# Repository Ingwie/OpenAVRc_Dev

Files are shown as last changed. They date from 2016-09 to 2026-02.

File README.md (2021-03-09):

# OpenAVRc_Dev
This is the source code / documentation part of OpenAVRc. For hardware / addons visit : https://github.com/Ingwie/OpenAVRc_Hw 

**Welcome to**
=========
                 ____                ___ _   _____                      
                / __ \___  ___ ___  / _ | | / / _ \____                 
               / /_/ / _ \/ -_) _ \/ __ | |/ / , _/ __/                 
               \____/ .__/\__/_//_/_/ |_|___/_/|_|\__/                  
                   /_/                                                  
              
              =========================================
----------
                     Based on code(s) named :                       
             OpenTx - https://github.com/opentx/opentx                  
             Deviation - https://www.deviationtx.com/                   
                                                                        
                Only AVR code here for visibility ;-)                   
----------
   OpenAVRc is free software: you can redistribute it and/or modify    
   it under the terms of the GNU General Public License as published    
   by the Free Software Foundation, either version 2 of the License,   
   or (at your option) any later version.

   OpenAVRc is distributed in the hope that it will be useful,         
   but WITHOUT ANY WARRANTY; without even the implied warranty of       
   MERCHANTABILITY or FITNESS FOR A PARTICULAR PURPOSE.  See the        
   GNU General Public License for more details.                         
                                                                        
>        License GPLv2: http://www.gnu.org/licenses/gpl-2.0.html          

----------

   Stay tuned

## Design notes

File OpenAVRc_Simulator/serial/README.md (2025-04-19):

# uart

code interface between std function and user for Windows and Linux

## Warning:
After many docs read, i think you should never read msdn, and never do something with Windows, but i did it.

## Example:
```C
#include "lib/uart/uart.h"

int main ( void )
{
	uartHandler uart = 0; // uart handler
	char busName[ 64 ] = { 0 }; // bus name /dev/ttyACMx or COMx
	uint8_t buffer[  1024 ] = { 0 }; // buffer for data

	...
		
	uart = uartOpen ( busName, O_RDWR );

	if ( !uartValide( uart ) )
	{
		printf ( "can't open %s\n", busName );
		return ( __LINE__ );
	}

	uartWrite ( uart, buffer, bufferSizeMax );

	uartRead ( uart, buffer, bufferSizeMax );

	uartClose ( uart );

	return ( 0 );
}
```

## Polling read:
```C
#include "lib/uart/uart.h"

int main ( void )
{
	uint8_t buf[ 256 ] = { 0 };
	char busName[ 64 ] = { 0 }; // bus name /dev/ttyACMx or COMx

	...

	uartHandler uart = uartOpen ( busName, O_RDWR );

	if ( !uartValide ( uart ) )
	{
		return ( __LINE__ );
	}

	if ( uartInit ( uart, 115200, UART_DATA_8 | UART_PARITY_N | UART_STOP_1 ) )
	{
		return( __LINE__ );
	}

	// set non blocking read mode
	uartSetReadTimeout ( uart, 0, 0 );

	do
	{
		if ( uartRead ( uart, buf, 1 ) )
		{ // if read a byte
			printf ( "%x\n", *buf );
		}

		Sleep ( 10 );
	}
	while ( 1 );

	uartClose ( uart );

	return ( 0 );
}
```

For Windows in the function `int uartSetReadTimeout ( uartHandler bus, uint8_t time, uint8_t min );` 
 - if you want a non blocking mode: set time and min to zero,
 - if you want a timed mode: set time upper than zero and min to zero, 
 - if you want a blocking mode: set time to zero and min to 1

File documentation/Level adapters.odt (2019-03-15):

Wiring Adapters SPI

Version 0.1

Copyright OpenAVRc 2018

# 1 Document version

Version | Date | Reason for update
0.1 | 11/10/2018 | Creation

# 2 Copyright

This document is Copyright © 2018 OpenAVRc.

# 3 Caution

The OpenAVRc team is not responsible for damages that may arise from the misuse or possible malfunction of the OpenAVRc transmitter.

It is therefore up to the end user to measure, assume the risks and comply with the legislation in force depending on the country of use.

# 4 Table of content

## 5 Modules HF :

### 5.1 Module HF cc2500 yellow:

If you only use FrSky receivers, prefer the following CC2500 module or equivalent.

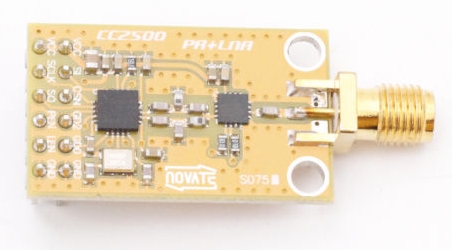
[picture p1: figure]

Yellow cc2500 HF Module Wiring :

The input outputs only accept 3.3v signals. It is ESSENTIAL to separate this module from the Core using a 4-channel converter (MOSI, MISO, CS, SCLCK) which receives 0-5v level signals and converts them into 0-3,3v level signals. and vice versa for the MISO signal.

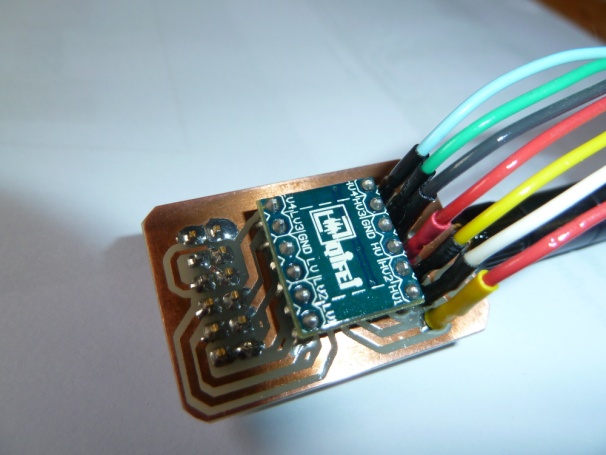
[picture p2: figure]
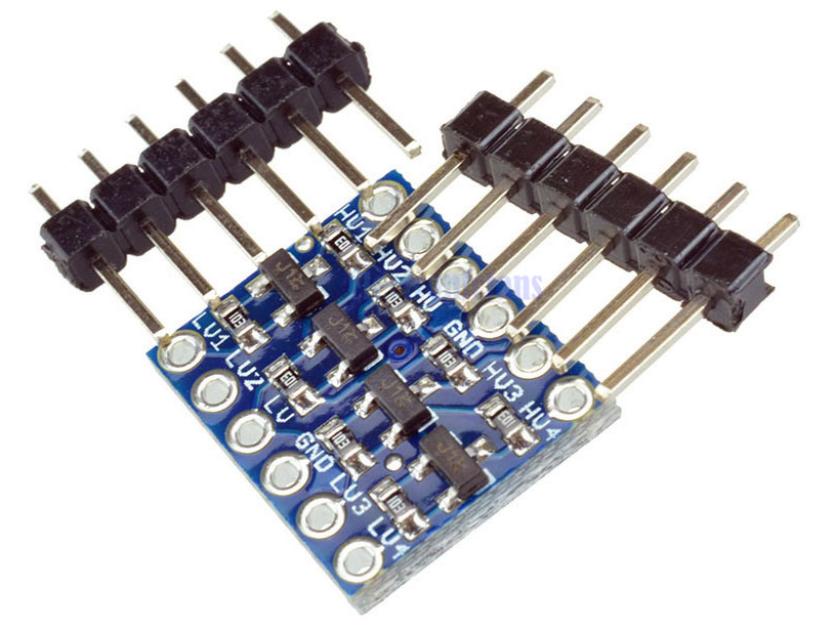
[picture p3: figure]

This circuit board will allow adaptation in a reduced format. It is connected to P7 (see p14).

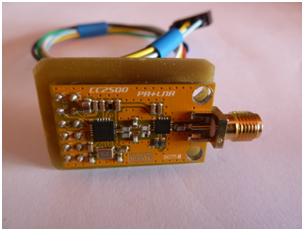
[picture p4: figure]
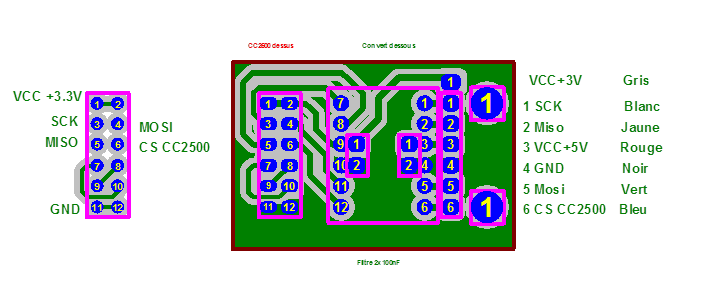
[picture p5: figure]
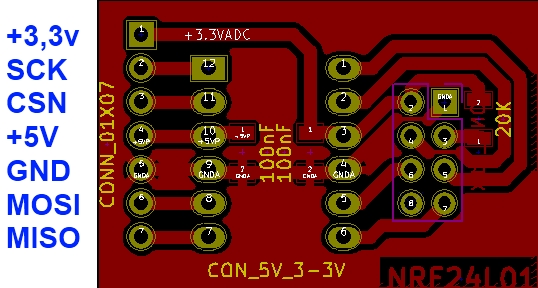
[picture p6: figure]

### 5.2 Module HF nrf24l01 :

### 5.3 Module HF a7105 :

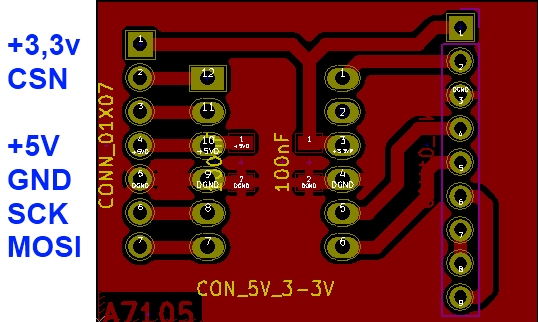
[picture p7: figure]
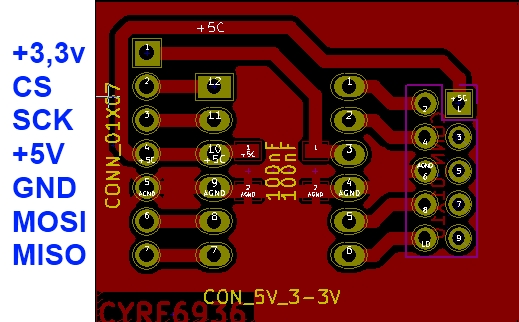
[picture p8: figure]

### 5.4 Module HF cyrf6936:

La documentation de LibreOffice est disponible sur www.libreoffice.org

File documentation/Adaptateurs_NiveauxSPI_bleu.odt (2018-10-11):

Câblage Adaptateurs SPI

Version 0.1

Copyright OpenAVRc 2018

# 1 Version du document

Version | Date | Raison de l’évolution
0.1 | 11/10/2018 | Création

# 2 Copyright

Ce document est Copyright © 2018 OpenAVRc.

# 3 Avertissement

L’équipe OpenAVRc n’est aucunement responsable des dommages qui pourraient découler de la mauvaise utilisation ou d’un éventuel dysfonctionnement de l’émetteur OpenAVRc.

Il appartient donc à l’utilisateur final d’en mesurer, d’en assumer les risques et de respecter la législation en vigueur selon le pays d’utilisation.

# 4 Tâble des matières

## 5 Modules HF :

### 5.1 Module HF cc2500 jaune :

Si vous n’utilisez que des récepteurs FrSky, préférez le module CC2500 suivant ou un équivalent.


Câblage du module HF cc2500 jaune :

Les entrées sorties n’acceptent que des signaux 3,3v. Il est donc IMPERATIF de séparer ce module du Core à l’aide d’un convertisseur 4 voies (MOSI, MISO, CS, SCLCK) qui reçoit des signaux de niveaux 0-5v et les convertit en signaux de niveaux 0-3,3v et inversement pour le signal MISO.


Ce circuit imprimé permettra l’adaptation sous un format réduit. Il est connecté sur P7 (voir p14).


### 5.2 Module HF nrf24l01 :

### 5.3 Module HF a7105 :


### 5.4 Module HF cyrf6936:

La documentation de LibreOffice est disponible sur www.libreoffice.org

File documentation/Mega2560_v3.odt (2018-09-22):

Document de câblage d’une carte Arduino mega2560 R3

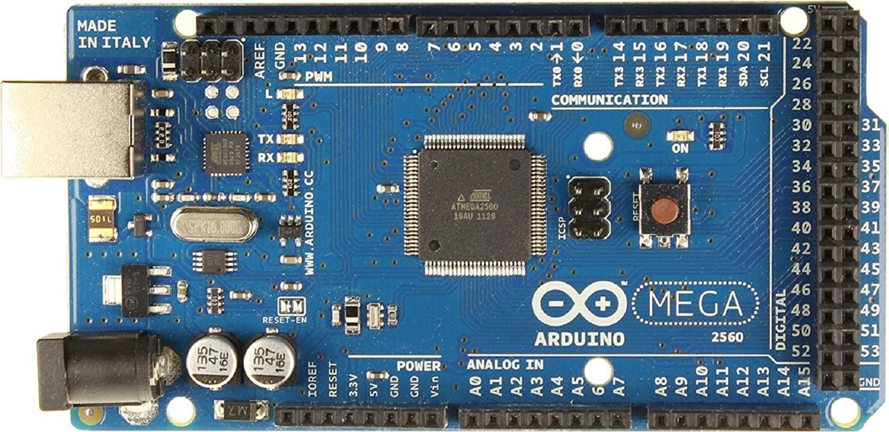
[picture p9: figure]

Table des matières

### Affectations des connecteurs:

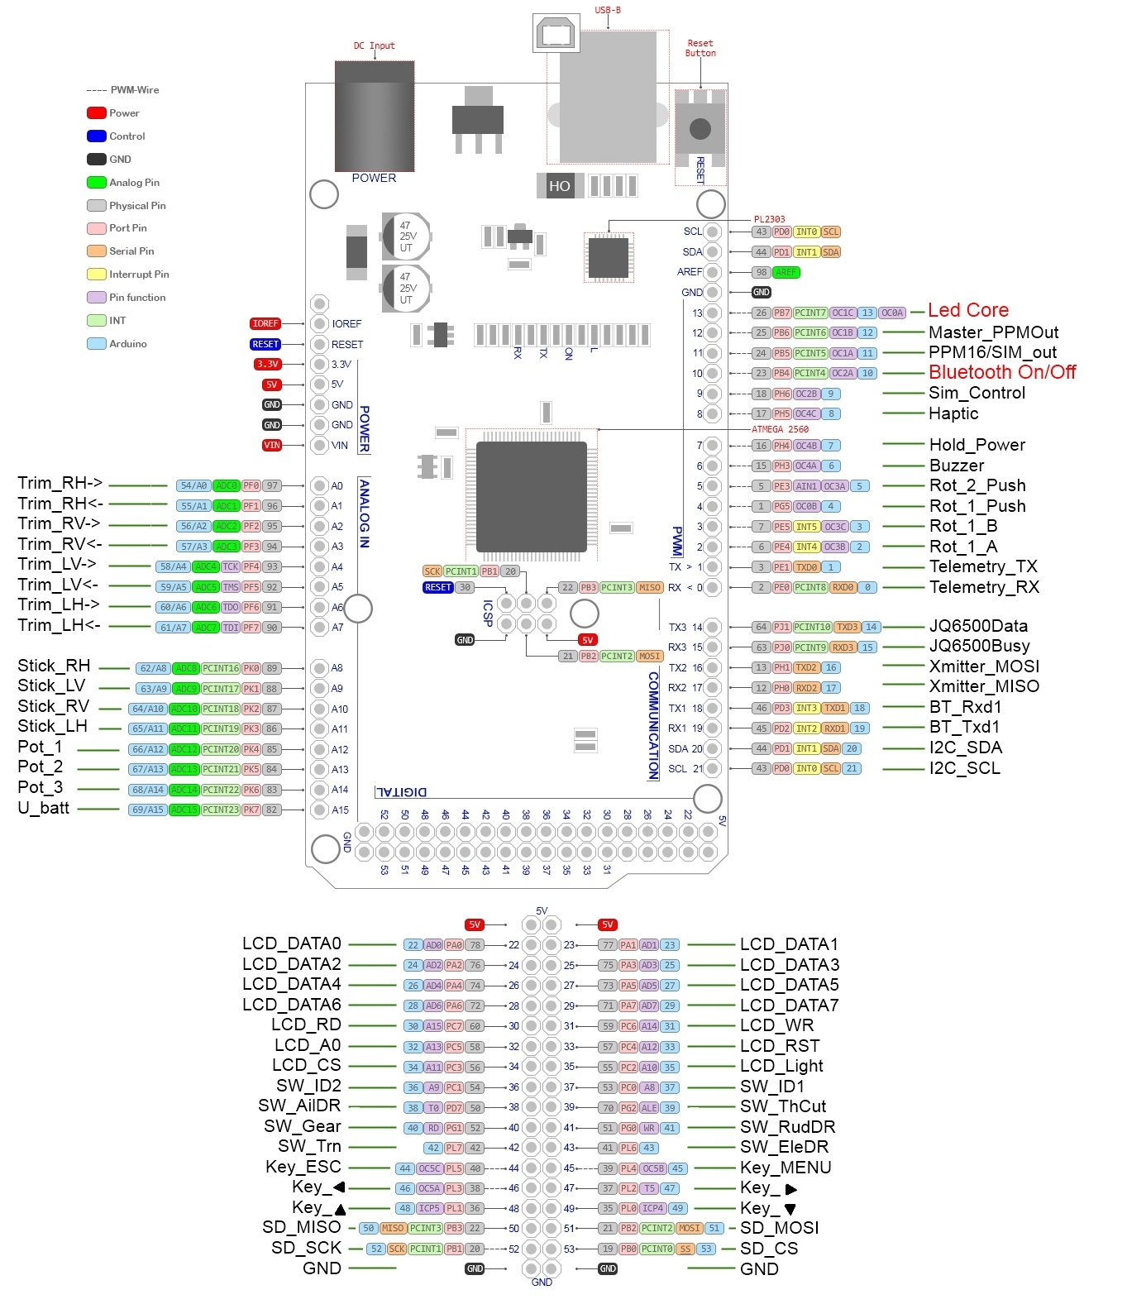
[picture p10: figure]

### Câblage des connecteurs :

#### Manches :

Les quatre manches sont connectés aux pins A8,A9,A10 et A11, ainsi que le +5v et la masse GND.

Les manches à effet hall seront alimentés par du 3,3v au lieu du 5V.

#### Potentiomètres P1 , P2 et P3 :

Les trois potentiomètres sont connectés aux pins A12,A13 et A14.

#### Ecran LCD parallèle ST7920 :

L’écran est connecté sur les pins 22 à 35 .

Pour tout autre écran connecté en parallèle, Zolen, Artronic, KS108, voir en fin de document .

#### Connecteur ICSP :

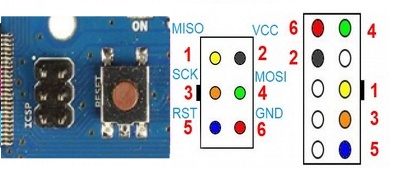
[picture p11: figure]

#### Connexion des Trims :

Les trims sont connectés sur les pins A0 à A7 et la masse GND.

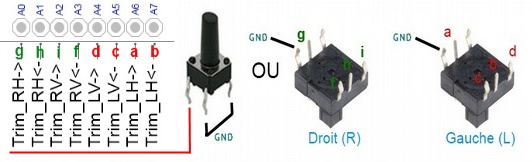
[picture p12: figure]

#### Connexion des Interrupteurs :

Les interrupteurs sont connectés sur les pins 36 à 43 et la masse GND.

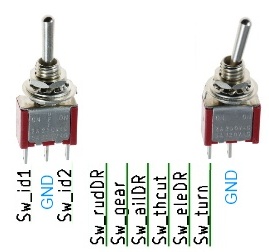
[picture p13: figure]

#### Alimentation (LIPO) :

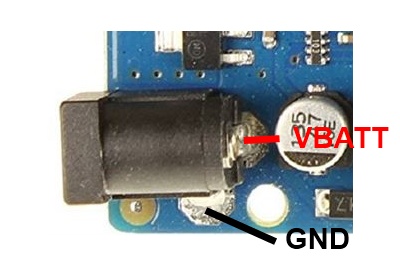
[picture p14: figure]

Un accus LiPo ou mieux : Li-Ion 2S type (2 x 4,2v maximum) sera utilisé pour alimenter la carte.

VBATT alimente aussi le module HF.

Un pont diviseur de tension doit être câblé entre VBATT et GND. Son point milieu devra être connecté à la pin A15.

#### Connexion des touches :

Les touches sont connectées sur les pins 44 à 49 et la masse GND.

#### Connecteur Marche-Arrêt, télémesure et sortie PPM vers module HF:

#### Connexion carte SD (8GB maximum):

La carte SD est connectée sur les pins 50 à 53 ainsi que sur le +5V et la masse GND.

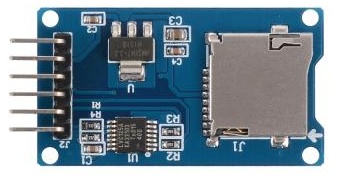
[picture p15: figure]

#### Connexion encodeurs :

Seul l’encodeur Ena est disponible pour l’instant. Il est connecté sur les pins 2,3,5 et GND.

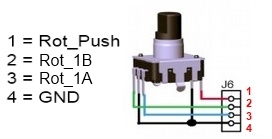
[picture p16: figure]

#### Connexion du vibreur :

Le vibreur est connecté sur la pin 8 et la masse GND.

Comme pour tout moteur continu, il faut absolument câbler une diode de type 1n4148 en parallèle sur le vibreur . La cathode sur la sortie 8 et l’anode sur le GND.

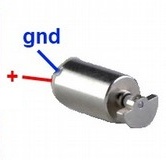
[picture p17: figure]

#### Connexion écran LCD_I2C : (SSD1306 ou SH1106)

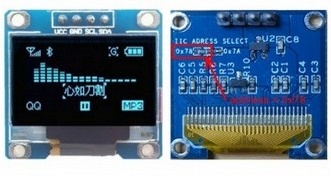
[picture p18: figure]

En cas d’utilisation d’un écran I2C, il sera connecté sur les pins 20 (sda) et 21 (scl) ainsi que sur le +5V et la masse GND.

Vérifier que l'adresse de l'écran est bien 0x78 (correspond à l’adresse d’écriture 0x3C )!!!

#### Câblage module télémétrie, conversion TTL/RS232 :

#### Connexion amplification Audio-Buzzer / Voice :

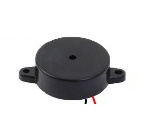
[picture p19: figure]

Il existe deux possibilités d’utilisation de la pin 6 (Out Audio-Buzzer).

- soit raccorder directement un buzzer entre la pin 6 et la masse GND et désactiver la fonction « Audio » dans « Desktop ».

Dans ce cas, le buzzer sera utilisé pour signaler toute action effectuée sur une touche ou indiquer une alarme, selon la configuration choisie dans la radio pour cette fonction.

- soit utiliser la fonction « Audio » dans « Desktop et raccorder la pin 6 sur l’une des deux entrées d’un ampli 2w décrit plus loin, et dont le circuit imprimé est illustré par ailleurs.

Ce mode d’utilisation est, à notre avis, le plus judicieux,

Dans ce cas, la pin 6 génère un signal Buzzer simulé ainsi que les sons de la fonction « Audio » provoqués par l’appui sur une touche, une commande de trim, etc, selon le choix effectué dans la radio.

Dans tous les cas, si la fonction « Voice » est cochée dans « Desktop » (annonces vocales par fonction « Voice »), voir plus bas le câblage du module Voice JQ6500 .

Ampli sommateur

Il faudra réaliser un montage sommateur des signaux Audio-Buzzer / Voice avant amplification des signaux vers un haut-parleur 8 ohms.

Si vous ne souhaitez pas profiter de la fonction « Audio » et utiliser un buzzer seul, («Audio» décoché dans Desktop), tout en utilisant la fonction Voice («Voice» coché dans Desktop), seul le raccordement au JQ ( broche 27 ) sera nécessaire et vous n’aurez pas besoin de la partie sommateur.

En option, un jack (embase jack mono 3,5mm) peut être ajouté pour brancher une oreillette.

La résistance de 220 Ohms sera adaptée à votre audition. L’idéal sera dans un premier temps d’utiliser une résistance variable de 1Kohms pour trouver votre réglage idéal, puis de remplacer cette résistance par une résistance fixe de valeur approchante.

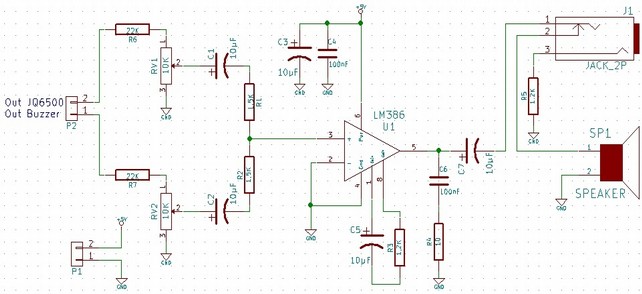
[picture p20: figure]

Schéma de la partie sommateur + ampli LM386.

Note : Les références des composants n’ont rien à voir avec celle du shield.

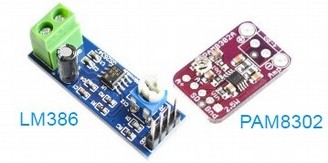
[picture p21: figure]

Vous pouvez aussi réaliser votre adaptation en utilisant des amplificateurs audio du commerce, à base de LM386 ou PAM8302 (classe D) ou tout autre ampli mono.

Une puissance de 2w est suffisante.

#### Câblage du module son JQ6500-28P :

Vous utiliserez ce module si vous souhaitez bénéficier des annonces vocales de la fonction

« Voice », pour indiquer des temps de vol, des valeurs de télémesure, la phase de vol sélectionnée,

la tension batterie émetteur, etc. Les annonces vocale seront stockées dans la mémoire micro SD du

module.

Le module JQ6500-28P (28 pins) arrive avec deux barrettes de 14 pins déjà soudées.

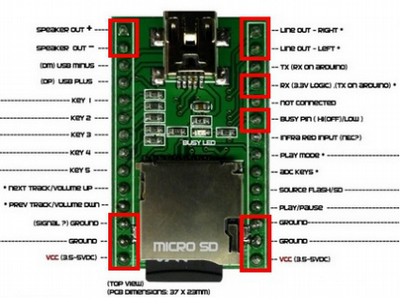
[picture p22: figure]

Pour être utilisé correctement, le module doit être préparé.

Cette préparation consiste à garder les pins entourées en rouge et couper au plus court toutes les autre pins.

Une autre solution peut consister à complètement dessouder les pins non utilisées, ainsi il n’y aura aucun risque qu’une broche non utilisée touche une piste du shield !

Le module sera alors monté côté soudures du shield (dessous) et les soudures réalisées côté composants (dessus). Il faudra prendre soin de câbler au préalables les quatre composants se trouvant en dessous du JQ6500-28P , soit R15,R20 et C22,C32.

#### Connexion du module RTC DS3231 et FRAM référence FM24W256-G :

(FM24W256-G à tester)

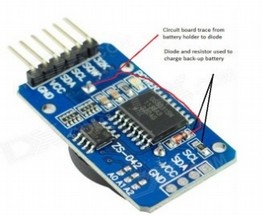
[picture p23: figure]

Ce module, que l'on peut trouver un peu partout sur lequel est mentionné ZS-042 supporte l'horloge DS3231 mais aussi une Eeprom AT24C02.

Il va falloir remplacer cette Eeprom par une FRAM Ramtron-FM24W256-G, qui remplacera l'Eeprom interne de l'atmega2560.

La Fram utilise le même boîtier broche à broche.

Afin d'utiliser tout son espace mémoire, (bien supérieur à celui de l'eeprom AT24C02), il est nécessaire de court-circuiter les ponts, A0, A1 et A2, situés à droite du circuit sur la vue.

Ses avantages, plus d’espace mémoire, plus rapide et plus grande résistance aux multiples écritures.

Ce module se branche sur les pins I2C, 20 (sda et 21 (scl) ainsi que sur le +5V et la masse GND.

Détail TRES important, le module est presque toujours fourni avec une pile lithium CR2032.

Or, le module prévoit une charge de cette pile ce qui n'est possible qu’avec une pile accus de type LIR2032.

Il y a un risque de voir exploser la pile !

Si vous voulez malgré tout utiliser un simple pile CR2032, il suffira de dessouder par exemple la diode (composant orange) .

#### Connecteur écolage :

##### Ecolage par câble :

#### Préparation des écrans :

##### Zolen (ST7565P) :

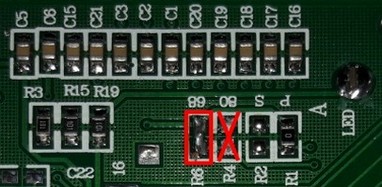
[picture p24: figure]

Dessouder R4 (8080).

Souder R6 (6800).

Choisir ST7565P dans Desktop.

Alimentation en 5V.

###### Adaptation du connecteur P16 au pin out du Zolen :

1 | 2 | 3 | 4 | 5 | 6 | 7 | 8 | 9 | 10 | 11 | 12 | 13 | 14 | 15 | 16 | 17 | 18 | 19 | 20
| 10 | 9 | NC | NC | 1 | 2 | 3 | 4 | 5 | 6 | 7 | 8 | 16 | 15 | 14 | 13 | 11 | NC | 12

Pour alimenter la led de rétro éclairage, une résistance de 100ohms sera câblée entre la pin 18 de P16 et la pin 11 de l’écran.

##### Artronic :

Choisir ST7565R dans Desktop.

Alimentation en 3,3V.

###### Adaptation du connecteur P16 au pin out du Artronic:

1 | 2 | 3 | 4 | 5 | 6 | 7 | 8 | 9 | 10 | 11 | 12 | 13 | 14 | 15 | 16 | 17 | 18 | 19 | 20

##### ST7920 :

Choisir ST7920 dans Desktop.

Alimentation en 5V.

Cet écran est prêt à être câblé.

###### Adaptation du connecteur P16 au pin out du ST7920:

1 | 2 | 3 | 4 | 5 | 6 | 7 | 8 | 9 | 10 | 11 | 12 | 13 | 14 | 15 | 16 | 17 | 18 | 19 | 20

##### KS108 :

CS1 et CS2 sont parfois à inverser.Pour alimenter la led de rétro éclairage, une résistance de 100ohms sera câblée entre la pin 19 de P16 et la pin 19 de l’écran.

Choisir KS108 dans Desktop. Alimentation en 5V.

###### Adaptation du connecteur P16 au pin out du KS108:

1 | 2 | 3 | 4 | 5 | 6 | 7 | 8 | 9 | 10 | 11 | 12 | 13 | 14 | 15 | 16 | 17 | 18 | 19 | 20
1 | 2 | NC | NC | 16 | 6 | 7 | 8 | 9 | 10 | 11 | 12 | 13 | 14 | 15 | | 17 | | 19

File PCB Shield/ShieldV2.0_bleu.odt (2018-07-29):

Manuel Utilisateur

Version 0.1

Document de câblage du shield pour un Mini MegaCore 2560


Ce shield est prévu pour recevoir le mini mega2560 de Inhaos (http://www.inhaos.com/product_info.php?products_id=118)


Conseil :

Nous vous suggérons de lire et relire ce document ainsi que le document « Firmware OPENAVRc 3.0 » et de vous en imprégner avant la réalisation.

Préférez une réalisation « fonction par fonction » et tester et vérifier le bon fonctionnement avant de passer à la phase suivante.

Ordre de réalisation suggéré :

- Alimentations et connecteurs manches
- Amplificateur des manches (si cette option est retenue)
- Fram (option fortement suggérée), U1 (si écolage)
- Horloge RTC (si souhaitée)
- Mise en place des différents connecteurs
- Ecran et circuit Core

A ce stade, vous pouvez alors mettre en route votre radio après avoir exploité le document « Compilez votre firmware OPENAVRc 3.0 »

- Carte SD

- JQ6500
- etc

Copyright OpenAVRc 2018

# 1 Version du document

Version | Date | Raison de l’évolution
0.1 | 29/07/2018 | Mise a jour de la V2.0

# 2 Copyright

Ce document est Copyright © 2018 OpenAVRc.

# 3 Avertissement

L’équipe OpenAVRc n’est aucunement responsable des dommages qui pourraient découler de la mauvaise utilisation ou d’un éventuel dysfonctionnement de l’émetteur OpenAVRc.

Il appartient donc à l’utilisateur final d’en mesurer, d’en assumer les risques et de respecter la législation en vigueur selon le pays d’utilisation.

# 4 Tâble des matières

# 5 Câblage des modules et affectations des connecteurs:

Face Avant


Face Arrière


!!! ATTENTION !!!

Les composants marqués d’une croix ne doivent pas être câblés !!!!

## 5.1 Alimentation générale (LIPO) :

Un accu LiPo ou mieux : Li-Ion 2S type (2 x 4,2v maximum) sera utilisé pour alimenter la carte.

## Câblage des Alimentations +5 et +3.3V :

### 5.1.1 Solution1– L4940 ou 4941:

Cette première solution utilise un régulateur série 5v L4940 dont le rendement est bien mois bon que les deux solutions suivantes. Le boîtier de type TO220 trois pattes sera câblé entre les pattes 2 et 4 de U4.

En cas de besoin de 3,3v U5 devra être câblé.

### 5.1.2 Solution 2 (PM-5033) :


Ici, Le 5v ET le 3,3v sont créés par le PM-5033 de Inhaos (U4).

Très bon rendement de 96%, bien

supérieur au L4940 de la solution 1, donc moins de dissipation thermique et une plus grande autonomie de la batterie.

Ne pas câbler U5 (3,3v).

### 5.1.3 Solution 3a (mp1584em) :


Cette dernière solution utilise un module DC/DC (alimentation à

découpage, en lieu et place du PM-5033 (U4).

Très bon rendement aussi de 96%,

!!!!ATTENTION !!!!

Il est impératif de régler ce module à +5v maximum avant de le souder sur le circuit au risque de détruire les composants actifs qui eux ne supporteraient pas plus de 5V.

Réglage de la tension de sortie :

- Remplacer la résistance variable par une résistance fixe de 47Kohms en parallèle avec une résistance de 1Mohms.

Pour cette valeur la tension de sortie est alors de 4,97V.

Vérifier que la tension ne dépasse pas 5v car sinon l’écran SD1306 I2c ne démarrera pas.

En cas de besoin de 3,3v, U5 sera câblé.

### 5.1.4 Solution 3b (mp1584em) :

Tout comme le module PM-5033, ce module possède une broche enable (patte 2) qui par défaut force le mp1584em à démarrer dès qu’il est alimenté.

Pour que ce module démarre ou puisse s’éteindre par la touche exit, il suffit de dessouder la résistance entre les pattes 2 et 7 (croix rouge), puis souder une résistance de 100K sur la patte 2 du module, l’autre côté de cette résistance étant reliée à la patte 1 de U4.

Sur le circuit imprimé, les résistances R41 et R43 ne seront pas soudées.

En cas de besoin de 3,3v, U5 sera câblé.

## 5.2 Câblage des connecteurs

### 5.2.1 Manches P12 et P13:

Il est possible de retourner le connecteur de chaque potentiomètre afin d’inverser le sens de variation.

IMPORTANT :

Pour un réglage correct il faut que la tension augmente lorsque le manche est actionné de gauche à droite ou de bas en haut.

Dans le cas d’utilisation d’un ampli, le signal étant inversé, il faudra en tenir compte.

Ce point sera repris lors des réglages.

Par défaut, le shield est préréglé pour des manches avec des potentiomètres.

Dans ce cas là, l’alimentation des manches ce fera en 5V.

Il existe des manches avec capteurs à effet hall. Dans ce cas là, les manches seront alimentés en 3,3V.

Il sera aussi nécessaire de remplacer deux résistances par voie.

(Voir pages 20 « Amplification Manches P12 et P13: 5v/3,3v »).

### 5.2.2 Potentiomètres P1 , P2 et P3 :

Il est possible de retourner le connecteur de chaque potentiomètre afin d’inverser le sens .

### 5.2.3 Ecran LCD parallèle P16 :


Pour tout autre écran connecté en parallèle, Zolen, Artronic, KS108, voir en fin de document .

### 5.2.4 Connecteur ICSP P9 :


### 5.2.5 Connecteur des Trims P11:


### 5.2.6 Connecteur des Interrupteurs P14 :


### 5.2.7 Connecteur touches P25 :

Chaque touche sera connectée entre

l’une des pattes 3 à 8 et la masse (GND).

### 5.2.8 Connecteur P19, Marche-Arrêt, télémesure et sortie PPM vers module HF:


### 5.2.9 Connecteurs des encodeurs rotatifs P23 et P24:


### 5.2.10 Connecteur du vibreur P5 :


### 5.2.11 Connecteur écran LCD_I2C P15 : (SSD1306 ou SH1106)


Vérifier que l'adresse de l'écran est bien 0x78 (correspond à l’adresse d’écriture 0x3C )!!!

### 5.2.12 Connecteur Horloge DS3231 P2:

Ce connecteur est une option pour connecter un module horloge DS3231

uniquement si celui-ci n'est pas déjà placé sur la carte.

En cas d'implantation sur le shield, ce connecteur peut servir à toute option I2C.

### 5.2.13 Câblage du module télémesure, conversion TTL/RS232 P20:

Ce module à base de Max3232 possède deux convertisseurs, un par face. Seul celui côté Max3232 sera utilisé.

Le module possède 4 perçages de petit diamètre pour les

alimentations VCC et GND.

Pour son câblage, je vous conseille de souder deux

barrettes de 4 pins en centrant les pins sur les perçages ainsi que les centres des pins cms sans les percer car cela engendrerait un court-circuit avec la pin cms du dessus.


Soudez deux connecteurs femelles sur le shield , puis enfichez le module et ses connecteurs comme précisé (pins 1 et 8 vers le bas).

Cette solution de câblage, prévu pour une télémétrie FrSky, permettra de remplacer facilement ce module par un autre type de montage pour un autre format de télémétrie.

Note : Si vous utilisez un module FrSky DHT, une variante consistant à supprimer le convertisseur TTL/RS232 interne au module et celui-ci, qui devient inutile, est possible (voir plus loin en annexe)

A noter que dans ce cas, une mise à jour du firmware du module HF n’est plus possible.

Si vous souhaitez le passer en version EU, cette opération est à faire au préalable.

### 5.2.14 Connecteur carte SD (8GB maximum) P6:

La carte SD est connectée sous le core.

L’idéal sera de dessouder le connecteur coudé et le remplacer par un connecteur droit soudé par le dessous de la carte SD.

### 5.2.15 Connecteur d’amplification des signaux Audio-Buzzer / Voice P8 :

Résumé des possibilités :

Sans fonction Audio dans Desktop

Dans ce cas, le buzzer raccordé entre 1 et 4 sera utilisé pour signaler toute action effectuée sur une touche ou indiquer une alarme, selon la configuration choisie dans la radio pour cette fonction.

- Si la fonction « Voice/JQ6500 » est activée dans « Desktop », la broche 2 fournit un signal en provenance du JQ pour les annonces vocales.

Avec Fonction Audio dans Desktop

Ce mode d’utilisation est à notre avis, le plus judicieux,

Dans ce cas, la sortie 1 génère un signal Buzzer simulé ainsi que les sons de la fonction « Audio » provoqués par l’appui sur une touche, une commande de trim, etc, selon le choix effectué dans la radio.

Comme précédemment, si la fonction « Voice/JQ6500 » est cochée dans « Desktop », la broche 2 fournit un signal en provenance du JQ6500-28P pour les annonces vocales.

Il faudra utiliser un ampli (2w) décrit plus loin, et dont le circuit imprimé est illustré par ailleurs et qui peut être fourni, pour mélanger les signaux Audio et Voice pour envoi au haut parleur 8 ohms.

Ampli sommateur (CI disponible)

Il faudra réaliser un montage sommateur des signaux Audio-Buzzer et Voice avant amplification des signaux vers un haut-parleur 8 ohms.

Si vous ne souhaitez pas profiter de la fonction « Audio » et utiliser un buzzer seul, («Audio» décoché dans Desktop), tout en utilisant la fonction Voice («Voice» coché dans Desktop), seul le raccordement au JQ (broche 2) sera nécessaire et vous n’aurez pas besoin de la partie sommateur.

En option, un jack (embase jack mono 3,5mm) peut être ajouté pour brancher une oreillette.

La résistance de 220 Ohms sera adaptée à votre audition. L’idéal sera dans un premier temps d’utiliser une résistance variable de 1Kohms pour trouver votre réglage idéal, puis de remplacer cette résistance par une résistance fixe de valeur approchante.


Schéma de la partie sommateur + ampli LM386.

Note : Les références des composants n’ont rien à voir avec celle du shield.

Vous pouvez aussi réaliser votre adaptation en utilisant des amplificateurs audio du commerce, à base de LM386 ou PAM8302 (classe D) ou tout autre ampli mono.

Une puissance de 2w est suffisante.

### 5.2.16 Câblage du module son JQ6500-28P P22 :

Vous utiliserez ce module si vous souhaitez bénéficier des annonces vocales de la fonction

« Voice », pour indiquer des temps de vol, des valeurs de télémesure, la phase de vol sélectionnée,

la tension batterie émetteur, etc. Les annonces vocale seront stockées dans la mémoire micro SD du

module.

Le module JQ6500-28P (28 pins) arrive avec deux barrettes de 14 pins déjà soudées.

Pour être monté correctement sur le shield , le module doit être préparé.

Cette préparation consiste à garder les pins entourées en rouge et couper au plus court toutes les autre pins.

Une autre solution peut consister à complètement dessouder les pins non utilisées, ainsi il n’y aura aucun risque qu’une broche non utilisée touche une piste du shield !

Le module sera alors monté côté soudures du shield (dessous) et les soudures réalisées côté composants (dessus). Il faudra prendre soin de câbler au préalables les quatre composants se trouvant en dessous du JQ6500-28P, soit R15, R20 et C22,C32.

### 5.2.17 Câblage du module RTC DS3231 et FRAM référence FM24W256-G P2 :

(FM24W256-G à tester)


Ce module, que l'on peut trouver un peu partout sur lequel est mentionné ZS-042 supporte l'horloge DS3231 mais aussi une Eeprom AT24C02.

Il va falloir remplacer cette Eeprom par une FRAM Ramtron-FM24W256-G, qui remplacera l'Eeprom interne de l'atmega2560.

Ses avantages : plus d’espace mémoire, plus rapide et plus grande résistance aux multiples écritures.

La Fram utilise le même boîtier broche à broche.

Afin d'utiliser tout son espace mémoire, (bien supérieur à celui de l'eeprom AT24C02), il est nécessaire de court-circuiter les ponts, A0, A1 et A2, situés à droite du circuit sur la vue.

Ce module se branche sur le connecteur P2, (VCC,GND,SDA et SCL).

Détail TRES important, le module est presque toujours fourni avec une pile lithium CR2032.

Or, le module prévoit une charge de cette pile ce qui n'est possible qu’avec une pile accus de type LIR2032.

Il y a un risque de voir exploser la pile !

Si vous voulez malgré tout utiliser un simple pile CR2032, il suffira de dessouder par exemple la diode (composant orange) .

Il existe une alternative à ce module externe au shield.


Le circuit imprimé peut en effet recevoir directement les composants DS3231 et Fram, ainsi qu'un connecteur pour connecter la pile CR2032 (sauvegarde de l'heure après extinction).

Dans ce cas là, le module ZS-042 n'est pas nécessaire et P2 est laissé libre pour toute option I2C.

L’empreinte de la Fram accepte les références Ramtron FM24W256-G et Cypress FM24W256-G toutes deux en boîtier SOIC8.

Si le DS3231 est monté sur le shield, il faudra prévoir un support de pile CR2032 quelconque .

### 5.2.18 Connecteur écolage P18:

L’écolage pourra se réaliser de deux méthodes, par câble ou par Bluetooth (non fonctionnel).

Ecolage par câble :

Ecolage par liaison Bluetooth : ( !!! non fonctionnel pour l’instant !!!)

Le module Bluetooth HC05 est configurable en maître ou esclave.

Durant cette configuration, la patte KEY devra être alimentée en VCC .

Le module du professeur sera de préférence configuré en maître et celui de l’élève de préférence en esclave.

Pour une meilleure différenciation des modules, on pourra par exemple convenir que le nom d’un module professeur commence par MAMONNOM (maître) et celui de l’élève par ELMONNOM (élève).

Une led (bleue?) peut être connectée à la patte STATUS. Elle sera alors connectée en série avec une résistance de 180 ohms 1/4w.

## 5.3 Modules HF :

### 5.3.1 Module HF cc2500 jaune :

Si vous n’utilisez que des récepteurs FrSky, préférez le module CC2500 suivant ou un équivalent.

Câblage du module HF cc2500 jaune :

Les entrées sorties n’acceptent que des signaux 3,3v. Il est donc IMPERATIF de séparer ce module du Core à l’aide d’un convertisseur 4 voies (MOSI, MISO, CS, SCLCK) qui reçoit des signaux de niveaux 0-5v et les convertit en signaux de niveaux 0-3,3v et inversement pour le signal MISO.


Ce circuit imprimé permettra l’adaptation sous un format réduit. Il est connecté sur P7 (voir p14).


### 5.3.2 Câblage du module HF 4 en 1 multiprotocoles P7:

Le câblage se fera, de préférence par le dessous (soudures réalisées par dessus).

Le module multi protocoles 4 en 1 est alimenté en 5V. Les entrées sorties n’acceptent que des signaux 3,3v. Il est donc ABSOLUMENT nécessaire de séparer ce module à l’aide d’un convertisseur de niveaux de signaux 5v/3,3v.

Ce convertisseur reçoit des signaux de niveaux 0-5v et les convertit en signaux de niveaux

0-3,3v.

### 5.3.3 Câblage du convertisseur de niveaux 5v/3,3v :

### 5.3.4 Câblage du module HF 4 en 1 :

# 6 Amplification des signaux des manches en 5v, ou 3,3v en option :

Note : Cette option, sans être indispensable, permet une meilleure définition des signaux de voies. car elle utilise toute la plage de mesure du convertisseur analogique numérique de la carte Arduino.

Si cette option n’est pas utilisée, il ne sera pas nécessaire d’implanter l’ampli opérationnel MCP604 ainsi que les différents composants associés que l’on voit sur le schéma ci-dessous.

Il sera alors nécessaire de ponter les quatre empreintes W1 à W4. Vous pouvez passer directement en page 1

## 6.1 Schéma partie Amplification des manches

Quelques explications techniques :

Bien que le convertisseur ne travaille que sur 10 bits (1024 points), le logiciel, par le biais de deux conversions successives, élabore un signal sur 11 bits (0000 à 07FFh) ce qui signifie en théorie que 2048 valeurs différents pourront être appliquées aux servomoteurs.

Ces valeurs sont visualisées dans l’écran « Anas, 6/7 » de l’émetteur, sous forme hexadécimale et en %. La valeur en % n’est significative qu’après la calibration des manches (voir page 17)

Note : Sur l’écran ANAS, les indications des voies Dir, Prf ne sont exactes qu’après adaptation de votre mode de pilotage dans l’écran 1

Les valeurs des composants du schéma sont définies pour une tension de 5v.

Si vous utilisez des manches avec capteurs à effet hall (choisir 3,3v pour leur alimentation), il faudra faire les deux modifications suivantes :

- Remplacer R24 (39kOhms) par une résistance de 82kOhms (rouge sur le schéma).

- Remplacer les résistances R11, R12, R13 et R14 par des résistances de 82kOhms (bleu sur le schéma).

## 6.2 Réglage des amplificateurs d’adaptation des manches :

L’amplification des manches a besoin d’un réglage pour obtenir la plage de tension 0-5V pour la pleine course du manche.

Deux potentiomètres par manches, « centre = RV2, 3, 4, 5 » et « gain =R27, 30, 33, 36 », permettent ce réglage.

Deux méthodes peuvent être utilisées :

### 6.1.1 Méthode 1

- en analogique sans lien avec le fonctionnement de la radio, ce qui permet déjà de valider la partie Manches si vous avez commencé par là.

Affectation des manches

P12 P13

VL HL VR HR

Note : VL = Vertical Left,

HR= Horizontal Right

Commencez de préférence par le manche des gaz (RV en mode 1, LV en mode 2)

Pour le mode 1, Prérégler RV3 et R27 en milieu de course.

A l’aide d’un multimètre :

a) manche au neutre, sur la broche correspondante du circuit Core (Pin 51) mesurer la tension puis régler à environ 2,5v en agissant sur RV2.

Correspondance Manches/N° Broches du Core en mode 1 :

51 | Analog pin 8 | Stick RH | Stick RH_Ailerons
53 | Analog pin 10 | Stick RV | Stick RV_Gaz
54 | Analog pin 9 | Stick LV | Stick LV_Profondeur
56 | Analog pin 11 | Stick LH | Stick_Dérive

b) puis déplacer le manche vers +50%. (à droite pour les manches horizontaux et en haut pour les manches verticaux).

La tension doit augmenter et si ce n’est pas le cas, revoir page 5 et inverser le sens d’alimentation du manche.

Note : Nous avons constaté une grande dispersion des signaux en sortie de potentiomètre.

Régler R27 pour obtenir environ 3,7V avec le manche vers +50%. Si vous ne pouvez pas obtenir cette tension et que votre tension est plus importante, c’est que votre manche présente une variation trop importante du signal et il vous faudra diminuer le gain des amplificateurs en remplaçant R30 (120k) par une valeur plus faible. (47K devrait convenir)

c) Manche au maximum, régler alors la tension à environ 4,90V à l’aide du potentiomètre R27.

d) Vérifier que vous avez environ 0,1V au mini du manche.

Si la variation n’est pas la même dans les deux sens, rien à faire, c’est la linéarité de votre potentiomètre de manche qui est en cause, mais pas grave…le logiciel adaptera ensuite.

Effectuer la même procédure pour les autres manches sans chercher la précision puisque nous réglerons ces valeurs plus finement par la suite.

Au bout du quatrième, vous devriez maîtriser la méthode !

De toute façon, il vous faudra étalonner les manches lors de la mise en route de l’émetteur comme montré sur la vue « Calibration » de la page suivante.

### 6.1.2 Méthode 2

Plus pratique à réaliser, celle-ci ne pourra se faire que si l’émetteur est déjà opérationnel.

- Accéder à l’écran « ANAS » 6/7 de la radio et consulter les valeurs délivrées par chaque manche.

- Au neutre du manche, régler les potentiomètres de zéro pour obtenir 0400(H) points.

- Au mini du manche, régler le potentiomètre de gain pour obtenir 0010(H) du convertisseur.

Vérifier le point maximum : si vos potentiomètres sont linéaires, vous devriez obtenir une valeur proche de 07F0.

Note : Il peut être nécessaire de reprendre le réglage

Ensuite, une fonction de « Calibration » sera effectuée, dont le but est de prendre les valeurs exactes de points du neutre et de chaque sens de chacun des manches, de les affecter de coefficients afin de permettre des calculs précis sur les trims, les mixages, l’affichage, etc, et bien sûr le calcul de la largeur d’impulsions.

Au final, un manche variera de -100% à +100%

Sur la vue suivante, la valeur du manche « Ailerons » est sur fond noir, ce qui montre une saturation du signal, la tension mini du manche est trop faible ce qui montre que le gain est trop important.

# 7 Préparation des écrans :

Zolen (ST7565P) :

Dessouder R4 (8080).

Souder R6 (6800).

Choisir ST7565P dans Desktop.

Alimentation en 5V.

Adaptation du connecteur P16 (ligne du haut) au brochage du Zolen (ligne du bas):

1 | 2 | 3 | 4 | 5 | 6 | 7 | 8 | 9 | 10 | 11 | 12 | 13 | 14 | 15 | 16 | 17 | 18 | 19 | 20
| Vdd | +5V | | | DB0 | DB1 | DB2 | DB3 | DB4 | DB5 | DB6 | DB7 | RD | WR | D | RST | A_ Lcd | | CS
NC | 10 | 9 | NC | NC | 1 | 2 | 3 | 4 | 5 | 6 | 7 | 8 | 16 | 15 | 14 | 13 | 11 | NC | 12

Pour alimenter la led de rétro éclairage, une résistance de 100ohms sera câblée entre la pin 18 de P16 et la pin 11 de l’écran.

Voir également la note de câblage page 27 concernant RV1 et RV6.

Artronic :

Choisir ST7565R dans Desktop.

Alimentation en 3,3V.

Adaptation du connecteur P16 (ligne du haut) au brochage de l’Artronic (ligne du bas):

1 | 2 | 3 | 4 | 5 | 6 | 7 | 8 | 9 | 10 | 11 | 12 | 13 | 14 | 15 | 16 | 17 | 18 | 19 | 20
1 | 15 | 13 | NC | NC | 12 | 11 | 10 | 9 | 8 | 7 | 6 | 5 | 19 | 18 | 20 | 17 | 2 | 1 | 16

ST7920 :

Choisir ST7920 dans Desktop.

Alimentation en 5V.

Il s’agit de RV6 10kohms qui se trouve sur le circuit imprimé

Adaptation de P16 (ligne du haut) au brochage du ST7920 (type 12864B V2,0): (ligne du bas):

1 | 2 | 3 | 4 | 5 | 6 | 7 | 8 | 9 | 10 | 11 | 12 | 13 | 14 | x | 15 | 16 | 17 | 18 | 19 | 20
GND | | +5V | V0 | V out | DB0 | DB1 | DB2 | DB3 | DB4 | DB5 | DB6 | DB7 | RD =E | PSB | RW | RS | RST | Bla LCD | Blk Lcd
1 | NC | 2 | 3 | 18 | 7 | 8 | 9 | 10 | 11 | 12 | 13 | 14 | 6 | 15 | 5 | 4 | 17 | 19 | 20 | NC

Note : Les pattes 2 et 15 (PSB) de l’écran sont connectées ensemble aux +5V.

Différents types d’écran st7920 existent. Si une résistance R9 (0 ohm) existe, elle est connectée au +5V pour définir l’écran en mode parallèle.

KS108 :

CS1 et CS2 sont parfois à inverser.Pour alimenter la led de rétro éclairage, une résistance de 100ohms sera câblée entre la pin 19 de P16 et la pin 19 de l’écran.

Choisir KS108 dans Desktop. Alimentation en 5V.

Adaptation du connecteur P16 au brochage du KS108:

1 | 2 | 3 | 4 | 5 | 6 | 7 | 8 | 9 | 10 | 11 | 12 | 13 | 14 | 15 | 16 | 17 | 18 | 19 | 20
3 | 20 | 4 | 5 | NC | 9 | 10 | 11 | 12 | 13 | 14 | 15 | 16 | 8 | 1 | 6 | 17 | 19 | 20 | 2

# 8 Annexe :

## 8.1 Suppression du convertisseur TTL/RS232 du module FrSky DHT.

Suppression du convertisseur TTL/RS232 du module FrSky DHT.

Le module DHT incorpore d’origine un convertisseur RS232 < > TTL sur la liaison télémesure.

Cette liaison est également utilisée pour la mise à jour du firmware du module.

Si l’on ne souhaite plus mettre à jour ce module (il n’y aura plus de nouvelles versions de toute façon) il est judicieux de supprimer ce convertisseur, ce qui permettra donc de relier directement ces signaux aux entrés sorties de télémesure et évite le câblage du convertisseur RS232/TTL décrit en page 7 de ce document.

Au final, l’opération est relativement simple :

Repérer les points de sortie Tx et Rx de la carte

- Sur le circuit imprimé, couper les deux pistes arrivant sur ces deux points
- (les deux traits jaunes près de C21 et R19)
- Raccorder directement Tx et Rx aux points indiqués sur la vue suivante
- Il faudra bien sûr ponter les connexions qui ne sont plus réalisées par le convertisseur sur la carte en raccordant les points suivants :
- Note : La liaison en bleu dans la ligne réception est une résistance de 220 ohms

# 9 Implantation des composants :

Les composants marqués d’une croix ne doivent pas être câblés.

Modifications apportées au projet :


# 10 Modifications a réaliser

## 10.1 Modification du circuit imprimé :


Afin de déplacer la lecture de +BATT derrière la diode D6 il faut :

- couper la piste côté composants arrivant sur P21 (double trait vert).

- réaliser une connexion entre +BATT et IN+ .

## 10.2 Autre modifications :

- déplacement de la lecture de la tension de la batterie (coupure CI)

- ne pas câbler la diode D2 (risque de court-circuit sur les lignes PPM).

- souder BT1 (connecteur pile horloge) côté soudures avec un connecteur coudé sortant sous le JQ6500 (attention aux court-circuits avec les pins du core).

- ajouter une résistance de 220 ohms en série dans la ligne MISO du module SD CATALEX (résolution programmation avec interface USBAsp).


- si votre port I2C ne fonctionne pas (la F-Ram, l’horloge DS3231 et le SSD1306 l’utilisent),cela peut provenir du DS3231 défectueux. Dans ce cas, soulevez les pattes 15 et 16 (sda et scl).

- D1 peut être remplacé par une diode signal simple de type LL4148.

- l’empreinte des opto coupleurs TLP290 U2 et U3 n’étant pas assez large, écarter légèrement les pattes permet de mieux les souder.

# 11 Conseils divers :

- Ne câblez votre carte SD que lorsque vous aurez testé toutes les fonctions car elle pourrait vous bloquer l’accès aux F-Ram et à l’horloge en cas de défaillance de l’un d’eux.

- Pour le réglage des 4 manches, il existe 4 plages cms (W1 à W4 côté soudures). Pour ma part j’ai préféré placer ma pointe de multimètre sur les pattes 1,7,8 et 14 du MCP604. Cela évite de retourner le shield.

Autre solution: Se placer sur la broche correspondante du circuit Core pour bénéficier d’un contact “non glissant”, voir page 17

- Certains d’entre vous ont eu des problèmes de faux contacts. Une brosse à dents avec, soit de l’alcool à brûler (ma préférence), soit de l’acétone (un peut fort à mon goût) peut vous aider à bien nettoyer le shield d’éventuelles particules de soudures .

- Si vous utilisez un écran Zolen, RV1 ni RV6 ne sont nécessaires. Il faut tout de même une résistance de 100 ohms minimum à la sortie patte 18 du connecteur LCD P16.

Vous pouvez remplacer RV6 (entre les pattes centre et droite) par cette résistance talon.Si vous laissez malgré tout RV6, il faudra quand même rajouter une résistance de 100 ohms afin de limiter le courant au cas où RV6 soit réglé au minimum (risque de griller le rétro éclairage) ! Utiliser une valeur de 470ohms à 1k maxi en remplacement de la résistance de 20K fournie dans le kit.

- Le PM-5033 n’est pas facile à approvisionner. Le petit convertisseur DC-DC qui est prévu en double implantation du 5v, peut être une solution de remplacement. Il possède aussi une patte enable sur la patte 2 du composant so8 mp1584en. Avant de le souder, il faut absolument dessouder le petit potentiomètre et le remplacer par une résistance de 47k. On obtient alors une tension de 5,18v. Pour l’implanter facilement, souder 4 connecteurs deux points sur le shield (IN+,IN-,OUT+ et OU-), puis soudez aussi 4 connecteurs deux points sous le convertisseur. Soudez ensuite l’ensemble sur les 4 connecteurs du shield par dessus les 3 grosses capacités. (câblage de la patte enable en test).

La documentation de LibreOffice est disponible sur www.libreoffice.org

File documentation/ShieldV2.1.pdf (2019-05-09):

# Câblage du shield MegaMini © Version 2.1

Page 1 | Réalisez votre émetteur OpenAVRc 3.0

# OpenAVRc

# Un émetteur RC Open Source basé sur le microcontrôleur AVR ATMega 2560 de chez ATMEL/Microchip

Copyright OpenAVRc 2018


Ce circuit est prévu pour le mega2560-Core de Inhaos (http://www.inhaos.com/product_info.php?products_id=118)


Page 2 | Réalisez votre émetteur OpenAVRc 3.0

Conseil :
Nous vous suggérons de lire et relire ce document et de vous en imprégner avant la réalisation.
Préférez une réalisation « fonction par fonction » et tester et vérifier le bon fonctionnement avant de passer à la phase suivante.
Ordre de réalisation suggéré
- Alimentations et connecteurs manches
- Amplificateur des manches
- Mise en place des différents connecteurs
- Ecran et circuit Core
A ce stade, vous pouvez alors mettre en route votre radio après avoir exploité le document « Compilez votre firmware OpenAVRc »
- Carte SD
- JQ6500
- etc
Avec le circuit livré câblé, on peut également envisager une seconde méthode, à savoir
- montage de l’alimentation
- montage de l’un des écrans
- mise en place des 3 connecteurs du Core
- configuration du circuit Core sur la base du document « Compilez votre FW »
- mise en place du Core
- mise sous tension ! Et vérification du fonctionnement
- suite du câblage

## 1 Versions du document

Version | | | Date | Raison de l’évolution
0.1 0.2 0.3 0.4 0.5 0.6 0.7 | 31/07/2018 03/10/2018 05/12/2018 11/12/2018 21/12/2018 11/01/2019 09/05/2019 | Création de la V2.1 Ajout résistance 10K sur base de Q3 / Correction sérigraphie LL4148 Avertissement diodes vibreur, Ajout partie alimentation, charte graphique, mise à jour câblage écrans, modifications mineures diverses Modification schéma face arrière p. 6 pour sens des diodes D1,D2 et D3 Ajout recommandation si manches à effet Hall et correction erreur circuit de télémesure avec ajout du schéma Correction d’erreurs et ajout d’explications manches Hall Complément schéma écran 7920 pages 30 et 32

## 2 Copyright

Ce document est Copyright © 2018 OpenAVRc.

## 3 Avertissement

L’équipe OpenAVRc n’est aucunement responsable des dommages qui pourraient découler de la mauvaise utilisation ou d’un éventuel dysfonctionnement de l’émetteur OpenAVRc

Il appartient donc à l’utilisateur final d’en mesurer, d’en assumer les risques et de respecter la législation en vigueur selon le pays d’utilisation.

Charte graphique :

Astuce

Info

Attention

Avertissement 1: Les premiers circuits pré-câblés de la version 2.1 ont été livrés avec les diodes du circuit vibreur câblées à l’envers. (D1, D2 et D3). Il est nécessaire de les inverser si vous voulez utiliser le vibreur. Dans la négative, enlevez-les tout simplement.
Voir le bon sens de montage de ces diodes pages 6 ou 33.
Page 3 | Réalisez votre émetteur OpenAVRc 3.0

Attention

Avertissement 2 : Une erreur de liaison de circuit a été constaté dans la partie télémesure sur les shield version 2.1.
Voir pages 13-14 pour correction. Cette modification n’est pas nécessaire si vous utilisez un circuit HF CC2500 ou multimodule.
Page 4 | Réalisez votre émetteur OpenAVRc 3.0

## 4 Table des matières

Page 5 | Réalisez votre émetteur OpenAVRc 3.0

Page 6 | Réalisez votre émetteur OpenAVRc 3.0

## 5 Câblage des modules et affectations des connecteurs:


Face Avant

Face Arrière

les 3 diodes D1, D2 et D3

Page 7 | Réalisez votre émetteur OpenAVRc 3.0

## 5.1 Schéma de la partie Alimentation :

La partie Alimentation comporte :
- une batterie d’alimentation générale (Lipo, LiFe, NiMh…)
- une diode de protection D6
- un circuit interrupteur constitué de Q3, Q4 avec poussoir de mise en marche P21
- un circuit de mesure de la tension batterie R16 et R17
- un régulateur 5V (3 solutions)
- et éventuellement un régulateur 3,3V si nécessaire pour écran ou manche Hall selon le type d’alimentation 5V que vous choisirez.

## 5.2 Alimentation générale (LI-Ion) :

Un accu LiPo ou mieux, Li-Ion 2S ou 3S (3 x 4,2v maximum) sera utilisé pour alimenter la carte.

Page 8 | Réalisez votre émetteur OpenAVRc 3.0

Circuits des Alimentations +5 et +3.3V :

### 5.2.1 Solution 1 : L4940 ou 4941:

Cette première solution utilise un régulateur série 5v L4940 linéaire dont le rendement est bien moins bon que les deux solutions suivantes. Le boîtier de type TO220 trois pattes sera câblé sur les pattes 2, 3 et 4 de U4.
En cas de besoin de 3,3v (pour manches à effet Hall), U5 devra être câblé.

Attention Sauf à vouloir dissiper un peu de chaleur, il est inutile d’utiliser une 3S dans ce cas de figure !

### 5.2.2 Solution 2 : (PM-5033)

Ici, Le 5v ET le 3,3v sont créés par le PM-5033 de Inhaos (U4).
Très bon rendement de 96%, bien supérieur au L4940 de la solution 1, donc moins de dissipation thermique et une plus grande autonomie de la batterie.
Ne pas câbler U5 (3,3v), un régulateur 3,3V est déjà monté à l’arrière du CI.


### 5.2.3 Solution 3 : (MP1584em)

Cette dernière solution utilise un module DC/DC (alimentation à découpage, en lieu et place du PM-5033 (U4).
Très bon rendement aussi de 96%,

Réglage (éventuel) de la tension de sortie :
- Remplacer la résistance variable par une résistance fixe de 47Kohms en parallèle avec une résistance de 1Mohms. Pour cette valeur la tension de sortie est alors de 4,97V.

En cas de besoin de 3,3v, U5 sera câblé.

Attention | Il est impératif de régler ce module à +5v maximum avant de le souder sur le circuit au risque de détruire les composants actifs qui eux ne supporteraient pas plus de 5V. De plus, l’écran SSD1306 I2c ne démarrerait pas.
Page 9 | Réalisez votre émetteur OpenAVRc 3.0

## 5.3 Câblage des différents connecteurs

5.3.1 Manches P12 et P13:; variation.; qui doivent être alimentés en 3,3V.; voie,

Il est possible de retourner le connecteur de chaque potentiomètre afin d’inverser le sens de

Attention

Pour un réglage correct il faudra que la tension augmente lorsque le manche est actionné de gauche à droite ou de bas en haut.
Dans le cas d’utilisation d’un ampli, le signal étant inversé, il faudra en tenir compte. Ce point sera repris lors des réglages.

Attention

Manches à effet Hall : Il est quasi certain que vous aurez à inverser le sens de variation de l’une des deux voies de chaque manche. Pour cela, surtout n’inversez pas l’alimentation (risque de destruction de l’électronique du capteur) mais utilisez la possibilité d’inversion par logiciel décrite dans le document « Compilez votre FW » (Desktop)

### 5.3.2 Potentiomètres P1 , P2 et P3 :


Il est possible de retourner le connecteur de chaque potentiomètre afin d’inverser le sens .

Page 10 | Réalisez votre émetteur OpenAVRc 3.0

Par défaut, le shield est précâblé pour des manches avec potentiomètres alimentés en 5V. Il existe des manches avec capteurs à effet Hall

Dans ce cas, il sera nécessaire de remplacer une résistance sur le pont diviseur et une par

(Voir pages 22 « Amplification Manches P12 et

### 5.3.3 Ecran LCD parallèle P16 :

Positionner le potentiomètre RV1 comme indiqué sur le schéma (vis vers la droite pour être accessible si vous mettez une nappe). Voir schéma page 5

Pour le détail du raccordement des écrans connectés en parallèle, (Zolen, Artronic, ST7920 et KS108,, voir au chapitre 7, page 26)

Attention | Attention au repérage du connecteur P16 sur la nappe raccordée
| (2,1,4,3, etc) Voir chapitre 7

### 5.3.4 Connecteur ICSP P9 :

### 5.3.5 Connecteur des Trims P11:


Page 11 | Réalisez votre émetteur OpenAVRc 3.0

### 5.3.6 Connecteur des Interrupteurs P14 :


### 5.3.7 Connecteur touches P25 :


Chaque touche sera connectée entre l’une des pattes 3 à 8 et la masse (GND).

### 5.3.8 Connecteur P19, télémesure et sortie PPM vers module HF:


Attention
Voir le schéma de cette partie en page 13 pour plus d’explications
Page 12 | Réalisez votre émetteur OpenAVRc 3.0


### 5.3.9 Connecteurs des encodeurs rotatifs P23 et P24:

### 5.3.10 Connecteur du vibreur P5 :

Attention

- Utilisation d’un vibreur 3,3 v : Vérifier le sens des diodes car il y a eu une erreur de sérigraphie et de positionnement sur le shield
-Utilisation d’un vibreur 5 v : Ne pas câbler les deux diodes et réaliser un court-circuit sur D2 D3

### 5.3.11 Connecteur écran LCD_I2C P15 : (SSD1306 ou SH1106)

Attention | Vérifier que l'adresse de l'écran est bien 0x78 (ce qui correspond à l’adresse d’écriture 0x3C )!!!
Page 13 | Réalisez votre émetteur OpenAVRc 3.0

5V

### 5.3.12 Câblage du module de télémesure, conversion TTL/RS232 P20:

Ce module à base de Max3232 possède deux convertisseurs, un par face. Seul celui côté Max3232 sera utilisé.
Le module possède 4 perçages de petit diamètre pour les

Pour son câblage, je vous conseille de souder deux
barrettes de 4 pins (voir d’abord remarque page suivante, suite à l’erreur sur le circuit) en centrant les pins sur les perçages ainsi que les centres des pins cms sans les percer car cela engendrerait un court-circuit avec la pin cms du dessus.

Soudez deux connecteurs femelles sur le shield , puis enfichez le module et ses connecteurs comme précisé (pins 1 et 8 vers le

Cette solution de câblage, prévu pour une télémétrie FrSky, permettra de remplacer facilement ce module par un autre type de montage pour un autre format de télémétrie.

Astuce

Si vous utilisez un module FrSky DHT, une variante consistant à supprimer le convertisseur TTL/RS232 interne au module et celui-ci, qui devient inutile, est possible (voir plus loin en annexe). A noter que dans ce cas, une mise à jour du firmware du module HF n’est plus possible.
Si vous souhaitez le passer en version EU, cette opération est à faire au préalable.

Voici le schéma de l’ensemble de la chaîne de télémesure :

Page 14 | Réalisez votre émetteur OpenAVRc 3.0

Attention

Si vous voulez utilisez un module HF PPM sur lequel vous récupérerez les signaux de télémesure, il est nécessaire de corriger une erreur de liaison sur le shield.
Si vous n’avez pas l’intention d’utiliser la prise FTDI P2, le plus simple est de câbler le convertisseur TTL RS232 de la façon suivante pour permuter les signaux des broches 5 et 6:

Sinon, à l’heure actuelle R19 va vers U3 et R7 vers U2 (pointillés du schéma) Pour cela, il faudra dessouder et repositionner à votre guise les deux résistances R19 et R7 pour obtenir le schéma suivant.
Attention, les pistes sont fines et fragiles !

Connecteur FTDI pour laisser en permanence un convertisseur USB-série dans votre radio.
Deux inverseurs électroniques basculent les pins du MEGA vers le connecteur télémétrie ou celui-ci en fonction de l’alimentation : Batterie ou USB/
Page 15 | Réalisez votre émetteur OpenAVRc 3.0

### 5.3.13 Connecteur carte SD P6:


Note :

Il faut ajouter une R 220 ohms dans le circuit MISO après avoir recoupé la piste

### 5.3.15 Câblage du module son JQ6500-28P P22 :

Vous utiliserez ce module si vous souhaitez bénéficier des annonces vocales de la fonction
« Voice », pour indiquer des temps de vol, des valeurs de télémesure, la phase de vol sélectionnée, la tension batterie émetteur, etc.
Les annonces vocale seront stockées dans la mémoire micro SD du module.
Le module JQ6500-28P (28 pins) est fourni avec deux barrettes de 14 pins déjà soudées.

Noter la présence des sorties Speaker Out+ et -, permettant de brancher directement un HP 0,8W maxi

Pour être monté correctement sur le circuit, le module doit être préparé en gardant les broches entourées en rouge et à couper au plus court toutes les autre broches.

Astuce

Une autre solution consiste à dessouder les broches non utilisées, ainsi il n’y aura aucun risque qu’une broche inutile touche une piste du shield !

Le module sera alors monté côté soudures du shield (dessous) et les soudures réalisées côté composants (dessus). Note : Sauf le JQ, tous ces composants R et C sont déjà câblés.

Page 16 | Réalisez votre émetteur OpenAVRc 3.0

droit soudé par le dessous de la carte SD,

### 5.3.14 Connecteur des signaux Audio-Buzzer / Voice P8 :

Résumé des possibilités :

Sans fonction Audio sélectionnée dans Desktop

Avec Fonction Audio sélectionnée dans Desktop

Page 17 | Réalisez votre émetteur OpenAVRc 3.0

Dans ce cas, le buzzer raccordé entre 1 et 4 sera utilisé pour signaler toute action effectuée sur une touche ou indiquer une alarme, selon la configuration choisie dans la radio pour cette fonction.
- Si la fonction « Voice/JQ6500 » est activée dans « Desktop », la broche 2 fournit un signal en provenance du JQ pour les annonces vocales.

Ce mode d’utilisation est à notre avis, le plus judicieux, Dans ce cas, la sortie 1 génère un signal Buzzer simulé ainsi que les sons de la fonction « Audio » provoqués par l’appui sur une touche, une commande de trim, etc, selon le choix effectué dans la radio.
Comme précédemment, si la fonction « Voice/JQ6500 » est cochée dans « Desktop », la broche 2 fournit un signal en provenance du JQ6500-28P pour les annonces vocales. Il faudra utiliser un ampli (2w) décrit plus loin, et dont le circuit imprimé est illustré par ailleurs et qui peut être fourni, pour mélanger les signaux Audio et Voice pour envoi au haut parleur 8 ohms.

### Ampli sommateur (CI disponible)

Il faudra réaliser un montage sommateur des signaux Audio-Buzzer et Voice avant amplification des signaux vers un haut-parleur 8 ohms.
Si vous ne souhaitez pas profiter de la fonction « Audio » et utiliser un buzzer seul, («Audio» décoché dans Desktop), tout en utilisant la fonction Voice («Voice» coché dans Desktop), seul le raccordement au JQ (broche 2) sera nécessaire et vous n’aurez pas besoin de la partie sommateur.
En option, un jack (embase jack mono 3,5mm) peut être ajouté pour brancher une oreillette.
La résistance de 220 Ohms sera adaptée à votre audition. L’idéal sera dans un premier temps d’utiliser une résistance variable de 1Kohms pour trouver votre réglage idéal, puis de remplacer cette résistance par une résistance fixe de valeur approchante.

Schéma de la partie sommateur + ampli LM386.


Note : Les références des composants n’ont rien à voir avec celle du shield.

Vous pouvez aussi réaliser votre adaptation en utilisant des amplificateurs audio du commerce, à base de LM386 ou PAM8302 (classe D) ou tout autre ampli mono.
Une puissance de 2w est suffisante.

Ou utiliser« notre » ampli OpenAVRc

Page 18 | Réalisez votre émetteur OpenAVRc 3.0

### 5.3.16 Câblage du module RTC DS3231 et FRAM référence FM24W256-G P2 :

Initialement cette partie était à câbler par vos soins. Sur le shield version 2.1 elle a été précâblée.


De ce fait, le connecteur P2 est libre et pourra être utilisée pour toute extension I2C.

La carte comporte donc dès l’origine
- d’une part une mémoire F-RAM FM24W256-G portant à 32 Ko la capacité mémoire des modèles. A ce jour, seuls 16 Ko sont utilisés
- un circuit horloge RTC (Real Time Clock) DS3231 et en prime un capteur de température,

Info F-RAM Ses avantages : plus d’espace mémoire, plus rapide et plus grande résistance aux multiples écritures.

Le circuit imprimé comporte au dos un connecteur pour la pile CR2032 (sauvegarde de l'heure après extinction).


Page 19 | Réalisez votre émetteur OpenAVRc 3.0

### 5.3.18 Connecteur écolage P18:

L’écolage pourra se réaliser selon deux méthodes,
- par câble ou
- par Bluetooth (non fonctionnel à ce jour).

Ecolage par câble :
Il suffit d’amener un signal ppm à l’entrée (+) correspondante

Ecolage par liaison Bluetooth : ( !!! non fonctionnel pour l’instant !!!)

Le module Bluetooth HM10 est configurable en maître ou esclave.
Durant cette configuration, la patte KEY devra être alimentée en VCC .
Le module du professeur sera de préférence configuré en maître et celui de l’élève de préférence en esclave.
Pour une meilleure différenciation des modules, on pourra par exemple convenir que le nom d’un module professeur commence par MAMONNOM (maître) et celui de l’élève par ELMONNOM (élève). Une led (bleue?) peut être connectée à la patte STATUS. Elle sera alors connectée en série avec une résistance de 180 ohms 1/4w.
Page 20 | Réalisez votre émetteur OpenAVRc 3.0

## 5.4 Modules HF :

### 5.4.1 Module HF cc2500 jaune :

Si vous n’utilisez que des récepteurs FrSky, préférez le module CC2500 suivant qui a fait ses preuves.

### 5.4.2 Câblage du convertisseur de niveaux 5v/3,3v :

Les entrées sorties n’acceptent que des signaux 3,3v. Il est donc IMPERATIF de séparer ce module du Core à l’aide d’un convertisseur 4 voies (MOSI, MISO, CS, SCLCK) qui reçoit des signaux de niveaux 0-5v et les convertit en signaux de niveaux 0-3,3v et inversement pour le signal MISO.


Le circuit imprimé (disponible) permettra l’adaptation sous un format réduit. Il est connecté sur P7 (voir p18).


Page 21 | Réalisez votre émetteur OpenAVRc 3.0

### 5.4.3 Câblage du module HF 4 en 1 SPI P7:

Le câblage se fera, de préférence par le dessous (soudures réalisées par dessus).
Le module multi protocoles 4 en 1 est alimenté en 5V. Les entrées sorties n’acceptent que des signaux 3,3v. Il est donc ABSOLUMENT nécessaire de séparer ce module à l’aide d’un convertisseur de niveaux de signaux 5v/3,3v. Ce convertisseur reçoit des signaux de niveaux 0-5v et les convertit en signaux de niveaux 0-3,3v.

### 5.4.4 Câblage du convertisseur de niveaux 5v/3,3v :

### 5.4.5 Câblage du module HF 4 en 1 :

Page 22 | Réalisez votre émetteur OpenAVRc 3.0

## 6 Amplification des signaux de manches :

Info

Cette option précablée (sauf les 8 potentiomètres), permet une meilleure définition des signaux de voies car elle utilise toute la plage de mesure du convertisseur analogique numérique de la carte MEGA-CORE.

## 6.1 But partie Amplification des manches

Info Nous avons constaté des écarts importants entre différents potentiomètres, moins avec les manches à effet Hall.

## 6.2 Schéma partie Amplification des manches

Page 23 | Réalisez votre émetteur OpenAVRc 3.0

Un manche produit une tension variant proportionnelle avec l’angle de rotation.

Le but de la partie ampli est d’obtenir aux entrées analogiques du Core une tension variant du Mini = 0V à Maxi = +5V

Le point « centre » (neutre du manche) est caractérisé par une tension de + 2,5V avec des potentiomètres alimentés en 5V et de + 1,65v (environ) avec des capteurs à effet Hall alimentés en 3.3V,

A cet effet, nous disposons de deux potentiomètres, que nous appellerons
« centre ou zéro » (repérés RV) et « pente ou gain» (R)

Quelques explications techniques :

Info
technique

Bien que le convertisseur du Core ne travaille que sur 10 bits (1024 points), le logiciel FW, par le biais de deux conversions successives, élabore un signal sur 11 bits (0000 à 07FFh) ce qui signifie en théorie que 2048 valeurs différentes pourront être appliquées aux servomoteurs.
Ces valeurs seront visualisées dans l’écran « Anas, 6/7 » de l’émetteur, sous forme hexadécimale et en %. La valeur en % n’est significative qu’après la calibration des manches (voir page 17)


Attention Note : Sur l’écran ANAS, les indications des voies Dir, Prf ne seront exactes qu’après adaptation de votre mode de pilotage dans l’écran 1 « Config Radio »

Les valeurs 0400 correspondent au point « Centre »

Les valeurs des composants du schéma sont définies pour des potentiomètres alimentés en 5V. Commencez par mettre en place R27, RV2, R30(100k), RV3(100k), R33, RV4, R36, RV5.

Si vous utilisez des manches avec capteurs à effet hall, il faut :

- Remplacer R24 (39kOhms) par une résistance de 82kOhms (rouge sur le schéma).
De cette façon, vous obtiendrez env. 1,6V sur le point commun de R24 R25.
- Si nécessaire, remplacer les résistances R11, R12, R13 et R14 par des résistances de 82kOhms ou plus. (bleu sur le schéma). Essayez d’abord sur une voie avec les valeurs en place avant de remplacer.
Attention | N’inversez jamais l’alimentation des manches à effet Hall sous peine de destruction des capteurs, Une option de compilation de Desktop permet d’adapter les sens d’action. (voir document « Compilez….)
Page 24 | Réalisez votre émetteur OpenAVRc 3.0

Mettez en place le cavalier de choix de la tension d’alimentation des manches (5V pour potentiomètres, 3,3V pour manches à effet Hall, genre M9, M9R, M7 ou M7R)

## 6.3 Réglage des amplificateurs d’adaptation des manches :

Le circuit amplificateur des manches a besoin d’un réglage pour obtenir la plage de tension de l’ordre de 0-5V pour la pleine course du manche.
Deux potentiomètres par manches, « zéro = RV2, 3, 4, 5 » et « gain =R27, 30, 33, 36 », permettent ce réglage.

Deux méthodes peuvent être utilisées :
Si votre émetteur est déjà opérationnel, passez directement à la méthode 2, bien plus pratique !

### 6.3.1 Méthode 1

- en analogique sans lien avec le fonctionnement de la radio, ce qui permet déjà de valider la partie Manches si vous avez commencé par là. Un peu fastidieux…..mais instructif.
Note : VL = Vertical Left, | HR= Horizontal Right
Affectation des potentiomètres pour le mode 1 | et le mode 2

Gain Ailerons Zéro Ailerons Gain Gaz Zéro Gaz Gain Profondeur Zéro Profondeur Gain Dérive Zéro Dérive; Gain Dérive Zéro Dérive Gain Profondeur Zéro Profondeur Gain Gaz Zéro Gaz Gain Ailerons Zéro Ailerons

Commencez de préférence par le manche des gaz (RV en mode 1, LV en mode 2)
Pour le mode 1, Prérégler RV3 et R30 en milieu de course.
A l’aide d’un multimètre :
a) manche au neutre, sur la broche correspondante du circuit Core (Pin 51) mesurer la tension puis régler à environ 2,5v en agissant sur RV2.
Correspondance Manches/N° Broches du Core en mode 1 | et en mode 2
b) puis déplacer le manche vers +50%. (à droite pour les manches horizontaux et en haut pour les manches verticaux).
La tension doit augmenter et si ce n’est pas le cas, revoir page 10 et inverser le sens d’alimentation du manche, s’il s’agit d’un potentiomètre.
Page 25 | Réalisez votre émetteur OpenAVRc 3.0

Affectation des manches

P12 | P13
VL HL | VR HR

Attention

Du fait de la dispersion des variations des manches, il sera peut-être nécessaire d’adapter le gain des 4 amplis en modifiant R 11, 12 , 13 et 14. (Vous pouvez pour cela mettre le pot de gain R30 au milieu de sa course et chercher la bonne valeur de R12 avec un potentiomètre à la place de la résistance.

Régler R27 pour obtenir environ 4,5 à 4,8V avec le manche au maxi. Si vous ne pouvez pas obtenir cette tension et que votre tension est plus importante, c’est que votre manche présente une trop grande variation du signal et il vous faudra diminuer le gain des amplificateurs en remplaçant R30 (120k) par une valeur plus faible. (47K – 68K devrait convenir)

c) Manche au maximum, régler alors la tension à 4,90V max à l’aide du potentiomètre R27.
d) Vérifier que vous avez environ 0,1V au mini du manche.

Si la variation n’est pas la même dans les deux sens, rien à faire, c’est la linéarité de votre potentiomètre de manche qui est en cause, mais pas grave…le logiciel adaptera ensuite. Effectuer la même procédure pour les autres manches sans chercher la précision puisque nous réglerons ces valeurs plus finement par la suite.
Au bout du quatrième, vous devriez maîtriser la méthode !
De toute façon, il vous faudra étalonner les manches lors de la mise en route de l’émetteur comme montré sur la vue « Calibration » de la page suivante.

### 6.3.2 Méthode 2

Plus pratique à réaliser, celle-ci ne pourra se faire que si l’émetteur est déjà opérationnel.
- Accéder à l’écran « ANAS » 6/7 de la radio et consulter les valeurs délivrées par chaque manche.
- Au neutre du manche, régler les potentiomètres de zéro pour obtenir 0400(H) points.
- Au mini du manche, régler le potentiomètre de gain pour obtenir 0020(H) du convertisseur.
Vérifier le point maximum : si vos potentiomètres sont linéaires, vous devriez obtenir une valeur proche de 07E0.
Note : Il peut être nécessaire de reprendre les réglages si vous devez régler une grande variation.
En tout état de cause, terminer par un réglage de neutre à 0400,

Ensuite, une fonction de « Calibration » sera effectuée, dont le but est de prendre les valeurs exactes de points du neutre et de chaque sens de chacun des manches, de les affecter de coefficients afin de permettre des calculs précis sur les trims, les mixages, l’affichage, etc, et bien sûr le calcul de la largeur d’impulsions.
Au final, un manche variera de -100% à +100%
Sur la vue suivante, « Ail» est sur fond noir, ce qui montre une saturation du signal, la tension mini du manche est trop faible ce qui montre que le gain est trop important sur cette voie.
Page 26 | Réalisez votre émetteur OpenAVRc 3.0

Page 27 | Réalisez votre émetteur OpenAVRc 3.0

## 7 Préparation des écrans :

## 7.1 Rappel Brochage de P16

Attention avec le n° de P16 lors du câblage, la nappe étant inversée (2,1,4,3, etc)

## 7.2 Ecran Zollen (7565P)

Ecran idéal pour le reconditionnement de petits/moyens boîtiers

Info

Si à la mise sous tension du 7565P, votre écran paraît foncé, pas d’inquiétude, regardez le de travers et tâchez d’accéder au réglage du contraste qui est peut-être « coincé » à 30.
En revenant à une valeur intermédiaire, votre écran devrait être plus lisible !

Choisir ST7565P dans Desktop. Alimentation en 5V.

Dessouder R4 (80) et faire un pont sur R6 (68).

Page 28 | Réalisez votre émetteur OpenAVRc 3.0

Vdd +5V; RST A_Lcd; 7.3 Ecran ARTRONIC (7565R); Choisir ST7565R dans Desktop.Alimentation en 3,3V.; Connecteur P16; A terminer; Page 29; Réalisez votre émetteur OpenAVRc 3.0

Adaptation du connecteur P16 (2 lignes du haut) au brochage du Zolen (2 lignes du bas + schéma)

Avec cet écran RV6 n’est pas
nécessaire.
RV1, permettra le réglage de
luminosité, le contraste étant réglé
par logiciel.
Note : Dans les documentations, il
est prévu d’insérer une R de 100
ohms environ dans la ligne
LCD_Light : cette résistance est
déjà en place sur le Circuit (R10)

## 7.4 Ecran ST 7920 :

GND; V0 V out; LCD; GND Blk Lcd; 1 Vss; Info; Cet écran est particulièrement adapté si vous disposez d’un boîtier d’émetteur; Multiplex 30xx ou 4000; Page 30; Réalisez votre émetteur OpenAVRc 3.0

Choisir ST7920 dans Desktop.
Alimentation en 5V.

Adaptation de P16 (ligne du haut) au brochage de l’écran ST7920 (type 12864B V2.0) (ligne du bas):

RD PSB RW RS RST Bla

La broche 15 (PSB) de l’écran doit être connectée au +5V pour définir le mode
parallèle.
La broche 20 n’est pas connectée,

## 7.5 Ecran KS108B :

Attention; V out; Lcd A0; RST Bla LCD; Blk Lcd; Attention :; Page 31; Réalisez votre émetteur OpenAVRc 3.0

Il existe plusieurs modèles d’écrans KS108.
Le notre est le KS108 « B » : Ecran dimensions 61 * 44 mm

Choisir KS108 dans Desktop. Alimentation en 5V

R10 se trouvent
sur le shield

Adaptation du connecteur P16 ( ligne du haut) au brochage du KS108A ( ligne du bas du tableau):

La piste 7 de l’écran est à connecter à la masse par une R de 1 kohms.
Si l’affichage est inversé, permutez CS1 et CS2. (Point 1 et 2 sur l’écran)

## 7.6 Résumé des raccordements Arduino, Ports, P16 et Ecrans

Note : La colonne 2560 est indiquée pour informations uniquement
Le tableau est ordonné selon le numéro des broches de P16
2560 | Core | Port | P16 | Signal | 7565P | 7920 | KS108
OV Gnd | | | 1- 0V | Blk Afficheur | 14 | | 20
OV Gnd | | | 2 - 0V | Vss | 10 | 1 | 3
+5V Vss | | | 3 | Vdd | 9 | 2 | 4
NC | NC | X | 4 | Vo ou Vr (pt. Milieu RV1) | x | 3 | 5
NC | NC | x | 5 | Vee ou Vout (vers 1 coté de RV6) | x | 18 | 18
22 | 74 | A0 | 6 | DB0 | 1 | 7 | 9
23 | 71 | A1 | 7 | DB1 | 2 | 8 | 10
24 | 72 | A2 | 8 | DB2 | 3 | 9 | 11
25 | 69 | A3 | 9 | DB3 | 4 | 10 | 12
26 | 70 | A4 | 10 | DB4 | 5 | 11 | 13
27 | 67 | A5 | 11 | DB5 | 6 | 12 | 14
28 | 68 | A6 | 12 | DB6 | 7 | 13 | 15
29 | 65 | A7 | 13 | DB7 | 8 | 14 | 16
30 | 83 | C7 | 14 | /RD (ou RD ou E) | 16 | 6 | 8
31 | 84 | C6 | 15 | WR (ou RW) | 15 | 5 | 7
32 | 85 | C5 | 16 | Lcd A0 (ou RS, /DI) | 14 | 4 | 6
33 | 86 | C4 | 17 | :RST (ou /RES) | 13 | 17 | 17
| | | 18 | Point milieu RV6 | x | 19 | 19
35 | 87 | C2 | 19-0V | A Led Rétroéclairage 100 ohms | 11 | 20 | 20
34 | 87 | C3 | 20 | /CS (CS1) | 12 | x | 1
| | | | (CS2 sur KS108) | X | X | 2
| | | | PSB sur 7920 | X | 15 | x
Remarques | x | | Inexistant, non connecté
KS108 | 1 | CS1 | Relié à Lcd_WR
| 2 | CS2 | Relié à Lcd_Cs
| 7 | R/W | Relié à la masse par R 1kohms
ST7920 | 15 | PSB | Signal PSB à relier au +5V
| 16 Non connecté
| | | Pas de potentiomètre RV6
7565P | | | Pas de potentiomètre RV6
Page 32 | Réalisez votre émetteur OpenAVRc 3.0

## 8 Annexes :

8.1 Suppression du convertisseur TTL/RS232 du module FrSky DHT.


Le module DHT incorpore d’origine un convertisseur RS232 < > TTL sur la liaison télémesure.
Cette liaison est également utilisée pour la mise à jour du firmware du module.
Si l’on ne souhaite plus mettre à jour ce module (il n’y aura plus de nouvelles versions de toute façon) il est judicieux de supprimer ce convertisseur, ce qui permettra donc de relier directement ces signaux aux entrés sorties de télémesure et évite le câblage du convertisseur RS232/TTL décrit en page 7 de ce document.
Au final, l’opération est relativement simple :
Repérer les points de sortie Tx et Rx de la carte
- Sur le circuit imprimé, couper les deux pistes arrivant sur ces deux points
- (les deux traits jaunes près de C21 et R19)
- Raccorder directement Tx et Rx aux points indiqués sur la vue suivante
- Il faudra bien sûr ponter les connexions qui ne sont plus réalisées par le convertisseur sur la carte en raccordant les points suivants :
- Note : La liaison en bleu dans la ligne réception est une résistance de 220 ohms
Page 33 | Réalisez votre émetteur OpenAVRc 3.0

NOTE : Si vous utilisez le shield 2.1, raccordez ces points en croisé (1>5 et 2>6) pour tenir compte de l’erreur décrite en début de document

## 9 Implantation des composants :

Page 34 | Réalisez votre émetteur OpenAVRc 3.0

## 10 Conseils Divers

- souder BT1 (connecteur pile horloge) côté soudures avec un connecteur coudé sortant sous le JQ6500 (attention aux court-circuits avec les pins du core).
- Ne câblez votre carte SD que lorsque vous aurez testé toutes les fonctions car elle pourrait vous bloquer l’accès à la F-Ram et à l’horloge en cas de défaillance de l’un d’eux.
- si votre port I2C ne fonctionne pas (la F-Ram, l’horloge DS3231 et le SSD1306 l’utilisent),cela peut provenir du DS3231 défectueux. Dans ce cas, soulevez les pattes 15 et 16 (sda et scl).
- Pour le réglage des 4 manches, il existe 4 plages cms (W1 à W4 côté soudures). Pour ma part j’ai préféré placer ma pointe de multimètre sur les pattes 1,7,8 et 14 du MCP604. Cela évite de retourner le shield.

Autre solution: Se placer sur la broche correspondante du circuit Core pour bénéficier d’un contact “non glissant”, voir page 21.
- Certains d’entre nous ont eu des problèmes de faux contacts. Une brosse à dents avec, soit de l’alcool à brûler (ma préférence), soit de l’acétone (un peut fort à mon goût) peut vous aider à bien nettoyer le shield d’éventuelles particules de soudures .
- Le PM-5033 n’est pas facile à approvisionner. Le petit convertisseur DC-DC qui est prévu en double implantation du 5v, peut être une solution de remplacement. Pour l’implanter facilement, souder 4 connecteurs deux points sur le shield (IN+,IN-,OUT+ et OU-), puis soudez aussi 4 connecteurs deux points sous le convertisseur. Soudez ensuite l’ensemble sur les 4 connecteurs du shield par dessus les 3 grosses capacités.

Si vous constatez des erreurs (et il y en a sûrement), merci de me contacter (pierrotm77) par le biais des messages MP du forum

Page 35 | Réalisez votre émetteur OpenAVRc 3.0

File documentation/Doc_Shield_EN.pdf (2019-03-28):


# Wiring the MegaMini © Version 2.1 Shield


Page 1 | Construct your OpenAVRc 3.0 transmitter

# OpenAVRc

# An open source RC transmitter based on the ATMega 2560 AVR microcontroller from ATMEL / Microchip

Copyright OpenAVRc 2018


# This circuit is intended for the mega2560-Core from Inhaos

Page 2 | Construct your OpenAVRc 3.0 transmitter

Advice :
We suggest that you read and reread this document and let it sink in before the building starts.
Prefer a "function by function" construction and test and verify the correct functioning before moving on to the next phase.
Suggested order of construction
- Power supplies and stick connectors
- Stick amplifier
- Setting up the different connectors
- Screen and Core circuit
At this point, you can then start your radio after using the document "OpenAVRc_V3 Software Manual"
- SD card
- JQ6500
-etc
To wire up the circuit, one can also consider a second method, namely
- power supply
- mounting one of the screens
- setting up the 3 connectors of the Core
- configuration of the Core circuit based on the document "Software Manual"
- implementation of the Core
- power up! And verification of operation
- continued wiring

## Document versions

Version | | | Date | Reason for Change
0.1 0.2 0.3 0.4 0.5 0.6 | 31/07/2018 03/10/2018 05/12/2018 11/12/2018 21/12/2018 11/01/2019 | Creation of V2.1 Adding 10K Resistance on Q3 Base / Silk Screen Correction LL4148 Warning vibrator diodes, adding power supply part, graphic chart, updated wiring screens, various minor modifications Rear panel modification p. 6 for diode direction D1, D2 and D3 Added recommendation if Hall effect sticks are used and telemetry circuit error correction with added schema Error correction and addition of Hall stick explanations

## 2 Copyright

This document is Copyright © 2018 OpenAVRc.

## 3 Caution

The OpenAVRc team is not responsible for damages that may arise from the misuse or possible malfunction of the OpenAVRc transmitter

It is therefore up to the end user to measure, assume the risks and comply with the legislation in force depending on the country of use.

Graphical charter :

Note

Info

Warning

Warning 1: The first pre-wired circuits of version 2.1 were delivered with the vibrating circuit diodes wired upside down. (D1, D2 and D3).
It is necessary to invert them if you want to use the vibrator. If not, simply remove them.
See the correct direction of assembly of these diodes pages 6 or 33.Attention
Warning | Warning 2: A circuit connection error was found in the telemetry section on the version 2.1 shields. See pages 13-14 for correction. This change is not necessary if you are using a DC or multimodule HF circuit.
Page 3 | Construct your OpenAVRc 3.0 transmitter

## 4 Table of contents

Page 4 | Construct your OpenAVRc 3.0 transmitter

Page 5 | Construct your OpenAVRc 3.0 transmitter

## 5 Module wiring and connector locations:


Top side

Bottom side

the 3 diodes D1, D2 et D3

Page 6 | Construct your OpenAVRc 3.0 transmitter

## 5.1 Diagram of the Power supply section:

The Power supply section includes:
- a common power supply battery (Lipo, LiFe, NiMh ...)
- a protection diode D6
- a switch circuit consisting of Q3, Q4 with power switch P21
- a circuit for measuring the battery voltage R16 and R17
- a 5V regulator (3 solutions)
- and possibly a 3.3V regulator if necessary for a screen or Hall stick depending on the type of 5V power supply you choose.

## 5.2 Common supply (LI-Ion) :

A LiPo battery or better, Li-Ion 2S or 3S (3 x 4.2v maximum) can be used to power the board.

Page 7 | Construct your OpenAVRc 3.0 transmitter

+5 and + 3.3V Power Supply Circuits:

### 5.2.1 Solution 1 : L4940 or 4941:

This first solution uses a linear 5v L4940 series regulator whose efficiency is much worse than the two following solutions. The TO220 three-legged housing will be wired to tabs 2, 3 and 4 of U4. In case 3.3V is needed (for Hall effect sticks), U5 must be soldered.

Warning Except wanting to dissipate some heat, it is useless to use a 3S battery in this case!

### 5.2.2 Solution 2 : (PM-5033)

Here, the 5v AND the 3,3v are created by the PM-5033 from Inhaos (U4).
Very good performance at 96%, good higher than the L4940 of solution 1, so less heat dissipation and longer battery life.
Do not solder U5 (3.3v), a 3.3V regulator is already mounted on the back of the IC.


### 5.2.3 Solution 3 : (MP1584em)

This last solution uses a DC / DC module ( switching power supply, in place of the PM-5033 (U4).
Very good performance also at 96%,

Adjustment (if any) of the output voltage:
- Replace the variable resistor with a fixed resistance of 47K ohms in parallel with a resistance of 1M ohms.
For this value the output voltage is then 4.97V.

If 3.3V is needed then U5 should be soldered.

Warning | It is imperative to adjust this module to +5v maximum before soldering it on the circuit at the risk of destroying the active components that do not support more than 5V. In addition, the SSD1306 I2c screen will not start.
Page 8 | Construct your OpenAVRc 3.0 transmitter

## 5.3 Wiring of different connectors

5.3.1 P12 and P13 Sticks:; potentiometers powered by 5V.; must be powered by 3.3V.; channel,

It is possible to turn the screw of each potentiometer to reverse the direction of movement.

Warning

For correct adjustment, the voltage will increase when the stick is operated from left to right or from bottom to top.
In the case an amp is being used, then the signal will be reversed, it will take this into account. This will be pointed out again in the settings.

Warning

Hall effect sleeves: It is almost certain that you will have to reverse the direction of movement of one of the two channels of each stick. For this, do not reverse the power supply (risk of destruction of the sensor electronics) but use the software reversal option described in the document "Software Manual" (Desktop)

### 5.3.2 P1, P2 and P3 Potentiometers:

It is possible to turn the screw on each potentiometer to reverse the direction.

Page 9 | Construct your OpenAVRc 3.0 transmitter

By default, the shield is prewired for sticks with

There are sticks with Hall effect sensors that

In this case, it will be necessary to replace a resistor on the divider bridge and one per

(See page 22 "Stick Amplification P12 and P13:

### 5.3.3 P16 Parallel LCD screen:


Position the RV1 potentiometer as shown in the diagram (turn to the right to be accessible if you put a jumper). See diagram page 5

For details on how to wire up screens connected in parallel, (Zolen, Artronic, ST7920 and KS108, see chapter 7, page 26)

Warning Pay attention to the pin order for connector P16 on the connected cable (2,1,4,3, etc.) See chapter 7

### 5.3.4 P9 ICSP connector:

### 5.3.5 P11 Trim Connector:


Page 10 | Construct your OpenAVRc 3.0 transmitter

### 5.3.6 P14 Switch Connector:


### 5.3.7 P25 key connector :

Each key will be connected between one of the pins 3 to 8 and the common (GND).

### 5.3.8 P19 connector, telemetry and PPM output to HF module:


Warning
See the diagram in this section on page 13 for more explanations
Page 11 | Construct your OpenAVRc 3.0 transmitter

5V

### 5.3.9 P23 and P24 Rotary encoder connectors:

### 5.3.10 P5 vibrator connector:

Warning - Using a vibrator 3.3 v: Check the direction of the diodes because there was a screen printing and positioning error on the shield -Using a vibrator 5 v: Do not wire both diodes and short circuit D2 D3

### 5.3.11 P15 I2C LCD Display Connector: (SSD1306 ou SH1106)

Warning | Check that the screen address is 0x78 (which corresponds to the write address 0x3C) !!!
Page 12 | Construct your OpenAVRc 3.0 transmitter

### 5.3.12 P20 Wiring for the telemetry module, TTL / RS232 converter:

This Max3232-based module has two converters, one per side. Only the Max3232 side will be used.
The module has 4 small diameter holes for VCC and GND power supplies.
For its wiring, I advise you to solder two
strips of 4 pins (see first remark next page, following the error on the circuit) by centering the pins on the holes as well as the

centers of the SMD pads without drilling them because that would generate a short circuit with the SMD pin from below.

Solder two female connectors on the shield, then plug the module and its connectors as specified (pins 1 and 8 down).
This cabling solution, intended for FrSky telemetry, will allow this module to be easily replaced by another type of assembly for another telemetry format.

Note

If you are using a FrSky DHT module, you have the option of removing the internal TTL / RS232 converter from the module, which becomes useless (see appendix). Note that in this case, a firmware update of the HF module is no longer possible. If you want to upgrade to the EU version, this must be done first.

Here is the diagram of the entire telemetry chain:

Page 13 | Construct your OpenAVRc 3.0 transmitter

Warning

If you want to use a PPM HF module on which you will receive the telemetry signals, it is necessary to correct a link error on the shield.
If you do not intend to use the FTDI P2 jack, the easiest way is to wire the TTL RS232 converter as follows to swap the signals from pins 5 and 6:

Otherwise, at present R19 goes to U3 and R7 to U2 (dotted diagram)
To do this, you will need to desolder and reposition as you please the two resistors R19 and R7 to obtain the following diagram.
Look out, the tracks are fine and fragile!

FTDI connector to permanently leave a USB-serial converter in your radio.
Two electronic inverters flip the pins
MEGA to the telemetry connector or this one according to the power supply: Battery or USB.
Page 14 | Construct your OpenAVRc 3.0 transmitter

### 5.3.13 P6 SD card connector:

Note:

A R 220 ohm must be added to the MISO circuit after intersected the trace

### 5.3.15 P22 JQ6500-28P sound module wiring:

You will use this module if you want to benefit from voice announcements from the function "Voice", to indicate flight times, telemetry values, the selected flight phase,
transmitter battery voltage, etc.
Voice announcements will be stored in the module's micro SD memory.
The JQ6500-28P (28 pins) module comes with two 14-pin strips already soldered.

Note the presence of the Outputs Speaker Out + and -, allowing to directly connect a SP of 0.8W max

To be mounted correctly on the circuit, the module must be prepared . The pins circled in red should be kept but all other pins must be cut off.

Note

Another solution is to desolder the unused pins, so there is no risk that a unused pin touches a track of the shield!

The module will be mounted on the shield’s solder side (bottom) and soldering made on the component side (top). Note: Except the JQ, all these R and C components are already wired.

Page 15 | Construct your OpenAVRc 3.0 transmitter

The SD card is connected under the Core.

connector and replace it with a straight connector soldered from the bottom of the

### 5.3.14 P8 Audio-Buzzer / Voice signal connector:

Summary of possibilities:

Without Audio function selected in Desktop

With Audio Function selected in Desktop

Page 16 | Construct your OpenAVRc 3.0 transmitter

In this case, the buzzer connected between 1 and 4 will be used to indicate any action performed on a key or indicate an alarm, depending on the configuration chosen in the radio for this function.
- If the "Voice / JQ6500" function is enabled in "Desktop", pin 2 provides a signal from the JQ for voice announcements.

This mode of use is the smartest in our opinion
In this case, output 1 generates a simulated Buzzer signal as well as the sounds of the "Audio" function caused by pressing a key, a trim control, etc., depending on the choice made in the radio.
As before, if the "Voice / JQ6500" feature is checked in "Desktop", pin 2 provides a signal from the JQ6500-28P for voice announcements.
It will be necessary to use an amplifier (2w) described below, and whose printed circuit is also illustrated and available, to mix the Audio and Voice signals for sending to the 8 ohm speaker.

### Mixing amp (Component Iist available)

It will be necessary to make a mixer assembly for the Audio-Buzzer and Voice signals before amplifying the signals to an 8-ohm loudspeaker.
If you do not want to use the "Audio" function and use a single buzzer, ("Audio" unchecked in Desktop), while using the Voice function ("Voice" checked in Desktop), only the connection to the JQ (pin 2 ) will be necessary and you will not need the mixing section.
As an option, a jack (3.5mm mono jack socket) can be added to connect a headset.
The resistance of 220 Ohms will be adapted to your hearing. The ideal first step is to use a variable resistor of 1Kohms to find your ideal setting, then replace this resistance with a fixed resistor of similar value.

Diagram of the mixing section + LM386 amp.

Note:
The

component references have nothing to do with the shield.

You can also make your adaptation using commercial audio amplifiers, based on LM386 or PAM8302 (class D) or any other mono amp.
A power of 2w is sufficient.

Or use "our" amp OpenAVRc

Page 17 | Construct your OpenAVRc 3.0 transmitter

### 5.3.16 P2 DS3231 RTC module and FRAM FM24W256-G connector:


Initially this part was to connect by your self. On the version 2.1 shield it has been preconnected.


As a result, the P2 connector is free and can be used for any I2C extension.

The board therefore includes from the start
- On the one hand, an F-RAM memory FM24W256-G bringing the memory capacity for the models to 32 KB.
To date, only 16 KB are used
- a DS3231 RTC clock circuit (Real Time Clock) and as a bonus a temperature sensor.

Info F-RAM advantages: more memory space, faster and greater tolerance to multiple writes.

The back of the circuit board has a connector for a CR2032 battery (saves the time after transmitter is turned off).


Page 18 | Construct your OpenAVRc 3.0 transmitter

### 5.3.18 P18 trainer connector:

The training can be done according to two methods,
- by cable or
- by Bluetooth (not functional right now).

Training with cable:
Just bring a ppm signal to the corresponding (+) input

Traing via Bluetooth: ( !!! not functional yet !!!)

The Bluetooth module HM10 is configurable as master or slave.
During this configuration, the KEY leg must be powered by VCC.
The teacher module will preferably be configured as a master and the student preferably as a slave. For a better differentiation of the modules, we can for example agree that the name of a teacher module starts with MAMONNOM (master) and the name of the student by ELMONNOM (student).
A led (blue?) Can be connected to the tab STATUS. It will then be connected in series with a 180 ohm 1 / 4w resistor.
Page 19 | Construct your OpenAVRc 3.0 transmitter

## 5.4 Modules HF:

### 5.4.1 Module HF cc2500 jaune :

If you only use FrSky receivers, prefer the following CC2500 module that has a proven track record.


### 5.4.2 Wiring of the 5v / 3,3v level converter:

The input outputs only accept 3.3v signals. It is ESSENTIAL to separate this module from the Core using a 4-channel converter (MOSI, MISO, CS, SCLCK) which receives 0-5v level signals and converts them into 0-3,3v level signals. and vice versa for the MISO signal.

The printed circuit board (available) will allow mounting in a smaller area. It is connected to P7 (see page 21) .


Page 20 | Construct your OpenAVRc 3.0 transmitter


### 5.4.3 P7 Connections for the HF module 4 in 1 SPI:

The wiring will be done, preferably from below (soldering made from above).
The 4-in-1 multi-protocol module is powered by 5V. The input / outputs only accept 3.3v signals. It is therefore ABSOLUTELY necessary to separate this module using a 5v / 3.3v signal level converter.
This converter receives 0-5v level signals and converts them into 0-3,3v level signals.

### 5.4.4 Connections for the 5v / 3,3v level converter:

### 5.4.5 Connections for the 4 in 1 HF module:

Page 21 | Construct your OpenAVRc 3.0 transmitter

## 6 Amplification of the stick signals:

Info

This pre-wired option (except the 8 potentiometers) allows a better definition of the channel signals because it uses the entire measurement range of the analog to digital converter of the MEGA-CORE board.

## 6.1 Purpose for the stick amplification

Centre; Pente; Déplacement; du Manche; Tension; Mini; Max; angle of rotation.

Info We noticed significant differences between different potentiometers, less with Hall effect sticks.

## 6.2 Diagram of the stick Amplification

Page 22 | Construct your OpenAVRc 3.0 transmitter

A stick produces a voltage varying proportionally with the

The purpose of the amplifier part is to obtain at the analog inputs of the Core a voltage varying from Mini = 0V to Maxi = +

The point "center" (neutral of the stick) is characterized by a voltage of + 2.5V with potentiometers powered by 5V and + 1.65v (approximately) with Hall effect sensors powered by

For this purpose, we have two potentiometers, which we will call "center or zero" (marked RV) and "slope or gain" (R)

Some technical explanations:

Technical
info

Although the Core converter only works on 10 bits (1024 points), the FW software, through two successive conversions, generates an 11-bit signal (0000 to 07FFh) which theoretically means that 2048 different values can be be applied to servomotors.

These values will be displayed in the "Anas, 6/7" screen of the transmitter, in hexadecimal form and in %. The value in % is significant only after the calibration of the sticks (see page 17)


Warning Note: On the ANAS screen, indications of the Dir, Prf channels will only be accurate after setting up your control mode in screen 1 "Config Radio"

The values 0400 correspond to the "Center" point

The values of the schematic components are defined for potentiometers powered by 5V. Start by setting up R27, RV2, R30 (100k), RV3 (100k), R33, RV4, R36, RV5.

If you use sleeves with hall effect sensors, you must:

- Replace R24 (39kOhms) with a resistance of 82kOhms (red in the diagram).
In this way you will get approx. 1.6V on the common point of R24 R25.
- If necessary, replace the resistors R11, R12, R13 and R14 with resistances of 82kOhms or more. (blue on the diagram). Try first on a track with the values in place before replacing.
Warning | Never reverse the supply of Hall effect sleeves under penalty of destruction of the sensors, A compilation option of Desktop allows to change the directions of action. (see the document "Software Manual ....)
Page 23 | Construct your OpenAVRc 3.0 transmitter

Set the jumper for the supply voltage for the sticks (5V for potentiometers, 3.3V for Hall effect sticks, type M9, M9R, M7 or M7R)

## 6.3 Adjustment of the stick adapters:

The amplifier circuit of the sticks needs a setting to obtain the voltage range in the order of 0-5V for the full movement of the handle.
Two potentiometers per stick, "zero = RV2, 3, 4, 5" and "gain = R27, 30, 33, 36", allow this setting.

Two methods can be used:
If your transmitter is already operational, go directly to method 2, much more convenient!

### 6.3.1 Method 1

- analog without connection to a working radio, which already allows to validate the sticks section if you started there. A little tedious ... ..but instructive.


Note : VL = Vertical Left, | HR= Horizontal Right
Assignment of potentiometers for mode 1 | and mode 2

Preferably start with the throttle stick (RV mode 1, LV mode 2)
For Mode 1, Preset RV3 and R30 in the middle of the range.
Using a multimeter:
a) stick in neutral, on the corresponding pin of the Core circuit (Pin 51) measure the voltage then adjust to about 2.5v by turning on RV2.
b) then move the stick to + 50%. (right for the horizontal sticks and at the top for the vertical sticks). The voltage should increase and if this is not the case, see page 10 and reverse the supply direction of the stick, if it is a potentiometer.
Page 24 | Construct your OpenAVRc 3.0 transmitter

Assignment of sleeves

P12 | P13
VL HL | VR HR

Warning

Due to the varying range of sticks, it may be necessary to adapt the gain of the 4 amplifiers by modifying R 11, 12, 13 and 14.
(You can do this by putting the R30 gain pot in the middle of its range and look for the right value of R12 with a potentiometer in place of the resistor.

Set R27 to obtain about 4.5 to 4.8V with the handle at max. If you can not get this voltage and your voltage is higher, it is that your stick has too much variation of the signal and you will decrease the amplifier gain by replacing R30 (120k) by a lower value. (47K - 68K should be suitable)

c) Max. stick, then adjust the voltage to 4.90V max using potentiometer R27.
d) Check that you have about 0.1V at the lower end of the stick.

If the variation is not the same in both directions, then there is nothing to do. It is the linearity of your knob potentiometer that is in question, but it is not serious ... the software will then adapt.
Perform the same procedure for the other sticks without seeking precision since we will adjust these values more finely thereafter.
At the end of the fourth, you should master the method!
In any case, you will need to calibrate the sticks when starting the transmitter as shown in the "Calibration" view on the next page.

### 6.3.2 Method 2

More practical to carry out, it can only be done if the transmitter is already operational.
- Access the "ANAS" 6/7 screen of the radio and consult the values delivered by each stick.
- With the stick at neutral, set the zero knob to obtain 0400 (H) points.
- With the stick at lowest end, set the gain knob to get 0020 (H) of the converter.
Check the maximum point: if your potentiometers are linear, you should get a value close to 07E0. Note: It may be necessary to resume settings if you need to adjust a large variation.
In any case, end with a neutral setting at 0400,

Then the Calibration" function will be carried out, whose goal it is to take the exact values of points of the neutral and each direction of each of the sticks, to assign them coefficients in order to allow precise calculations on the trims, the mixings , display, etc., and of course the calculation of the pulse width. In the end, a round will vary from -100% to + 100%
On the next view, "Ail" is on a black background, which shows a saturation of the signal, the mini voltage of the stick is too low which shows that the gain is too high on this way.
Page 25 | Construct your OpenAVRc 3.0 transmitter

Page 26 | Construct your OpenAVRc 3.0 transmitter

## 7 Screen preparation:

## 7.1 Recall pinout for P16

Pay attention to the cable for P16 when you wire it up since it might be in the wrong order (2,1,4,3, etc)

## 7.2 Screen Zollen (7565P)

Ideal screen for the reuse of small / medium cases

Info

If when you turn on the 7565P, your screen looks dark, do not worry, look at it sideways and try to access the contrast setting that may be "stuck" at 30. Going back to an intermediate value, your screen should be more visible!

Choose ST7565P in Desktop.
5V power supply.

Desolder R4 (80) and bridge R6 (68).

Page 27 | Construct your OpenAVRc 3.0 transmitter

Vdd +5V; RST A_Lcd; 7.3 Screen ARTRONIC (7565R); Choose ST7565R in Desktop.3.3V power supply.; Connector P16; To end; Page 28; Construct your OpenAVRc 3.0 transmitter

Arrangement of the connector P16 (2 lines of the top) to the pin layout of the Zolen (2 lines of the
bottom + diagram)

With this screen RV6 is not
necessary.
RV1, will allow the brightness
adjustment, the contrast being set
by software.
Note: In the documentations, it is
planned to insert a R of about 100
ohms in the line LCD_Light: this
resistor is already in place on the
Circuit (R10)

## 7.4 Screen ST 7920 :

RD PSB R W; Bla LCD; Blk Lcd; Info; This screen is particularly suitable if you have a Multiplex 30xx or 4000 transmitter; box; Pin 15 (PSB) of the display must be connected to + 5V to set the parallel mode.; Page 29; Construct your OpenAVRc 3.0 transmitter

Choose ST7920 in Desktop.
5V power supply.

Arrangement for P16 (top line) to ST7920 display pinout (type 12864B V2.0) (bottom line):
Vss

## 7.5 Screen KS108B :

Warning; V out; Lcd A0; RST Bla LCD; Blk Lcd; Look out :; Page 30; Construct your OpenAVRc 3.0 transmitter

There are several models of KS108 screens.
Our is the KS108 "B": Screen dimensions 61 * 44 mm

Choose KS108 in Desktop. 5V power supply.

RV1, RV6 and
R10 are on the
shield

Arrangement for the P16 connector (top line) to the pin assignment of the KS108A (bottom line of the
table):

Pin 7 of the screen should be connected to ground by a 1 kohms Resistor.
If the display is reversed, switch CS1 and CS2. (Pin 1 and 2 on the screen)

## 7.6 Summary of Arduino, Ports, P16 and Display Connections

Note: Column 2560 is for information only
The table is ordered according to the number of the pins of P16
2560 | Core | Port | P16 | Signal | 7565P | 7920 | KS108
OV Gnd | | | 1 | Blk Display | 14 | 20 | 20
OV Gnd | | | 2 | Vss | 10 | 1 | 3
+5V Vss | | | 3 | Vdd | 9 | 2 | 4
NC | NC | X | 4 | Vo or Vr (pt Medium RV1) | x | 3 | 5
NC | NC | x | 5 | Vee or Vout (towards 1 side of RV6) | x | 18 | 18
22 | 74 | A0 | 6 | DB0 | 1 | 7 | 9
23 | 71 | A1 | 7 | DB1 | 2 | 8 | 10
24 | 72 | A2 | 8 | DB2 | 3 | 9 | 11
25 | 69 | A3 | 9 | DB3 | 4 | 10 | 12
26 | 70 | A4 | 10 | DB4 | 5 | 11 | 13
27 | 67 | A5 | 11 | DB5 | 6 | 12 | 14
28 | 68 | A6 | 12 | DB6 | 7 | 13 | 15
29 | 65 | A7 | 13 | DB7 | 8 | 14 | 16
30 | 83 | C7 | 14 | /RD (or RD or E) | 16 | 6 | 8
31 | 84 | C6 | 15 | WR (or RW) | 15 | 5 | 7
32 | 85 | C5 | 16 | Lcd A0 (or RS, /DI) | 14 | 4 | 6
33 | 86 | C4 | 17 | :RST (or /RES) | 13 | 17 | 17
| | | 18 | Midpoint RV6 | x | x | 19
35 | 87 | C2 | 19 | Led Backlight 100 ohms | 11 | 19 | 20
34 | 87 | C3 | 20 | /CS (CS1) | 12 | 16 | 1
| | | | (CS2 on KS108) | X | X | 2
| | | | PSB | X | 15 | x
Remarks | x | | non-existent
KS108 | 1 | CS1 | Linked to Lcd_WR
| 2 | CS2 | Linked to Lcd_Cs
| 7 | R/W | Grounded by R 1k ohms
ST7920 | 15 | PSB | PSB signal to connect to + 5V
| 16 Not connected
| | | No RV6 potentiometer
7565P | | | No RV6 potentiometer
Page 31 | Construct your OpenAVRc 3.0 transmitter

## 8 Appendices :

8.1 Remove the TTL / RS232 converter from the FrSky DHT module.

The DHT module originally incorporates an RS232 <> TTL converter on the telemetry link.
This link is also used for updating the firmware of the module.
If you no longer want to update this module (there will be more new versions anyway) it is advisable to remove this converter, which will allow to directly connect these signals to the input telemetry outputs and avoids the RS232 / TTL converter wiring described on page 7 of this document.

In the end, the operation is relatively simple:
Locate the Tx and Rx exit points on the map
- On the circuit board, cut the two tracks arriving at these two points
- (the two yellow lines near C21 and R19)
- Directly connect Tx and Rx to the points shown in the following view
- It will of course be necessary to bridge the connections that are no longer made by the converter on the card by connecting the following points:
- Note: The blue link in the receive line is a 220 ohm resistor
Page 32 | Construct your OpenAVRc 3.0 transmitter

NOTE: If you are using the 2.1 shield, connect these points crosswise (1> 5 and 2> 6) to account for the error described at the beginning of the document

## 9 Placement of components :


Page 33 | Construct your OpenAVRc 3.0 transmitter

## 10 Various Tips

- Solder BT1 (clock battery connector) with an angled connector coming out under the JQ6500 (beware of short circuits with the pins of the core).
- Do not wire your SD card until you have tested all functions as it may block access to the F-Ram and clock if one of them fails.
- if your I2C port does not work (the F-Ram, the DS3231 clock and the SSD1306 use it), this can come from the defective DS3231. In this case, lift the legs 15 and 16 (sda and scl).
- For the adjustment of 4 sticks, there are 4 SMD pads (W1 to W4 solder side). For my part I preferred to place my multimeter tip on the legs 1,7,8 and 14 of the MCP604. This avoids turning over the shield.

Another solution: Place yourself on the corresponding pin of the Core circuit to benefit from a "non-slip" contact, see page 21.

- Some of us had problems with false contacts. A toothbrush with either alcohol to burn (my preference) or acetone (a strong one to my taste) can help you clean the shield of any solder particles.
- The PM-5033 is not easy to stock. The small DC-DC converter which is planned in double implantation of the 5v, can be an alternative solution. For easy installation, solder 4 two-point connectors on the shield (IN +, IN-, OUT + and OU-), then solder 4 x two-point connectors under the converter. Then solder all of the 4 connectors of the shield over the 3 large capacities.

If you notice any errors (and there are some), please contact me (pierrotm77) through the forum posts

Page 34 | Construct your OpenAVRc 3.0 transmitter

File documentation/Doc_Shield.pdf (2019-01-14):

# Câblage du shield MegaMini © Version 2.1

Page 1 | Réalisez votre émetteur OpenAVRc 3.0

# OpenAVRc

# Un émetteur RC Open Source basé sur le microcontrôleur AVR ATMega 2560 de chez ATMEL/Microchip

Copyright OpenAVRc 2018


Ce circuit est prévu pour le mega2560-Core de Inhaos (http://www.inhaos.com/product_info.php?products_id=118)


Page 2 | Réalisez votre émetteur OpenAVRc 3.0

Conseil :
Nous vous suggérons de lire et relire ce document et de vous en imprégner avant la réalisation.
Préférez une réalisation « fonction par fonction » et tester et vérifier le bon fonctionnement avant de passer à la phase suivante.
Ordre de réalisation suggéré
- Alimentations et connecteurs manches
- Amplificateur des manches
- Mise en place des différents connecteurs
- Ecran et circuit Core
A ce stade, vous pouvez alors mettre en route votre radio après avoir exploité le document « Compilez votre firmware OpenAVRc »
- Carte SD
- JQ6500
- etc
Avec le circuit livré câblé, on peut également envisager une seconde méthode, à savoir
- montage de l’alimentation
- montage de l’un des écrans
- mise en place des 3 connecteurs du Core
- configuration du circuit Core sur la base du document « Compilez votre FW »
- mise en place du Core
- mise sous tension ! Et vérification du fonctionnement
- suite du câblage
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

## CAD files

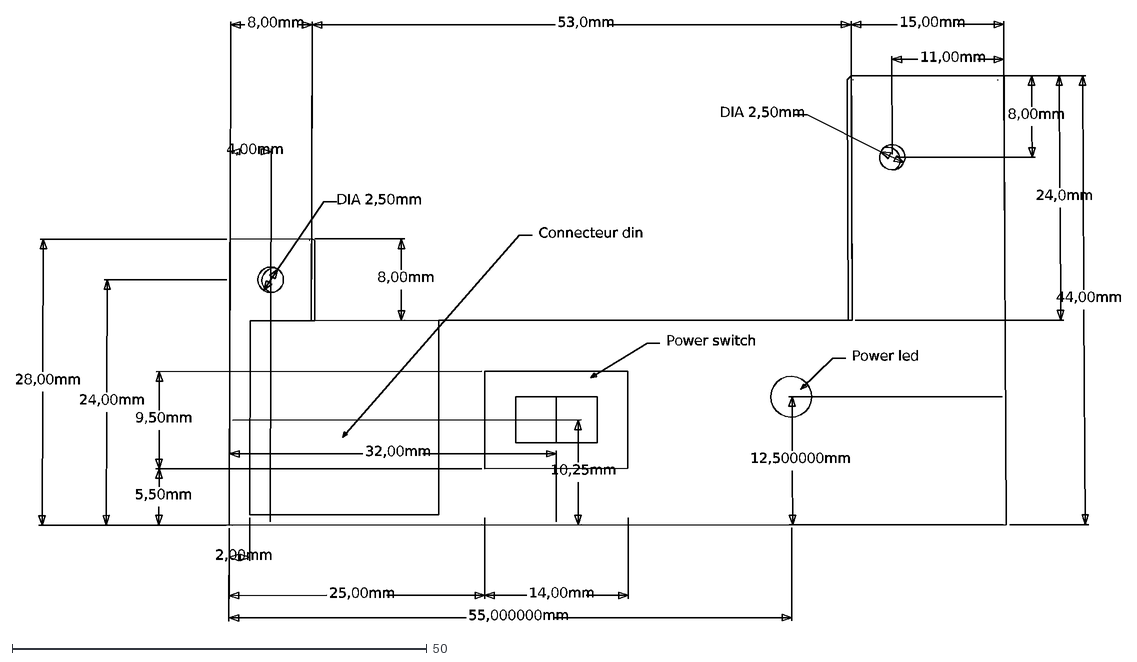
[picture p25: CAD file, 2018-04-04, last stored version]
PCB Mpx Alimentation/Docs/Platine_MPX_3030.dxf
28,00mm
8,00mm
DIA 2,50mm
53,0mm
15,00mm
24,00mm
4,00mm
Connecteur din
2,00mm
11,00mm
44,00mm
24,0mm
25,00mm
14,00mm
32,00mm
Power switch
5,50mm
9,50mm
10,25mm
55,000000mm
12,500000mm
Power led

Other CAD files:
documentation/NextStepRC_M2560/2_Case/MEGA2560_Case.dxf

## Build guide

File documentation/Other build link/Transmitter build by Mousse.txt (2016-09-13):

http://www.sitakiki.fr/modnaval/nextsteprc.htm

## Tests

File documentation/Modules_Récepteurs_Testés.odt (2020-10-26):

Les protocoles testés avec OpenAVRC

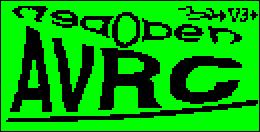
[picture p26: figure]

Copyright OpenAVRc 2020

# CE DOCUMENT

## Versions

Version | Date | Raison de l’évolution
0.1 | 26/08/2020 | Création

## Copyright

Ce document est Copyright © 2020 OpenAVRc.

## Avertissement

L’équipe OpenAVRc n’est aucunement responsable des dommages qui pourraient découler de la mauvaise utilisation ou d’un éventuel dysfonctionnement de l’émetteur OpenAVRc et/ou des logiciels associés.

Il appartient donc à l’utilisateur final d’en mesurer, d’en assumer les risques et de respecter la législation en vigueur selon le pays d’utilisation.

## Contenu

Ce document liste les différents protocoles testés, les modules à l’émission et les récepteurs utilisables.

# PRESENTATION GENERALE

## Vue d’ensemble

TX

RX

## Les modules RF utilisables un émetteur OpenAVRc

Connexion | | Dénomination/Spécifications | Fréquence | Note

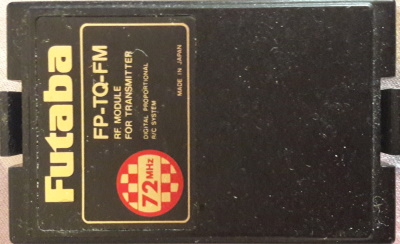
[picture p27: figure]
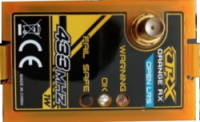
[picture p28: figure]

PPM | | | | Tout module RF compatible PPM. - Futaba 27Mhz/41Mhz/72Mhz - Orange Rx 433Mhz 100mW - Multi Protocoles 4en1 (https://github.com/pascallanger/DIY-Multiprotocol-TX-Module/blob/master/docs/Hardware.md). - etc...

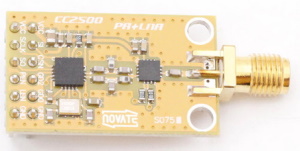
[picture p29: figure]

CC2500 Jaune | | SPIRfMod -FrSky D, V8, XFCC, XLBT -Corona DSSS V2 -Skyartec MultiMod -FrSky D16, D8, D16 8ch, V8, LBT(EU), LBT 8ch -Corona DSSS V2 | 2,4Ghz | SPIRfMod -Dans ce mode, les modules RF sont connectés directement au bus SPI dédié. MultiMod -Dans ce mode les modules RF connectés à un module MultiProtocol (https://www.rcgroups.com/forums/showthread.php?2165676-DIY-Multiprotocol-TX-Module) qui lui même est connecté à la radio par PPM ou une liaison série.
CYRF6936 | | SPIRfMod -DSM2 | 2,4Ghz

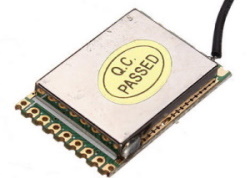
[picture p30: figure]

A7105 | | SPIRfMod -Flysky V911 MultiMod -Flysky V911 -Flysky AFHDS2A | 2,4Ghz | SPIRfMod -Dans ce mode, les modules RF sont connectés directement au bus SPI dédié. MultiMod -Dans ce mode les modules RF connectés à un module MultiProtocol (https://www.rcgroups.com/forums/showthread.php?2165676-DIY-Multiprotocol-TX-Module) qui lui même est connecté à la radio par PPM ou une liaison série.
NRF24L01+ | | SPIRfMod -Cabell MultiMod -Cabell -V911S | 2,4Ghz | SPIRfMod -Dans ce mode, les modules RF sont connectés directement au bus SPI dédié. MultiMod -Dans ce mode les modules RF connectés à un module MultiProtocol (https://www.rcgroups.com/forums/showthread.php?2165676-DIY-Multiprotocol-TX-Module) qui lui même est connecté à la radio par PPM ou une liaison série.

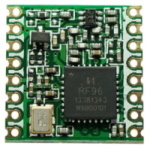
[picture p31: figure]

SX1276 | | MultiMod -Frsky R9 915Mhz/868Mhz FCC et LBT (16ch sans télémétrie et 8ch avec télémétrie) | 868Mhz 915Mhz

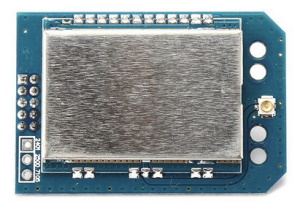
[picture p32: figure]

Multi Protocoles | | SPIRfMod -FrSky D, V8, XFCC, XLBT -Corona DSSS -DSM2 MultiMod -FrSky D16, D8, D16 8ch, V8, LBT(EU), LBT 8ch -Corona DSSS -Flysky V911 -Flysky AFHDS2A | 2,4Ghz | Ce module comprend : - 1 CC2500 - 1 CYRF6936 - 1 A7105 - 1 NRF24L01+ Liste des protocoles supportés (https://github.com/pascallanger/DIY-Multiprotocol-TX-Module/blob/master/Protocols_Details.md). Site Web :https://www.multi-module.org/

## Les récepteurs testés avec un émetteur OpenAVRc

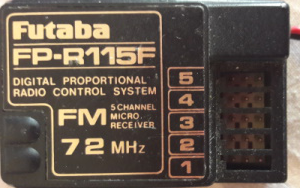
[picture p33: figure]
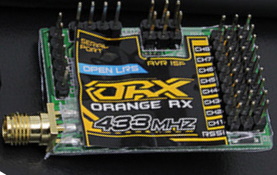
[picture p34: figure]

PPM
| Futaba 72Mhz | | | | OLRS 433Mhz

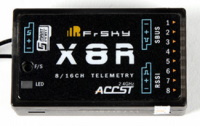
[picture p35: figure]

cc2500
| Frsky D16 | Frsky D8 | Frsky D8 | Frsky D8/V8 | Frsky D8/V8


| Frsky D16/D8/LBT | CR8D, CD6D et CR4D | Crazybee F4(D8) | Skyartec Rx-705


CYRF6936
| DSM2


A7105
| AFHDS2A


NRF24L01+ | Réalisation de ce récepteur Open Source ici (https://github.com/soligen2010/RC_RX_CABELL_V3_FHSS)
| Cabell | V911S


SX1276
| Frsky D16

Info | Télémétrie Frsky S-Port
| Télémétrie Frsky Hub

Page 0 Manuel Utilisateur MS16-Xany OpenAVRc 3.0

Page 7 Protocoles compatibles OpenAVRc 3.0




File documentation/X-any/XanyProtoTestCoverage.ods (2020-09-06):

X-any Test with the different protocols
Protocol | Tx Module | Rx Module (Receiver) | Tester | Results | Notes
PPM8 | 72 MHz Futaba FP-TQ-FM | 72 MHz 5 CH Futaba FP-R115F | Pierrotm777 | OK | Works with repetition=0
CORONA | 2.4GHz CC2500 | 2.4GHz 8 CH CR8D Corona | Pierrotm777 | OK | Works with repetition=2
DEVO CYRF6936
DSM SERIAL
DSM CYRF6936
FRSKYD | 2.4GHz CC2500 | 2.4GHz 8 CH RX-F-802 | Pierrotm777 | OK (except with CH5) | Works with repetition=2
FRSKYD | 2.4GHz CC2500 | 2.4GHz 8 CH X8R | Pierrotm777 | OK | Works with repetition=2
FRSKYX |  | 868MHz 8 CH R9 | Pierrotm777 | OK | Works with repetition=1
MULTI
SKYARTEC

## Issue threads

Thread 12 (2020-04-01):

No file "stamp-OpenAVRc.h"

stanekTM, 2020-04-01:
The header file is missing when assembled from the main "simulator" source.
Thanks George  :eagle:

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

Ingwie, 2020-04-01:
This file (Stamp-OpenAVRc.h) is created by the makefile of the firmware.
Build a firmware (do not clean it) and build the Simu ;-)

stanekTM, 2020-04-01:
Oh yes, but I still have a mistake, these files are certainly in processing, I will use the original sources.
Thank you George :key:
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

Ingwie, 2020-04-01:
I commit the correct file in one minute ....

Ingwie, 2020-04-01:
PierroTM777 tell me about this missing update : OUPS !

stanekTM, 2020-04-01:
I'm sorry Christophe :gear:
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

Ingwie, 2020-04-01:
No no, I think the wxsmith files are not updated : I work on a lot of part of the project at this time and miss some update.
One (last) minute please...

stanekTM, 2020-04-01:
Don't hurry Christophe,
can i translate translate to "setup.exe" from you.
When you build your update, I'll be happy to try everything.
I'm your servant  :yin_yang:
George

Ingwie, 2020-04-01:
Yes, do what you want....
Another job for me : An updated "builder" :+1:  .. in construction

Ingwie, 2020-04-01:
Link -> https://codeblocks.org/

stanekTM, 2020-04-01:
Thank you, I will explore this as a beginner, I need a syntax fix and the help I have with the visual studio that helps me with the Windows API and C ++.
Every day I enjoy OpenAVRc in the living room, race, polish the floor :czech_republic:

pierrotm777, 2020-04-02:
Je regarde ça ce matin. A+

Le mer. 1 avr. 2020 à 23:15, Bracame <notifications@github.com> a écrit :

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

stanekTM, 2020-04-02:
Thank you guys,
Already OK. I am the happiest owner of OpenAVRc :+1:

Closed 2020-04-01.

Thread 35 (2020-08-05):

Trainer Screen, Cal % values.

sloped-soarer, 2020-08-05:
The bottom line of the Trainer Screen displays the % values for PPM pulses. With a Multiplier of 1.0, this appears to be scaled to a standard ppm range of 1500us +- 500us  e.g. 2000us = 100%.
I suggest the scaling by default should be for the Openavrc PPM range of 1500 +- 512us. e.g. 2012us = 100%.
This might make more sense when looking at the servo output screen as currently 100% = 1988us.
8)

Ingwie, 2020-08-05:
Hi my friend, Ok it is a good modification.
Thanks

testeur68, 2020-08-06:
Hi Ritchie, I use this fonction every week for training. It's a good idea to standardise channel values. Best regards, testeur_68Envoyé depuis mon téléphone Huawei-------- Message original --------De : sloped-soarer <notifications@github.com>Date : mer. 5 août 2020 à 18:00À : Ingwie/OpenAVRc_Dev <OpenAVRc_Dev@noreply.github.com>Cc : Subscribed <subscribed@noreply.github.com>Objet : [Ingwie/OpenAVRc_Dev] Trainer Screen, Cal % values. (#35)
The bottom line of the Trainer Screen displays the % values for PPM pulses. With a Multiplier of 1.0, this appears to be scaled to a standard ppm range of 1500us +- 500us  e.g. 2000us = 100%.
I suggest the scaling by default should be for the Openavrc PPM range of 1500 +- 512us. e.g. 2012us = 100%.
This might make more sense when looking at the servo output screen as currently 100% = 1988us.
8)

—You are receiving this because you are subscribed to this thread.Reply to this email directly, view it on GitHub, or unsubscribe.

sloped-soarer, 2020-08-07:
Hello again. Well I never stop learning !.
So looking at the code i can see why 1500us +-500us  servo range was chosen to be +-100%. The integer mathematics is simple.
However 500us / 512us = 97.65625%. So trying  to solve this using integer maths and using a 16bit signed variable range was like trying to find the nearest fraction for PI.
Anyhow multiplying 500us by 41/21 gives 976.19047619 which is close enough, just below and displays correctly to 0.1%.
Please note, I am only proposing to change the displayed percentage.

To be honest, I think the trainer screen is a bit weird.
I did not realise that a long press of the enter button when on the "Cal" actually trimmed for the ppm centres being offset.
Also i think the multiplier is too coarse e.g. 10% steps whereas the Student weights for Ele, Ail ... are 1% steps.

Also i cannot understand why we throw away some of the resolution e.g. We read ppm values to 0.5us resolution, but instead we use 1us steps.

I will test this change a bit more before committing a change unless there are other comments.

Ingwie, 2020-08-08:
Thanks, I'm busy on another part of the code.
Do what you think is right, you have my full confidence.

Closed 2020-08-10.

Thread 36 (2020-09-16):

Protocol J6PRO doesn't work.

sloped-soarer, 2020-09-16:
Cant get the Protocol to work. Anybody else tested the Nine Eagles J6Pro protocol.

Ingwie, 2020-09-16:
Hi Rich,

I don't have a receiver -> Never tested here ...

pierrotm777, 2020-09-16:
Not this receiver. Never tested. Sorry.

pierrotm777, 2020-09-17:
MultiProtocol 4in1 modules accept the J6Pro protocol (code 22).

testeur68, 2020-09-17:
No sorry, I don't use this protocol, only Frsky receivers. JPEnvoyé depuis mon téléphone Huawei-------- Message original --------De : sloped-soarer <notifications@github.com>Date : mer. 16 sept. 2020 à 19:40À : Ingwie/OpenAVRc_Dev <OpenAVRc_Dev@noreply.github.com>Cc : Subscribed <subscribed@noreply.github.com>Objet : [Ingwie/OpenAVRc_Dev] Protocol J6PRO doesn't work. (#36)
Cant get the Protocol to work. Anybody else tested the Nine Eagles J6Pro protocol.

—You are receiving this because you are subscribed to this thread.Reply to this email directly, view it on GitHub, or unsubscribe.

sloped-soarer, 2020-09-17:
Thank You for Your replies.
My CYRF6936 SPI module works with Devo protocol and the receiver works with the J6PRO protocol selected via MultiProtocol 4in1 (Orange RX) module. So it must be the SPI protocol that has a bug.

I think this might take a while to fix. I'm thinking about putting the logic analyser on the old J6PRO transmitter and starting again.

Ingwie, 2020-09-17:
Hi, Yes, please do that Rich.

Whithout develloper like you : OpenAVRc never grown.

B.R. Christophe

sloped-soarer, 2020-09-17:
Okay ... It looks like J6PRO likes the CYRF manufacture id and not the Transmitter RF ID.
I just want to fly My old Heli.
Christophe. I will send You an email when My head is clear.

sloped-soarer, 2020-09-30:
I have a working protocol. Github to be updated.

Closed 2020-09-30.

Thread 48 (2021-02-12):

From Guilm @ modelisme.com

Ingwie, 2021-02-12:
A la mise sous tension de la radio, si la coche la case BT actif est restée cochée, on démarre par le Bluetooth avant d'avoir le boot normal. On a aussi l’écran Bluetooth qui s’affiche lorsque l’on revient sur la page Bluetooth sans rien demander => désactiver le Bluetooth lors de l’extinction de l’émetteur.
On peut être connecte au PC mais sans visualiser l'arborescence de la carte SD sur Desktop. On a juste un carré avec le - et un début de renvoi en pointillés. => il faut sortir de la page Bluetooth pour que desktop visualise la carte SD de l'émetteurs.
Si on reste en maitre sur l'émetteur, lors de la demande de connexion avec desktop on a erreur 8 comme réponse. Il faut être en esclave pour échanger avec le PC
Si on cherche à se connecter avec desktop alors qu'on est resté en mode élève (PPM/SIM), l'écran se rempli de signe qui correspondent à ce qui défile dans la fenêtre CLI
Si dans desktop on fait redémarrer, on a immédiatement sur l'émetteur retour a la page standard et le point d'exclamation inversé => remise en route hard de l'émetteur
Fiabiliser la gestion de Pb
Si un transfert se plante l’émetteur reste avec l’écran de transfert et aucune possibilité de l’éteindre sauf débrancher la batterie.
Si on a le message BT muet, au deuxième essai ce message n’apparait plus mais le module ne fonctionne toujours pas.
Gérer les fichiers existant dans les deux sens de copie (PC vers émetteur OK)

Fiabiliser les échanges
Si on veut se connecter au PC et que l’on est resté sur la page Bluetooth la réponse de desktop est « Erreur 8 port com »
Lors du scan parfois on a quelque chose qui ressemble à une adresse MAC au lieu d’avoir le nom du périphérique Bluetooth.
Il faut parfois 3 ou 4 scan pour visualiser la totalité des périphériques. Parfois les noms sont incomplets, parfois le nom du module interne n’est pas complet.

Quand on est sur la ligne Rôle sans avoir validé par menu, les flèches gauche et droite font passer de maitre a esclave et inversement. Dans cette config il arrive aussi que l'on ait le point d'exclamation à l'envers et la seule solution => remise en route de l'émetteur

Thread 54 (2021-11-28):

CRSF Protocol Support?

royyandzakiy, 2021-11-28:
Hi! I'm quite new in the rc space, but have been very interested in it's massive DIY community. I've been wondering, will there be any support of CRSF protocol, to for instance connect an OpenACRc transmitter to an external ExpressLRS transmitter module. Or have there been any such discussion about it?

I really want to be able to use an ExpressLRS module and this seems to be the barrier.

Thanks for the time reading this, really appreciate any information or such!

Ingwie, 2021-11-28:
Hi Royyan,

I'm actually working on ELRS serial protocol (And Hitec SPI ...).

To finish it -> Write he telemetry part (I don't understand some fields, perharps @AlessandroAU can give me some help :+1: )
and the menu.

We have a serial speed limitation : 115200 bauds, a test @500k bauds is possible.

Regards.

Christophe

AlessandroAU, 2021-12-01:
Hi guys, the telemetry protocol can be mostly found here https://github.com/ExpressLRS/ExpressLRS/tree/master/src/lib/CRSF and https://github.com/ExpressLRS/ExpressLRS/blob/master/src/lib/CrsfProtocol/crsf_protocol.h, the hardest part is MSP encapsulation. Best to come to the discord to ask more specific questions.

royyandzakiy, 2021-12-02:
Wow, thats really great @Ingwie !! I don't I could help, but sure will keep a lookout

I see, so currently it needs implementation of MSP encapsulation to finish it? @AlessandroAU

Ingwie, 2021-12-06:
Hi all,

I was far from home for my job.

Thanks Alessandro, i'll give another look at the source code. to try to understand.

RybOlya, 2023-01-27:
Hi, found this discussion, I am also wondering, isn't there yet any possibility to use openAVRc with expressLRS?

Ingwie, 2023-01-27:
Hi, CRSF is one of the serial protocols available.

I need to debug all telemetry and setting command.
-> No CRSF or expressLRS module here to test so it is hard to understand what is wrong.

You can give a try :+1:

Ingwie, 2023-01-27:
You where faster Pierro :1st_place_medal:

RybOlya, 2023-01-27:
@pierrotm777 @Ingwie That was a fast reply, thank you! I will try to give it go.

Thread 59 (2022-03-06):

Add some oled driver for DYmore 2.24" oled  SSD1309

EYITEA, 2022-03-06:
Hi, can you add this oled driver to the project.  I see it's very good if you add it, oled with a size of 2.24 " will add to the luxury of your project. I'm sure it is. Because we from Indonesia really like the look of oled with a larger size. thank you.

Ingwie, 2022-03-06:
Hi,

Where could i find this oled documentation ?

Did you read this documentation (page26) : https://github.com/Ingwie/OpenAVRc_Hw/blob/V3/PCB%20Shield/Mega_2560%20core%20mini_full_2.2_PM/ShieldV2.2_bleu.pdf
It explain how to use this kind of screen (switch SPI to I2C, etc ...)

testeur68, 2022-03-06:
Et pourquoi Ducros se décarcasse ? Merci Christophe. Envoyé depuis mon téléphone Huawei-------- Message original --------De : Bracame ***@***.***>Date : dim. 6 mars 2022 à 12:03À : Ingwie/OpenAVRc_Dev ***@***.***>Cc : Subscribed ***@***.***>Objet : Re: [Ingwie/OpenAVRc_Dev] Add some oled driver for DYmore 2.24" oled  SSD1309  (Issue #59)
Hi,
Where could i find this oled documentation ?
Did you read this documentation (page26) : https://github.com/Ingwie/OpenAVRc_Hw/blob/V3/PCB%20Shield/Mega_2560%20core%20mini_full_2.2_PM/ShieldV2.2_bleu.pdf
It explain how to use this kind of screen (switch SPI to I2C, etc ...)

—Reply to this email directly, view it on GitHub, or unsubscribe.Triage notifications on the go with GitHub Mobile for iOS or Android.
You are receiving this because you are subscribed to this thread.Message ID: ***@***.***>

EYITEA, 2022-03-06:
okay, thanks for all the help, I'll try it and greetings from Indonesia for all of them.

sloped-soarer, 2022-03-07:
I use an SSD1309 OLED for my project, but not the DIYMore version. In fact, i thought i gave a DIYMore OLED to @Ingwie.
Green OLED is okay in low light levels, but not so good outdoors. I also noted that some OLED displays put quite a bit of noise on the supply rails.
Just My opinion, best of luck.

EYITEA, 2022-03-08:
If so what is the impact on radio?  Does it affect the speed of data transmission?  Thank you

Ingwie, 2022-03-08:
Hi, Hello, Bonjour,
SSD1306 (1309) driver do the same job -> No impact.
Some LCD are faster and alow very low latency on very fast protocols.
I2C drivers "paint" the screen whith several pass to keep the better computation timing.
There is no low speed code in OpenAVRc to give to the pilot the better experience posiible.

EYITEA, 2022-03-09:
Very good information, I am very happy to meet you all.  I will continue to study to learn more about OpenAVRc.

EYITEA, 2022-11-18:
> Hi, Hello, Bonjour, SSD1306 (1309) driver do the same job -> No impact. Some LCD are faster and alow very low latency on very fast protocols. I2C drivers "paint" the screen whith several pass to keep the better computation timing. There is no low speed code in OpenAVRc to give to the pilot the better experience posiible.

Hi, I'm planning to implement RTC into my radio, but I'm using an i2c oled LCD type, if I want to implement it simultaneously, is that possible, or can I simply add a multiplexer module so that both can run simultaneously. Thanks.

pierrotm777, 2022-11-18:
Yes you can use rtc with an i2c screen. But sometime we need to remove the pull-up on sda and scl signals (only if you have some issue).

EYITEA, 2022-11-18:
Thanks for the information, I'll try it.

Ingwie, 2025-03-13:
Solved it was a SSH1106

Closed 2025-03-13.

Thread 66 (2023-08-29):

Cant get OrangeRx R614XN to bind in DSMX mode.

sloped-soarer, 2023-08-29:
Does anyone use DSMX 22ms ?.
I can't get this receiver to bind in DSMX 22ms mode. DSM2 22ms is okay though.

https://hobbyking.com/en_us/orangerx-r614xn-dsm2-dsmx-nano-indoor-diy-receiver-with-cppm-pwm-spektrum-jr-multirotor-quadcopter.html

pierrotm777, 2023-08-29:
I try to bind with a CM 703.
I have tried AUTO, DSMX and DSM2 without success !
Do you try with SPIRFMod or with a 4in1 module ?

sloped-soarer, 2023-08-29:
Thanks.
I was using SPIRFmod. No other way of testing at the moment to prove it's a receiver thing or otherwise.
SPIRFmod for DSM2 22ms binds OK, so code for that piece and CYRF6936 okay.

Ingwie, 2023-08-29:
Hi Rich and Pierre,

DSM was the second protocol i port to OpenAVRc to try to please Mentero ....

Just one DSM2 receiver to test (Thanks @jmentero) so no DSMX tested here ....

Rich -> Could you switch to "debug mode" ;-)

Ingwie, 2023-08-30:
Pierre, i said "so no DSMX tested here ...."

sloped-soarer, 2023-08-31:
Okay. Thank you all.
So the OrangeRx R614XN receiver does not bind in DSMX mode with my OrangeRx module running multiprotocol.
So in summary it looks like a receiver problem, unless i can find another transmitter to test it with.

sloped-soarer, 2023-09-03:
This gets more confusing !.
I took the same OrangeRx module which runs multiprotocol and put it in a Radio running EdgeTx.
It bound to the R614XN in DSMX 22ms mode.
The same module did not bind in a OpenAVRc transmitter using Multi or SPIRFmod.

What seems different is the binding time. Edge Tx seems to bind and complete in about four seconds.
OpenAVRc stays in bind mode until a key is pressed to exit  binding.
Maybe this prolonged bind causes the Rx to give up !.

sloped-soarer, 2023-10-23:
The new OpenAVRc Multi Module code fixes this.  SPIRFmod code may need some more investigation.

Closed 2023-10-23.

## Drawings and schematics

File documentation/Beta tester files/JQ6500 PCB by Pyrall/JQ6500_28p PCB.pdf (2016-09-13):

## Le circuit utilisé pour audio et voice JQ6500_28p

## WINTYPON / 08/09/2016

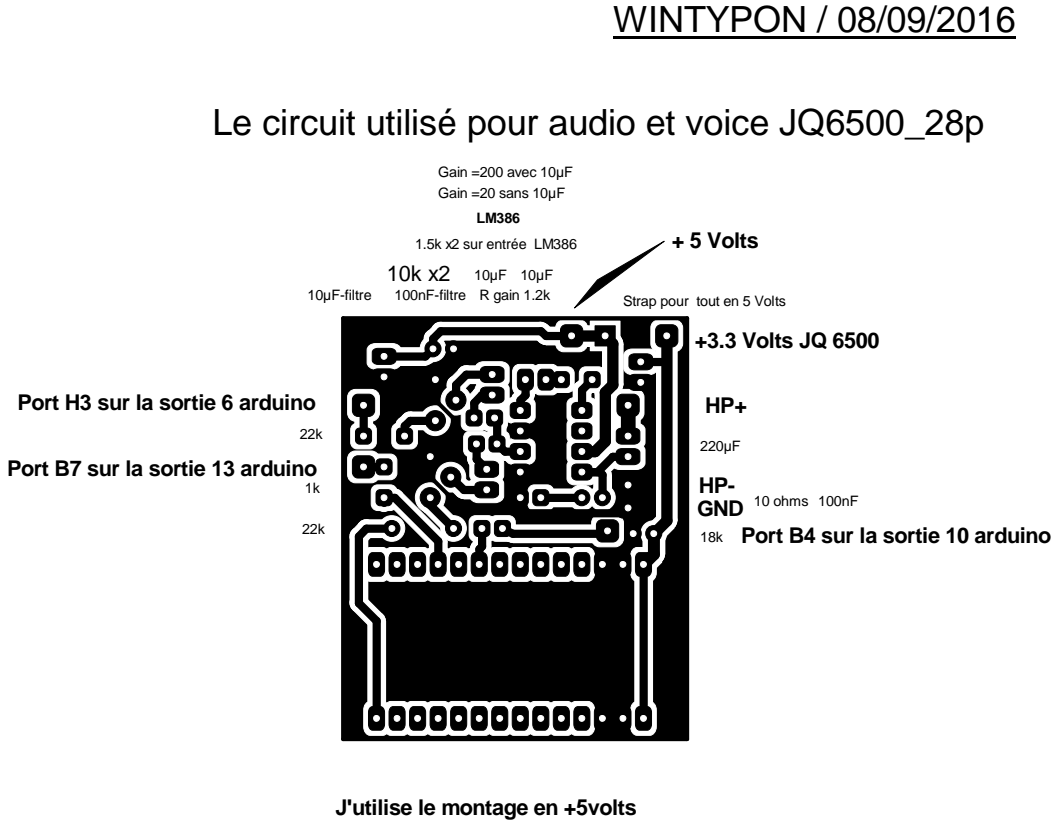
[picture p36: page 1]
GND; + 5 Volts; Gain =200 avec 10µF; 10 ohms 100nF; Gain =20 sans 10µF; 1.5k x2 sur entrée LM386; 10µF-filtre; 100nF-filtre R gain 1.2k

Strap pour tout en 5 Volts
+3.3 Volts JQ 6500

Port H3 sur la sortie 6 arduino

Port B7 sur la sortie 13 arduino

18k Port B4 sur la sortie 10 arduino ²²k

J'utilise le montage en +5volts

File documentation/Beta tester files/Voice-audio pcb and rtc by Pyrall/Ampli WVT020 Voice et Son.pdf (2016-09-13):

# Ampli WVT020 Voice et Son

1

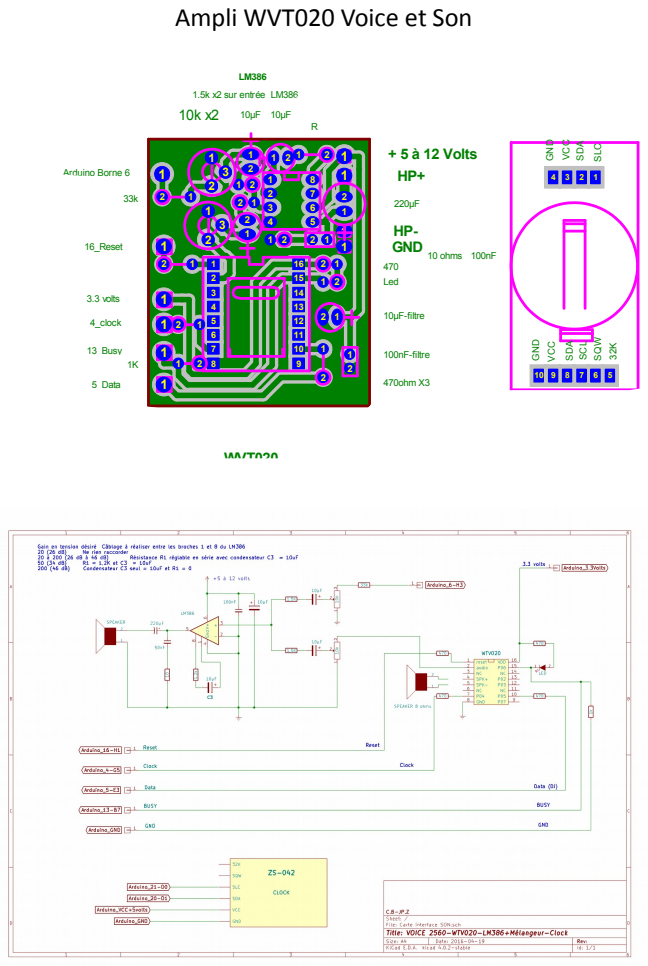
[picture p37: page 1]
GND; + 5 à 12 Volts HP+; 10 ohms 100nF; WVT020; 1.5k x2 sur entrée LM386; 4_clock; 16_Reset; 13_Busy; 3.3 volts; 5_Data; 470 Led; 470ohm X3; Arduino Borne 6; VCC; SDA; SCL; SLC; 10µF-filtre; 100nF-filtre

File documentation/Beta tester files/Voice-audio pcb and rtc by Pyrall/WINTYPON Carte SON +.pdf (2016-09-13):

## GND

## + 5 à 12 Volts

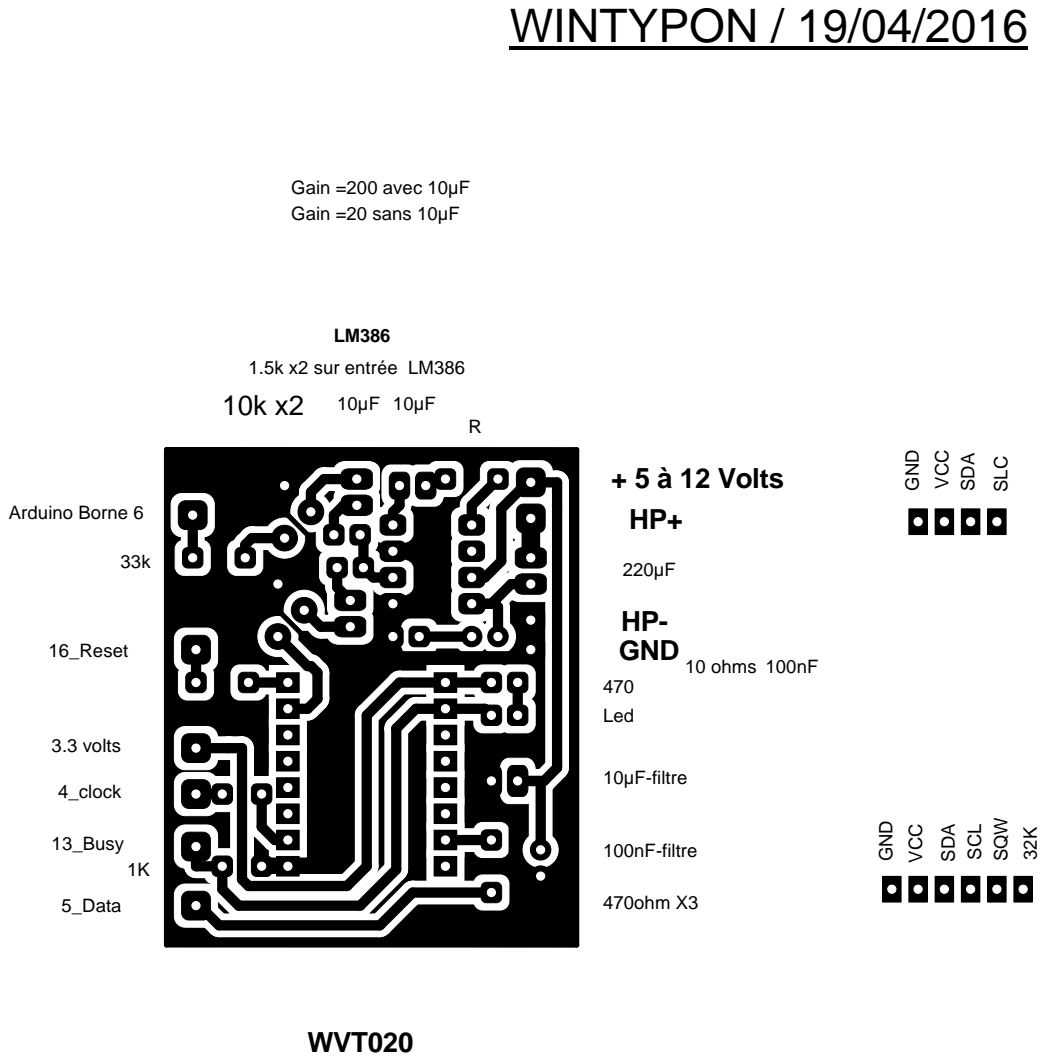
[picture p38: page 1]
Gain =200 avec 10µF; 10 ohms 100nF; Gain =20 sans 10µF; WVT020; 1.5k x2 sur entrée LM386; 4_clock; 16_Reset; 13_Busy; 3.3 volts; 5_Data; 470 Led; 470ohm X3; Arduino Borne 6; GND; VCC; SDA; SCL; SQW; SLC; 10µF-filtre; 100nF-filtre; WINTYPON / 19/04/2016

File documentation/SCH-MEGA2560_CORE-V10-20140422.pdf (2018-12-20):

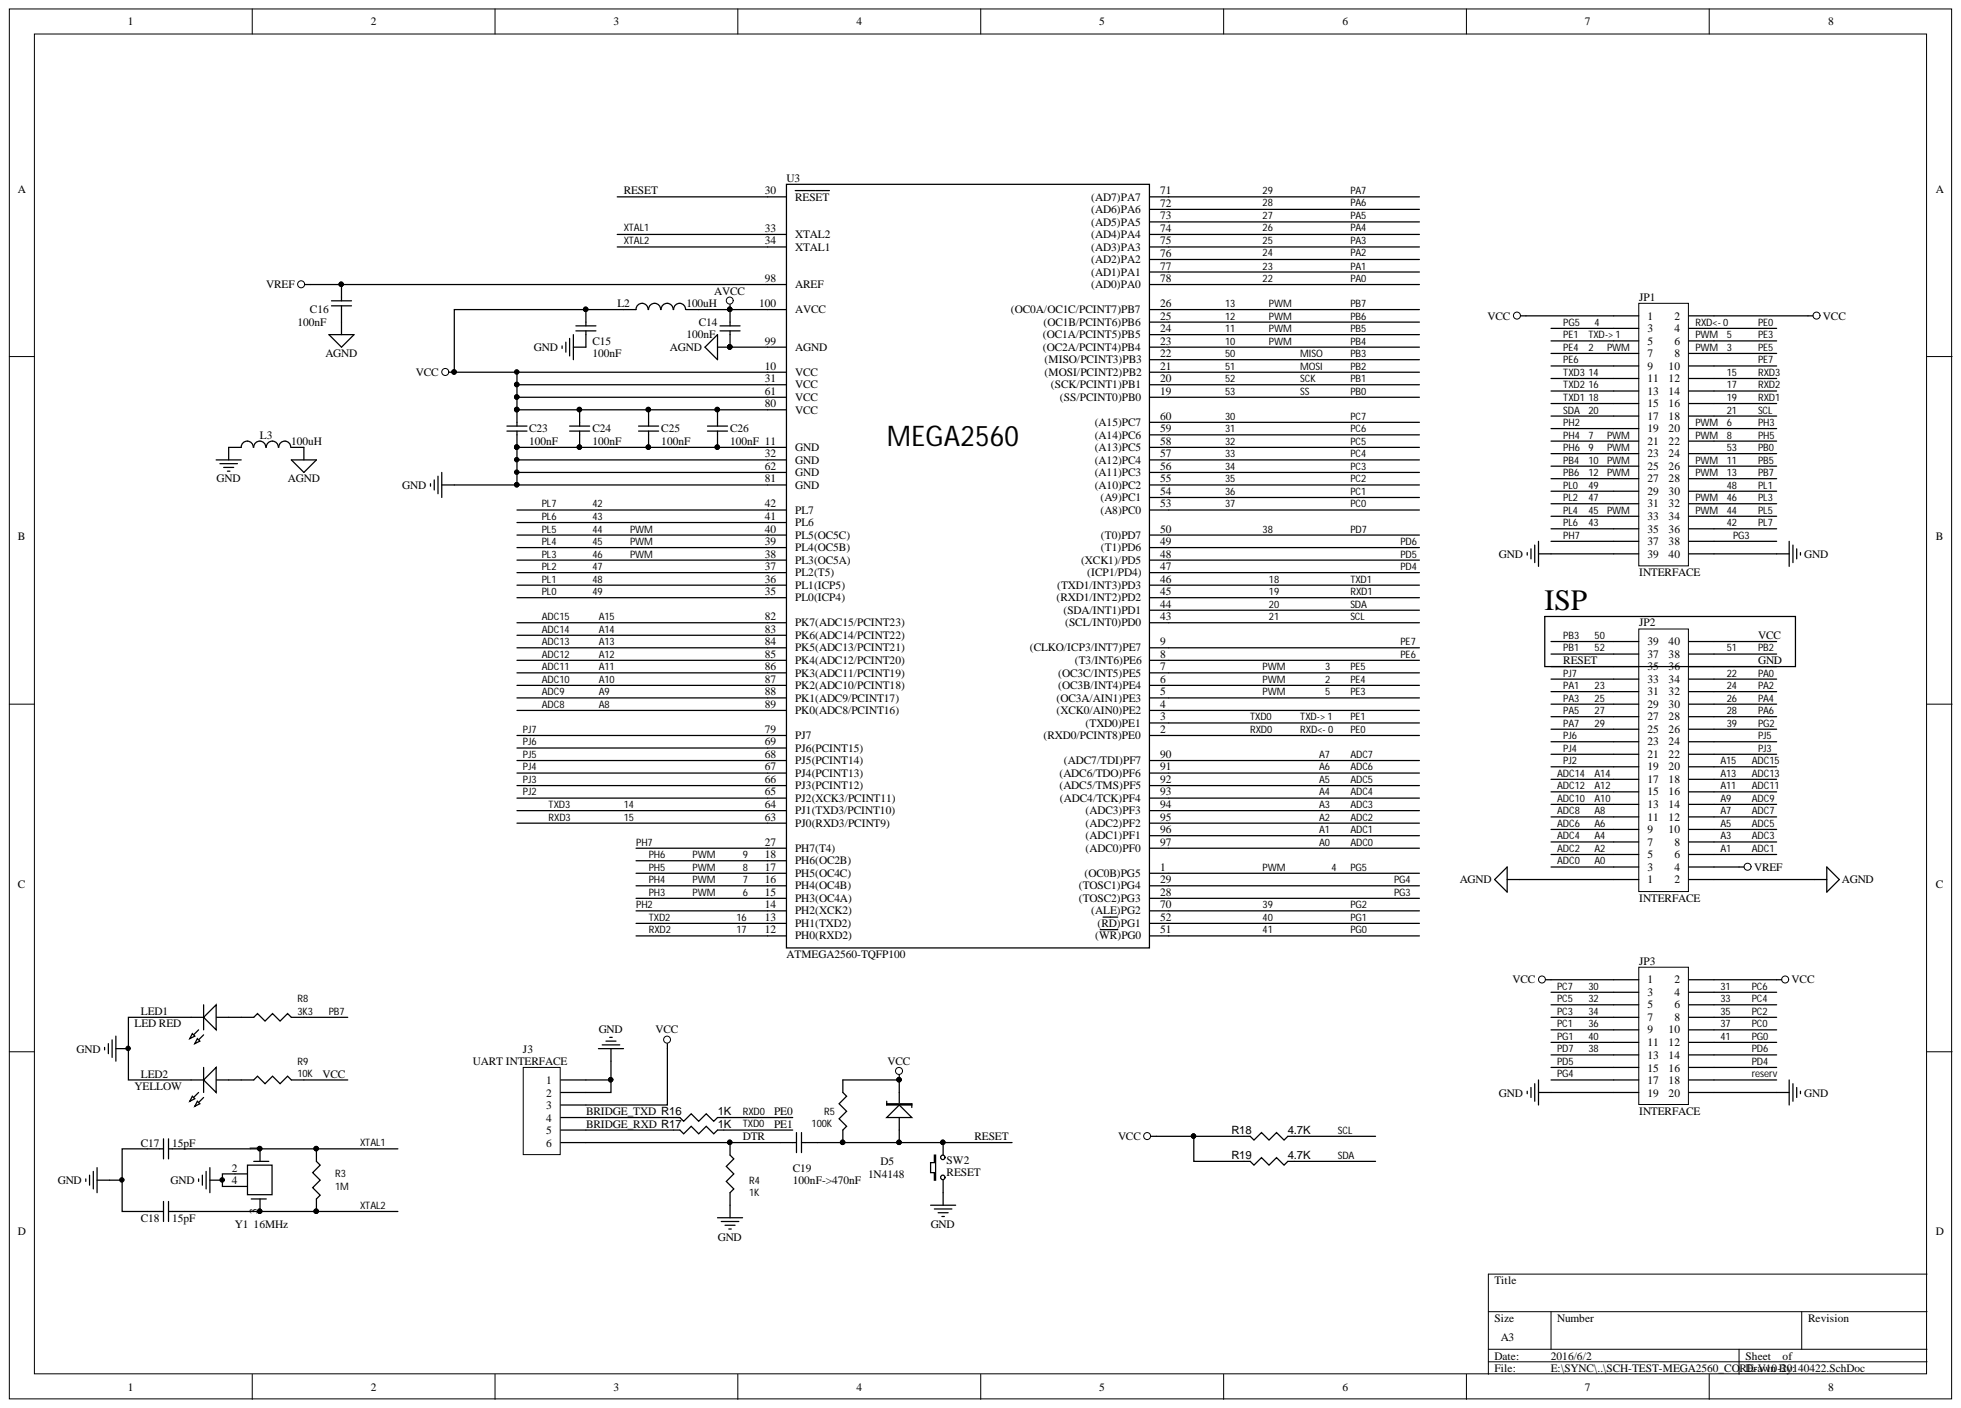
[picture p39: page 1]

PWM PWM

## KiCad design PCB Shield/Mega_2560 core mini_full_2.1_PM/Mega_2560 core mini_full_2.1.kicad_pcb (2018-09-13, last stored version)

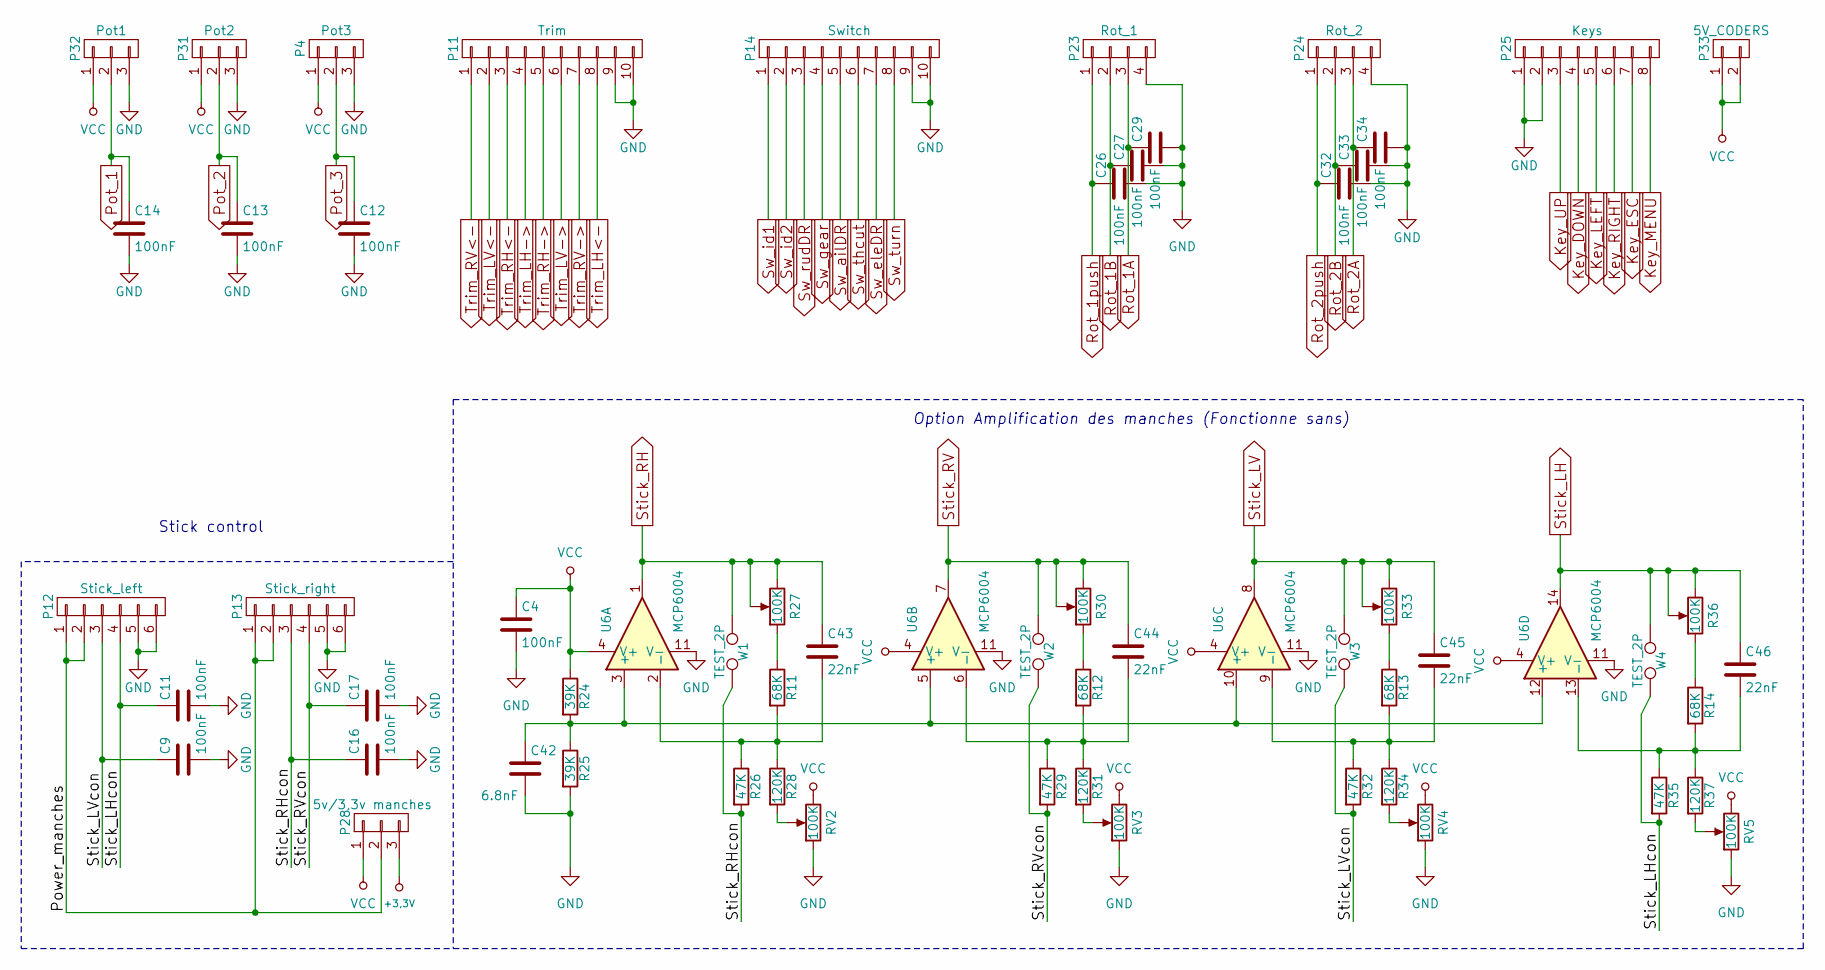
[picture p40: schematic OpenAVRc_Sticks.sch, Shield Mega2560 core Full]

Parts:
C4, C9, C11, C12, C13, C14, C16, C17, C26, C27, C29, C32, C33, C34: 100nF; C_1206
C42: 6.8nF; C_1206
C43, C44, C45, C46: 22nF; C_1206
P4: Pot3; Pin_Header_Straight_1x03_Pitch2.54mm
P11: Trim; Pin_Header_Straight_2x05_Pitch2.54mm
P12: Stick_left; Pin_Header_Straight_2x03_Pitch2.54mm
P13: Stick_right; Pin_Header_Straight_1x06_Pitch2.54mm
P14: Switch; Pin_Header_Straight_2x05_Pitch2.54mm
P23: Rot_1; Pin_Header_Straight_1x04_Pitch2.54mm
P24: Rot_2; Pin_Header_Straight_1x04_Pitch2.54mm
P25: Keys; Pin_Header_Straight_2x04_Pitch2.54mm
P28: 5v/3,3v manches; Pin_Header_Straight_1x03_Pitch2.54mm
P31: Pot2; Pin_Header_Straight_1x03_Pitch2.54mm
P32: Pot1; Pin_Header_Straight_1x03_Pitch2.54mm
P33: 5V_CODERS; Pin_Header_Straight_1x02_Pitch2.54mm
R11, R12, R13, R14: 68K; R_1206
R24, R25: 39K; R_1206
R26, R29, R32, R35: 47K; R_1206
R27, R30, R33, R36: 100K; Potentiometer_Trimmer_Bourns_3296W
R28, R31, R34, R37: 120K; R_1206
RV2, RV3, RV4, RV5: 100K; Potentiometer_Bourns_3296W_3-8Zoll_Inline_ScrewUp
U6: MCP6004; SOP14
W1, W2, W3, W4: TEST_2P; TESTPT

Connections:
+3.3V: P28.3; also elsewhere on the board
/OpenAVRc_Sticks/Power_manches: P12.1, P12.2, P13.1, P13.2, P28.2
/OpenAVRc_Sticks/Stick_LHcon: C11.1, P12.4, R35.2, W4.2
/OpenAVRc_Sticks/Stick_LVcon: C9.1, P12.3, R32.2, W3.2
/OpenAVRc_Sticks/Stick_RHcon: C16.1, P13.3, R26.2, W1.2
/OpenAVRc_Sticks/Stick_RVcon: C17.1, P13.4, R29.2, W2.2
GND: C4.2, C9.2, C11.2, C12.2, C13.2, C14.2, C16.2, C17.2, C26.2, C27.2, C29.2, C32.2, C33.2, C34.2, C42.2, P4.3, P11.9, P11.10, P12.5, P12.6, P13.5, P13.6, P14.9, P14.10, P23.4, P24.4, P25.1, P25.2, P31.3, P32.3, R25.2, RV2.1, RV3.1, RV4.1, RV5.1, U6.11 (V-); also elsewhere on the board
Key_DOWN: P25.4; also elsewhere on the board
Key_ESC: P25.7; also elsewhere on the board
Key_LEFT: P25.5; also elsewhere on the board
Key_MENU: P25.8; also elsewhere on the board
Key_RIGHT: P25.6; also elsewhere on the board
Key_UP: P25.3; also elsewhere on the board
unnamed: C42.1, R24.2, R25.1, U6.3 (+), U6.5 (+), U6.10 (+), U6.12 (+)
unnamed: C43.2, R11.2, R26.1, R28.1, U6.2 (-)
unnamed: C44.2, R12.2, R29.1, R31.1, U6.6 (-)
unnamed: C45.2, R13.2, R32.1, R34.1, U6.9 (-)
unnamed: C46.2, R14.2, R35.1, R37.1, U6.13 (-)
unnamed: R11.1, R27.1
unnamed: R12.1, R30.1
unnamed: R13.1, R33.1
unnamed: R14.1, R36.1
unnamed: R28.2, RV2.2
unnamed: R31.2, RV3.2
unnamed: R34.2, RV4.2
unnamed: R37.2, RV5.2
Pot_1: C14.1, P32.2; also elsewhere on the board
Pot_2: C13.1, P31.2; also elsewhere on the board
Pot_3: C12.1, P4.2; also elsewhere on the board
Rot_1A: C29.1, P23.3; also elsewhere on the board
Rot_1B: C27.1, P23.2; also elsewhere on the board
Rot_1push: C26.1, P23.1; also elsewhere on the board
Rot_2A: C34.1, P24.3; also elsewhere on the board
Rot_2B: C33.1, P24.2; also elsewhere on the board
Rot_2push: C32.1, P24.1; also elsewhere on the board
Stick_LH: C46.1, R36.2, R36.3, U6.14, W4.1; also elsewhere on the board
Stick_LV: C45.1, R33.2, R33.3, U6.8, W3.1; also elsewhere on the board
Stick_RH: C43.1, R27.2, R27.3, U6.1, W1.1; also elsewhere on the board
Stick_RV: C44.1, R30.2, R30.3, U6.7, W2.1; also elsewhere on the board
Sw_ailDR: P14.5; also elsewhere on the board
Sw_eleDR: P14.7; also elsewhere on the board
Sw_gear: P14.4; also elsewhere on the board
Sw_id1: P14.1; also elsewhere on the board
Sw_id2: P14.2; also elsewhere on the board
Sw_rudDR: P14.3; also elsewhere on the board
Sw_thcut: P14.6; also elsewhere on the board
Sw_turn: P14.8; also elsewhere on the board
Trim_LH->: P11.4; also elsewhere on the board
Trim_LH<-: P11.8; also elsewhere on the board
Trim_LV->: P11.6; also elsewhere on the board
Trim_LV<-: P11.2; also elsewhere on the board
Trim_RH->: P11.5; also elsewhere on the board
Trim_RH<-: P11.3; also elsewhere on the board
Trim_RV->: P11.7; also elsewhere on the board
Trim_RV<-: P11.1; also elsewhere on the board
VCC: C4.1, P4.1, P28.1, P31.1, P32.1, P33.1, P33.2, R24.1, RV2.3, RV3.3, RV4.3, RV5.3, U6.4 (V+); also elsewhere on the board

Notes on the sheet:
Stick control
Option Amplification des manches (Fonctionne sans)

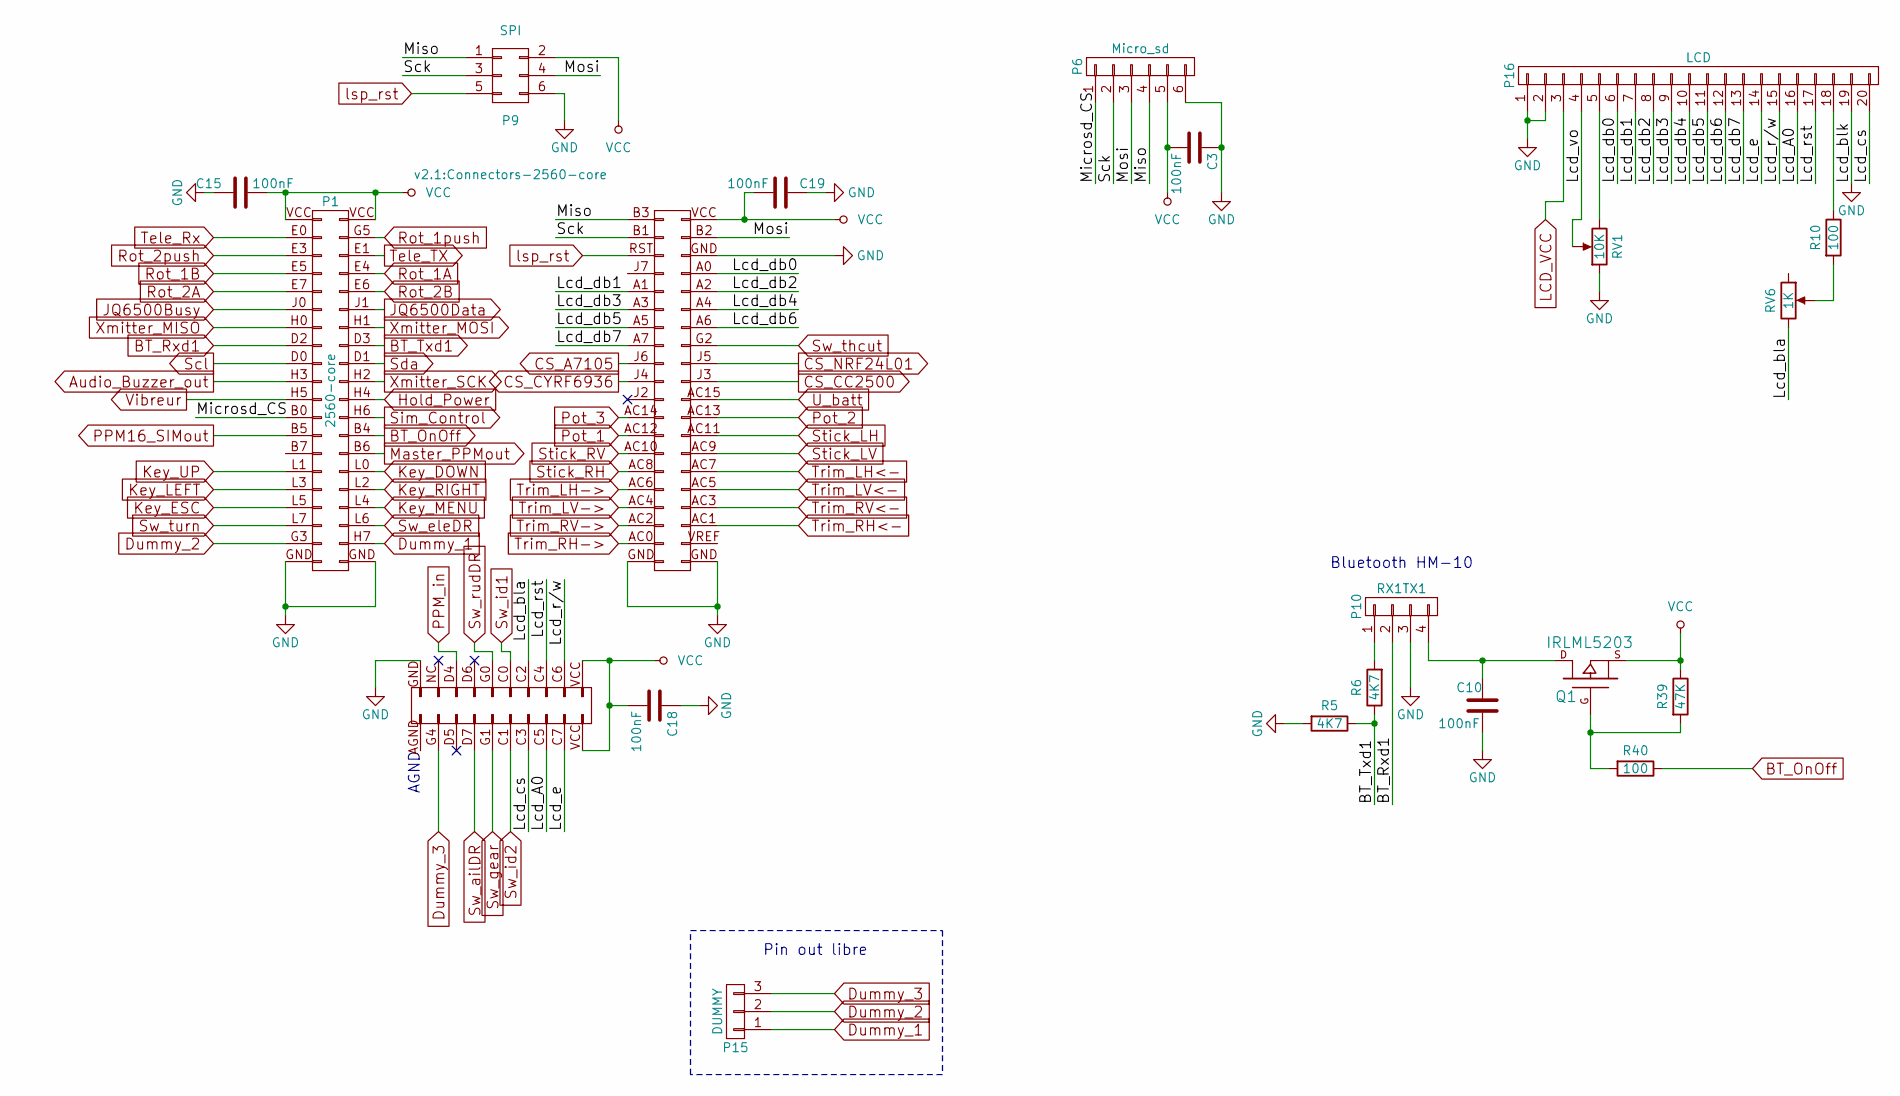
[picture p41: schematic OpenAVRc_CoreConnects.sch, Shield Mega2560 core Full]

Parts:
C3, C10, C15, C18, C19: 100nF; C_1206
P1: 2560-core; Connectors-2560-core
P6: Micro_sd; Pin_Header_Straight_1x06_Pitch2.54mm
P9: SPI; Pin_Header_Straight_2x03_Pitch2.54mm
P10: RX1TX1; Pin_Header_Straight_1x04_Pitch2.54mm
P15: DUMMY; Pin_Header_Straight_1x03_Pitch2.54mm
P16: LCD; Pin_Header_Straight_2x10_Pitch2.54mm
Q1: IRLML5203; SOT-23_MOS_P
R5, R6: 4K7; R_1206
R10, R40: 100; R_1206
R39: 47K; R_1206
RV1: 10K; trimpot_5x5_vertical
RV6: 1K; trimpot_5x5_vertical

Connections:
/OpenAVRc_CoreConnects/Lcd_A0: P1.C5 (P85), P16.16
/OpenAVRc_CoreConnects/Lcd_bla: P1.C2 (P88), RV6.3
/OpenAVRc_CoreConnects/Lcd_cs: P1.C3 (P87), P16.20
/OpenAVRc_CoreConnects/Lcd_db0: P1.A0 (P74), P16.6
/OpenAVRc_CoreConnects/Lcd_db1: P1.A1 (P71), P16.7
/OpenAVRc_CoreConnects/Lcd_db2: P1.A2 (P72), P16.8
/OpenAVRc_CoreConnects/Lcd_db3: P1.A3 (P69), P16.9
/OpenAVRc_CoreConnects/Lcd_db4: P1.A4 (P70), P16.10
/OpenAVRc_CoreConnects/Lcd_db5: P1.A5 (P67), P16.11
/OpenAVRc_CoreConnects/Lcd_db6: P1.A6 (P68), P16.12
/OpenAVRc_CoreConnects/Lcd_db7: P1.A7 (P65), P16.13
/OpenAVRc_CoreConnects/Lcd_e: P1.C7 (P83), P16.14
/OpenAVRc_CoreConnects/Lcd_r/w: P1.C6 (P84), P16.15
/OpenAVRc_CoreConnects/Lcd_rst: P1.C4 (P86), P16.17
/OpenAVRc_CoreConnects/Lcd_vo: P16.4, RV1.2
/OpenAVRc_CoreConnects/Microsd_CS: P1.B0 (P24), P6.1
/OpenAVRc_CoreConnects/Miso: P1.B3 (P79), P6.4, P9.1
/OpenAVRc_CoreConnects/Mosi: P1.B2 (P78), P6.3, P9.4
/OpenAVRc_CoreConnects/Sck: P1.B1 (P77), P6.2, P9.3
Audio_Buzzer_out: P1.H3 (P20); also elsewhere on the board
BT_OnOff: P1.B4 (P25), R40.1
BT_Rxd1: P1.D2 (P16), P10.2
BT_Txd1: P1.D3 (P15), R5.1, R6.1
CS_A7105: P1.J6 (P63); also elsewhere on the board
CS_CC2500: P1.J3 (P62); also elsewhere on the board
CS_CYRF6936: P1.J4 (P61); also elsewhere on the board
CS_NRF24L01: P1.J5 (P64); also elsewhere on the board
Dummy_1: P1.H7 (P37), P15.1
Dummy_2: P1.G3 (P38), P15.2
Dummy_3: P1.G4 (P97), P15.3
GND: C3.1, C10.2, C15.1, C18.1, C19.1, P1.GND (P100), P6.6, P9.6, P10.3, P16.1, P16.2, P16.19, R5.2, RV1.1; also elsewhere on the board
Hold_Power: P1.H4 (P21); also elsewhere on the board
JQ6500Busy: P1.J0 (P12); also elsewhere on the board
JQ6500Data: P1.J1 (P11); also elsewhere on the board
Key_DOWN: P1.L0 (P29); also elsewhere on the board
Key_ESC: P1.L5 (P34); also elsewhere on the board
Key_LEFT: P1.L3 (P32); also elsewhere on the board
Key_MENU: P1.L4 (P33); also elsewhere on the board
Key_RIGHT: P1.L2 (P31); also elsewhere on the board
Key_UP: P1.L1 (P30); also elsewhere on the board
LCD_VCC: P16.3; also elsewhere on the board
Master_PPMout: P1.B6 (P27); also elsewhere on the board
unnamed: C10.1, P10.4, Q1.D
unnamed: P10.1, R6.2
unnamed: P16.5, RV1.3
unnamed: P16.18, R10.1
unnamed: Q1.G, R39.2, R40.2
unnamed: R10.2, RV6.2
PPM16_SIMout: P1.B5 (P26); also elsewhere on the board
PPM_in: P1.D4 (P96); also elsewhere on the board
Pot_1: P1.AC12 (P55); also elsewhere on the board
Pot_2: P1.AC13 (P58); also elsewhere on the board
Pot_3: P1.AC14 (P57); also elsewhere on the board
Rot_1A: P1.E4 (P7); also elsewhere on the board
Rot_1B: P1.E5 (P8); also elsewhere on the board
Rot_1push: P1.G5 (P3); also elsewhere on the board
Rot_2A: P1.E7 (P10); also elsewhere on the board
Rot_2B: P1.E6 (P9); also elsewhere on the board
Rot_2push: P1.E3 (P6); also elsewhere on the board
Scl: P1.D0 (P18); also elsewhere on the board
Sda: P1.D1 (P17); also elsewhere on the board
Sim_Control: P1.H6 (P23); also elsewhere on the board
Stick_LH: P1.AC11 (P56); also elsewhere on the board
Stick_LV: P1.AC9 (P54); also elsewhere on the board
Stick_RH: P1.AC8 (P51); also elsewhere on the board
Stick_RV: P1.AC10 (P53); also elsewhere on the board
Sw_ailDR: P1.D7 (P93); also elsewhere on the board
Sw_eleDR: P1.L6 (P35); also elsewhere on the board
Sw_gear: P1.G1 (P91); also elsewhere on the board
Sw_id1: P1.C0 (P90); also elsewhere on the board
Sw_id2: P1.C1 (P89); also elsewhere on the board
Sw_rudDR: P1.G0 (P92); also elsewhere on the board
Sw_thcut: P1.G2 (P66); also elsewhere on the board
Sw_turn: P1.L7 (P36); also elsewhere on the board
Tele_RX: P1.E0 (P4); also elsewhere on the board
Tele_TX: P1.E1 (P5); also elsewhere on the board
Trim_LH->: P1.AC6 (P49); also elsewhere on the board
Trim_LH<-: P1.AC7 (P52); also elsewhere on the board
Trim_LV->: P1.AC4 (P47); also elsewhere on the board
Trim_LV<-: P1.AC5 (P50); also elsewhere on the board
Trim_RH->: P1.AC0 (P43); also elsewhere on the board
Trim_RH<-: P1.AC1 (P46); also elsewhere on the board
Trim_RV->: P1.AC2 (P45); also elsewhere on the board
Trim_RV<-: P1.AC3 (P48); also elsewhere on the board
U_batt: P1.AC15 (P60); also elsewhere on the board
VCC: C3.2, C15.2, C18.2, C19.2, P1.VCC (P1), P6.5, P9.2, Q1.S, R39.1; also elsewhere on the board
Vibreur: P1.H5 (P22); also elsewhere on the board
Xmitter_MISO: P1.H0 (P14); also elsewhere on the board
Xmitter_MOSI: P1.H1 (P13); also elsewhere on the board
Xmitter_SCK: P1.H2 (P19); also elsewhere on the board
lsp_rst: P1.RST (P75), P9.5; also elsewhere on the board

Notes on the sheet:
Bluetooth HM-10
Pin out libre
AGND

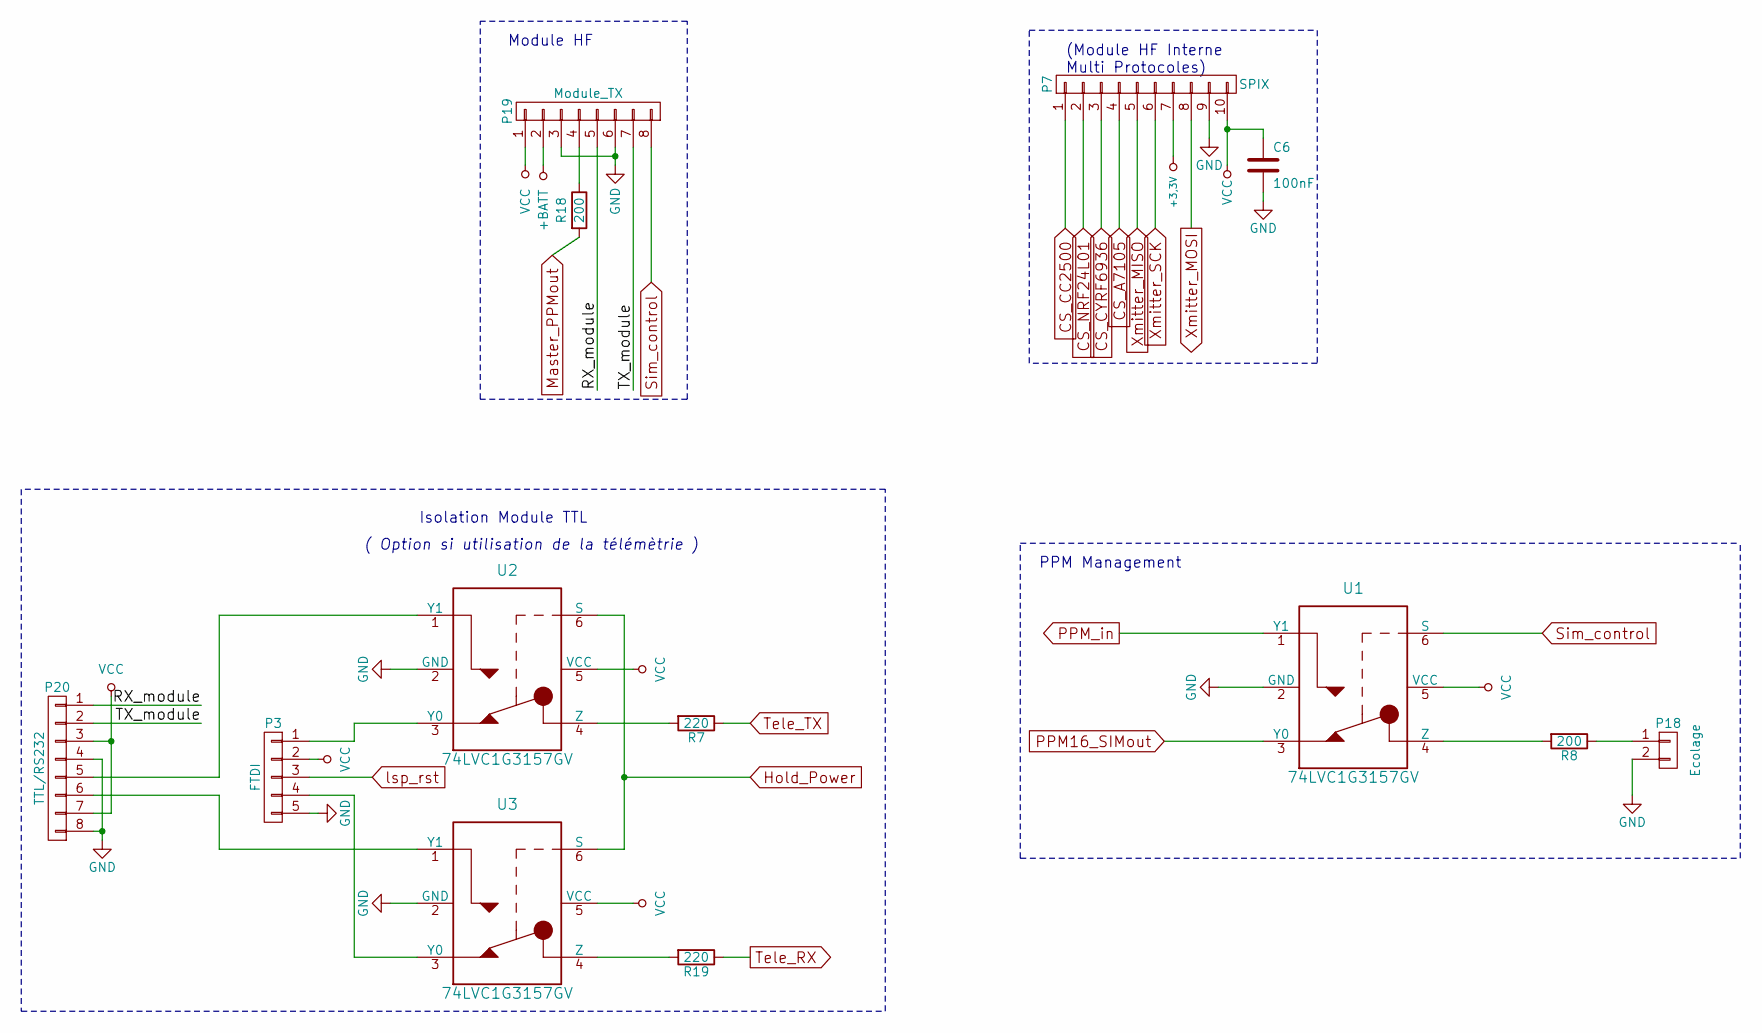
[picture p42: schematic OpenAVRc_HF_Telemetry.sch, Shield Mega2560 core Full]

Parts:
C6: 100nF; C_1206
P3: FTDI; Pin_Header_Straight_1x05_Pitch2.54mm
P7: SPIX; Pin_Header_Straight_2x05_Pitch2.54mm
P18: Ecolage; Pin_Header_Straight_1x02_Pitch2.54mm
P19: Module_TX; Pin_Header_Straight_2x04_Pitch2.54mm
P20: TTL/RS232; Con_RS232_TTL
R7, R19: 220; R_1206
R8, R18: 200; R_1206
U1, U2, U3: 74LVC1G3157GV; SOT-457

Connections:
+3.3V: P7.7; also elsewhere on the board
+BATT: P19.2; also elsewhere on the board
/OpenAVRc_HF_Telemetry/RX_module: P19.5, P20.1
/OpenAVRc_HF_Telemetry/TX_module: P19.7, P20.2
CS_A7105: P7.4; also elsewhere on the board
CS_CC2500: P7.1; also elsewhere on the board
CS_CYRF6936: P7.3; also elsewhere on the board
CS_NRF24L01: P7.2; also elsewhere on the board
GND: C6.2, P3.5, P7.9, P18.2, P19.3, P19.6, P20.4, P20.8, U1.2 (GND), U2.2 (GND), U3.2 (GND); also elsewhere on the board
Hold_Power: U2.6 (S), U3.6 (S); also elsewhere on the board
Master_PPMout: R18.2; also elsewhere on the board
unnamed: P3.1, U2.3 (Y0)
unnamed: P3.4, U3.3 (Y0)
unnamed: P18.1, R8.1
unnamed: P19.4, R18.1
unnamed: P20.5, U2.1 (Y1)
unnamed: P20.6, U3.1 (Y1)
unnamed: R7.2, U2.4 (Z)
unnamed: R8.2, U1.4 (Z)
unnamed: R19.2, U3.4 (Z)
PPM16_SIMout: U1.3 (Y0); also elsewhere on the board
PPM_in: U1.1 (Y1); also elsewhere on the board
Sim_Control: P19.8, U1.6 (S); also elsewhere on the board
Tele_RX: R19.1; also elsewhere on the board
Tele_TX: R7.1; also elsewhere on the board
VCC: C6.1, P3.2, P7.10, P19.1, P20.3, P20.7, U1.5 (VCC), U2.5 (VCC), U3.5 (VCC); also elsewhere on the board
Xmitter_MISO: P7.5; also elsewhere on the board
Xmitter_MOSI: P7.8; also elsewhere on the board
Xmitter_SCK: P7.6; also elsewhere on the board
lsp_rst: P3.3; also elsewhere on the board

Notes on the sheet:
Isolation Module TTL
PPM Management
( Option si utilisation de la télémètrie )
Module HF
(Module HF Interne Multi Protocoles)

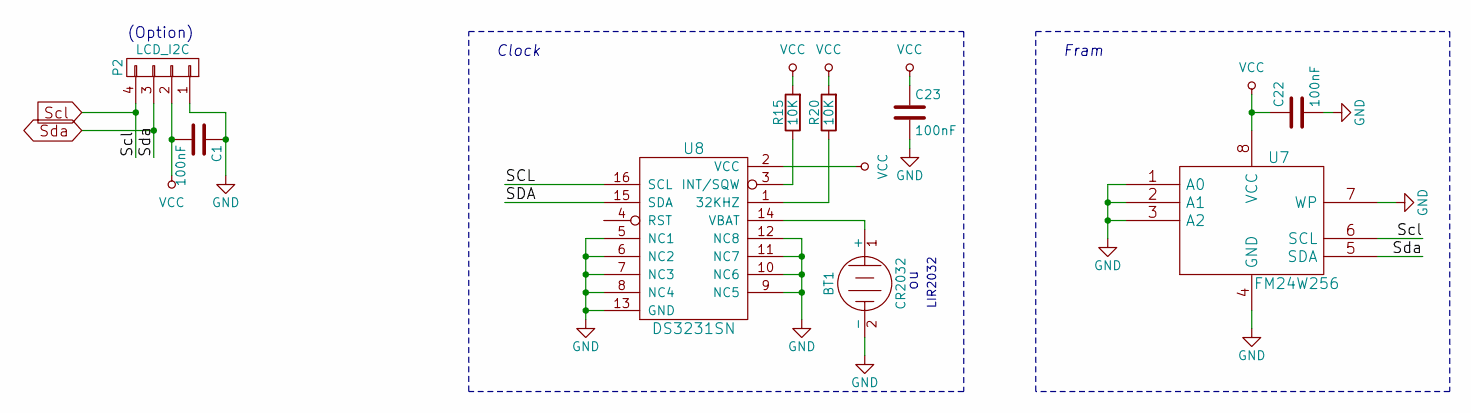
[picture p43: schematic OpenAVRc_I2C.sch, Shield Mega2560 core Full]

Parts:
BT1: CR2032; Pin_Header_Straight_1x02_Pitch2.54mm
C1, C22, C23: 100nF; C_1206
P2: LCD_I2C; Pin_Header_Straight_1x04_Pitch2.54mm
R15, R20: 10K; R_1206
U7: FM24W256; SOIC-8-FRAM_DI
U8: DS3231SN; SO-16-DS3231

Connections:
GND: BT1.2 (-), C1.1, C22.2, C23.2, P2.1, U7.1 (A0), U7.2 (A1), U7.3 (A2), U7.4 (GND), U7.7 (WP), U8.5 (NC1), U8.6 (NC2), U8.7 (NC3), U8.8 (NC4), U8.9 (NC5), U8.10 (NC6), U8.11 (NC7), U8.12 (NC8), U8.13 (GND); also elsewhere on the board
unnamed: BT1.1 (+), U8.14 (VBAT)
unnamed: R15.1, U8.3 (INT/SQW)
unnamed: R20.1, U8.1 (32KHZ)
Scl: P2.4, U7.6 (SCL), U8.16 (SCL); also elsewhere on the board
Sda: P2.3, U7.5 (SDA), U8.15 (SDA); also elsewhere on the board
VCC: C1.2, C22.1, C23.1, P2.2, R15.2, R20.2, U7.8 (VCC), U8.2 (VCC); also elsewhere on the board

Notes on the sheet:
Clock
Fram
LIR2032
(Option)

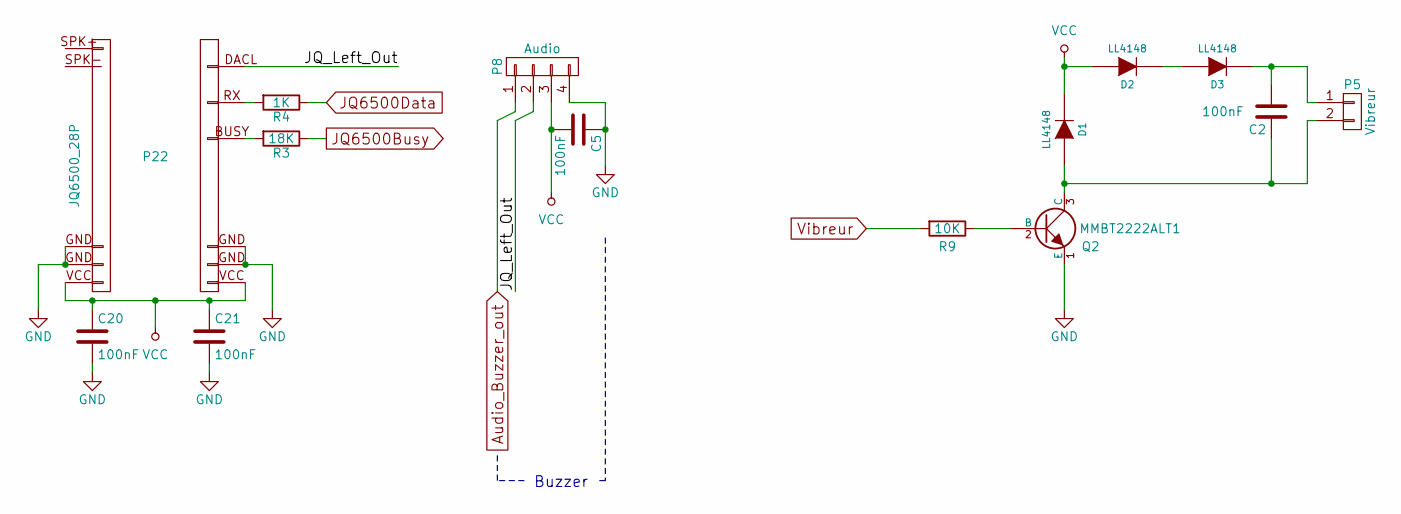
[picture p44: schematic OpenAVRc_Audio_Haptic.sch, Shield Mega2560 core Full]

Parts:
C2, C5, C20, C21: 100nF; C_1206
D1, D2, D3: LL4148; D_SOD-123
P5: Vibreur; Pin_Header_Straight_1x02_Pitch2.54mm
P8: Audio; Pin_Header_Straight_1x04_Pitch2.54mm
P22: JQ6500_28P; connector_mini-JQ6500-28P
Q2: MMBT2222ALT1; SOT-23_MMBT2222
R3: 18K; R_1206
R4: 1K; R_1206
R9: 10K; R_1206

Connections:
/OpenAVRc_Audio_Haptic/JQ_Left_Out: P8.2, P22.DACL (P16)
Audio_Buzzer_out: P8.1; also elsewhere on the board
GND: C5.1, C20.2, C21.2, P8.4, P22.GND (P12), Q2.1 (E); also elsewhere on the board
JQ6500Busy: R3.1; also elsewhere on the board
JQ6500Data: R4.1; also elsewhere on the board
unnamed: C2.1, D1.1 (A), P5.2, Q2.3 (C)
unnamed: C2.2, D3.2 (K), P5.1
unnamed: D2.2 (K), D3.1 (A)
unnamed: P22.BUSY (P20), R3.2
unnamed: P22.RX (P18), R4.2
unnamed: Q2.2 (B), R9.1
VCC: C5.2, C20.1, C21.1, D1.2 (K), D2.1 (A), P8.3, P22.VCC (P14); also elsewhere on the board
Vibreur: R9.2; also elsewhere on the board

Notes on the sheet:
Buzzer

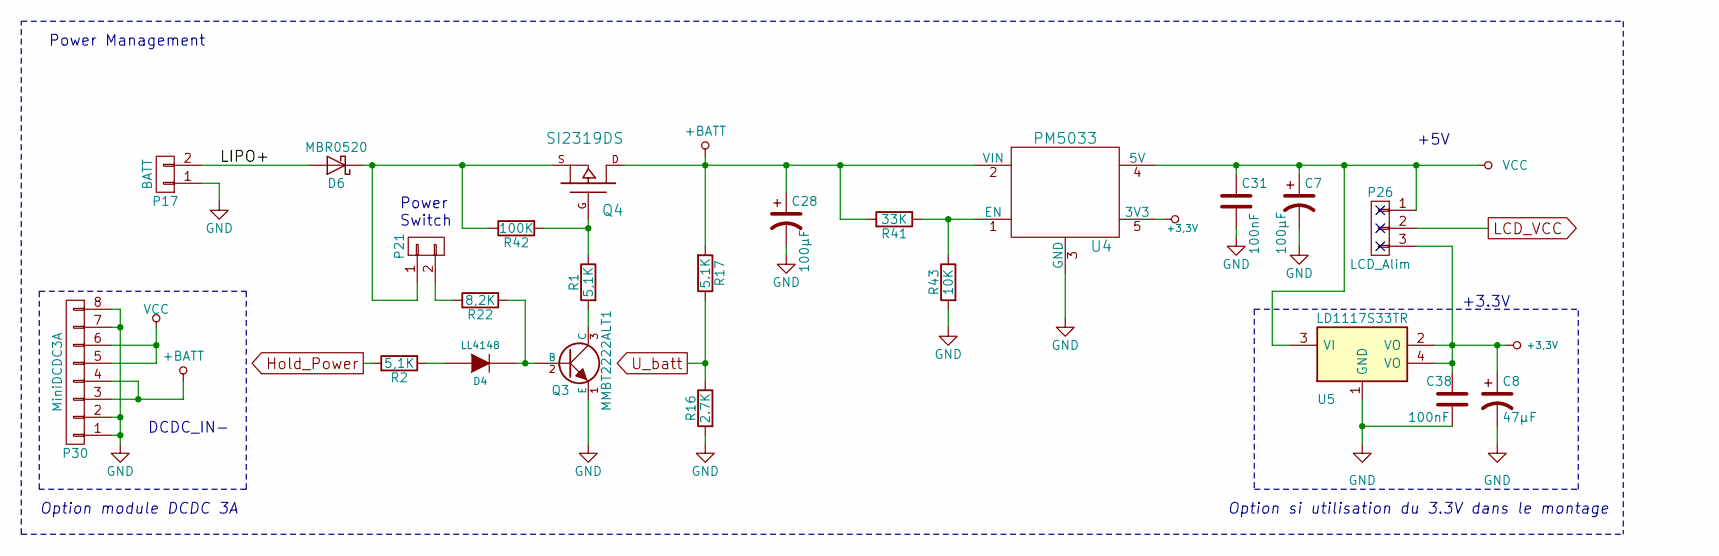
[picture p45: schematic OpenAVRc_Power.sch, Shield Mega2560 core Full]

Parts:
C7, C28: 100µF; CP_Elec_6.3x5.3
C8: 47µF; CP_Elec_6.3x5.3
C31, C38: 100nF; C_1206
D4: LL4148; D_SOD-123
D6: MBR0520; D_SOD-123
P17: BATT; Pin_Header_Straight_1x02_Pitch2.54mm
P21: Sw_power; Pin_Header_Straight_1x02_Pitch2.54mm
P26: LCD_Alim; Pin_Header_Straight_1x03_Pitch2.54mm
P30: MiniDCDC3A
Q3: MMBT2222ALT1; SOT-23_MMBT2222
Q4: SI2319DS; SOT-23_MOS_P
R1, R2: 5,1K; R_1206
R16: 2.7K; R_1206
R17: 5.1K; R_1206
R22: 8,2K; R_1206
R41: 33K; R_1206
R42: 100K; R_1206
R43: 10K; R_1206
U4: PM5033; Pm5033_sil5
U5: LD1117S33TR; SOT-223

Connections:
+3.3V: C8.1, C38.1, P26.3, U4.5 (3V3), U5.2 (VO), U5.4 (VO); also elsewhere on the board
+BATT: C28.1, P30.3, P30.4, Q4.D, R17.2, R41.1, U4.2 (VIN); also elsewhere on the board
/OpenAVRc_Power/LIPO+: D6.2 (A), P17.2
GND: C7.2, C8.2, C28.2, C31.2, C38.2, P17.1, P30.1, P30.2, P30.7, P30.8, Q3.1 (E), R16.2, R43.2, U4.3 (GND), U5.1 (GND); also elsewhere on the board
Hold_Power: R2.1; also elsewhere on the board
LCD_VCC: P26.2; also elsewhere on the board
unnamed: D4.1 (A), R2.2
unnamed: D4.2 (K), Q3.2 (B), R22.2
unnamed: D6.1 (K), P21.1, Q4.S, R42.1
unnamed: P21.2, R22.1
unnamed: Q3.3 (C), R1.2
unnamed: Q4.G, R1.1, R42.2
unnamed: R41.2, R43.1, U4.1 (EN)
U_batt: R16.1, R17.1; also elsewhere on the board
VCC: C7.1, C31.1, P26.1, P30.5, P30.6, U4.4 (5V), U5.3 (VI); also elsewhere on the board

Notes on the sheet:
+3.3V
+5V
Power Management
Option si utilisation du 3.3V dans le montage
Power Switch
DCDC_IN-
Option module DCDC 3A

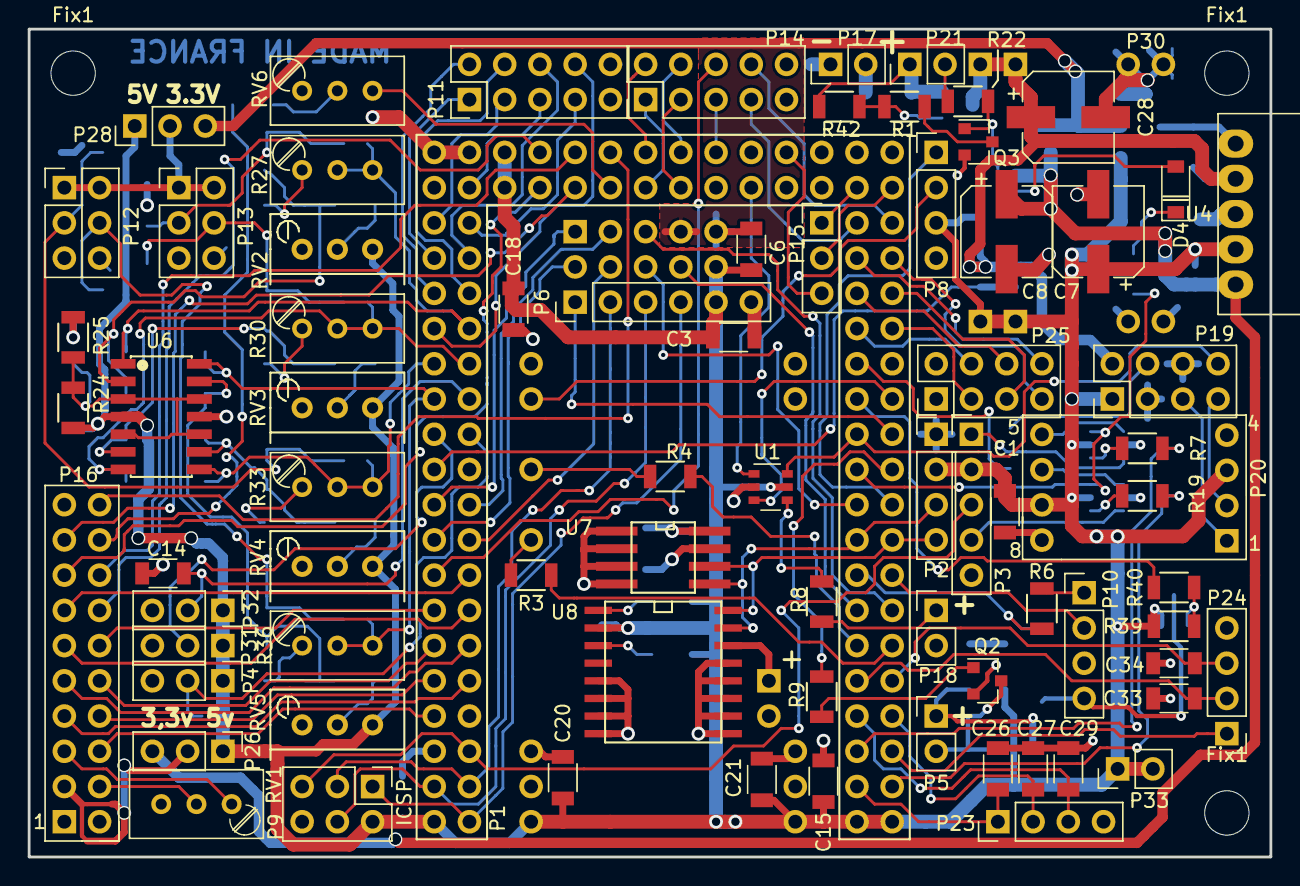
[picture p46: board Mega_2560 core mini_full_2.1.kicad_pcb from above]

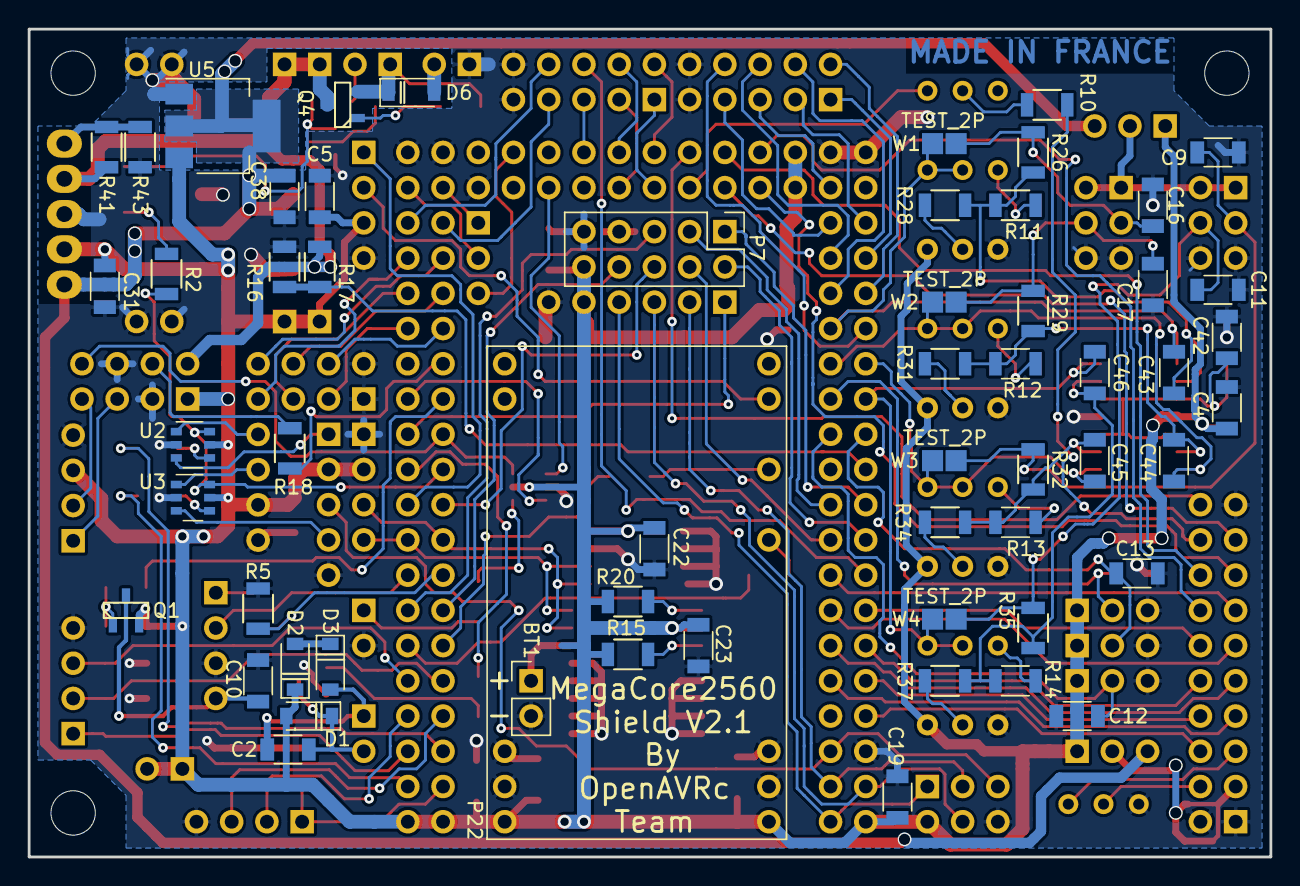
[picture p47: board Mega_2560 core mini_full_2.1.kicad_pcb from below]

Board: 2 copper layers, 89.5 x 59.7 mm, 138 parts (58 on the bottom side), 140 nets.

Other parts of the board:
Fix1, Fix1#2, Fix1#3: MountingHole_3.2mm_M3

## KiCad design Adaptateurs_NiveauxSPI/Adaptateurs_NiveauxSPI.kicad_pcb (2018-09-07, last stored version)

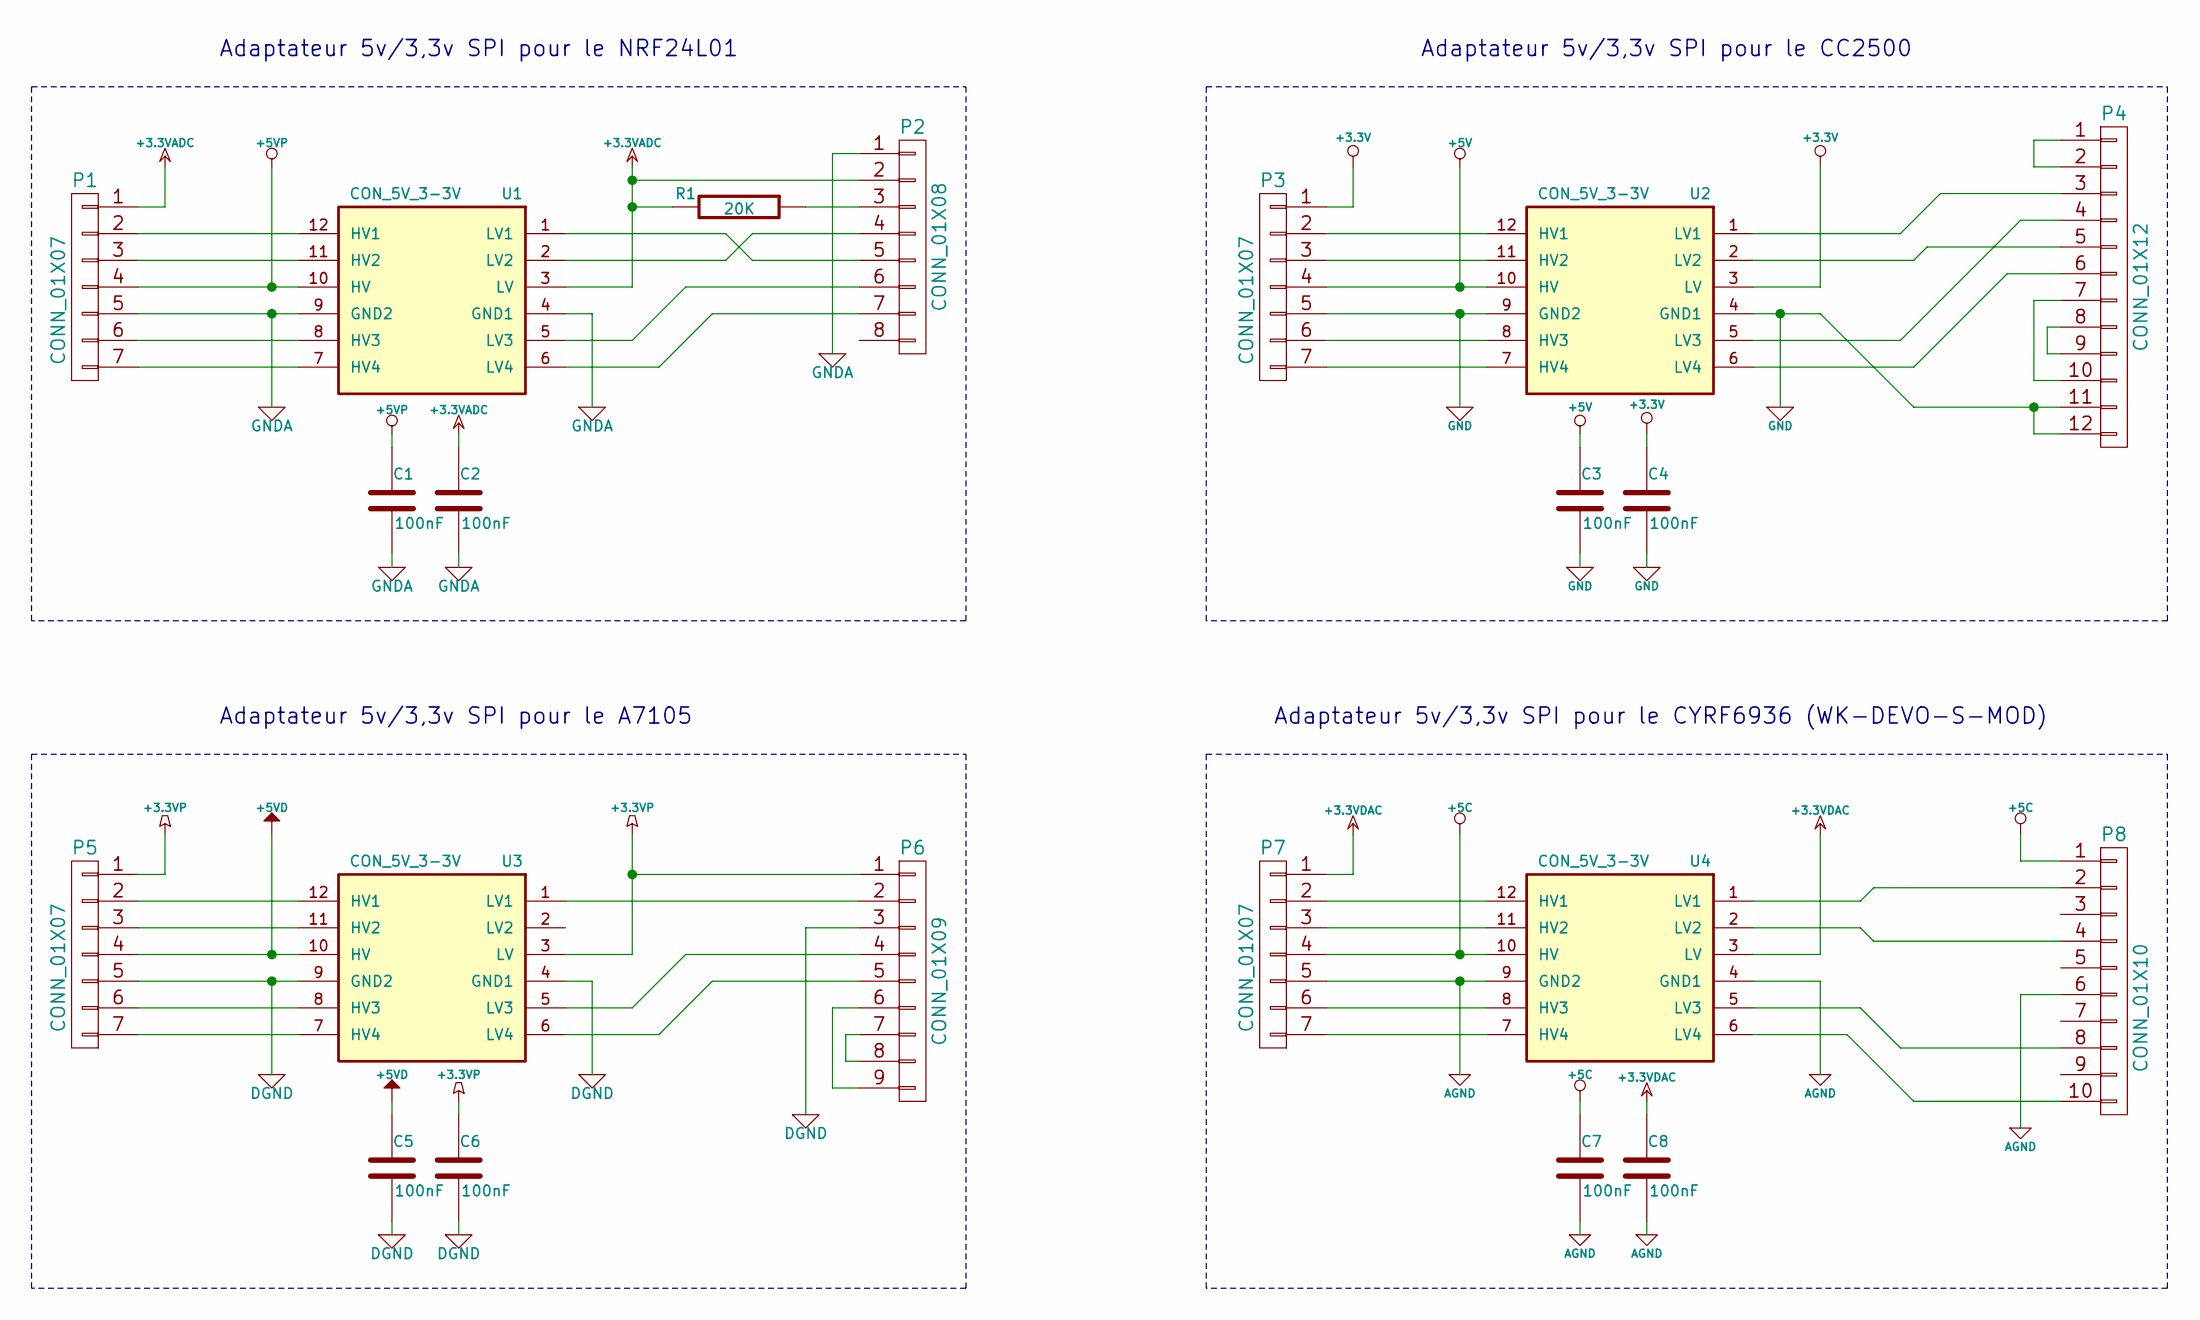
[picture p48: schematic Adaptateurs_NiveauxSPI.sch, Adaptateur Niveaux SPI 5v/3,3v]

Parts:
C1, C2, C3, C4, C5, C6, C7, C8: 100nF; C_1206
P1, P3, P5, P7: CONN_01X07; Pin_Header_Straight_1x07_Pitch2.54mm
P2: CONN_01X08; Pin_Header_Straight_2x04_Pitch2.54mm
P4: CONN_01X12; Pin_Header_Straight_2x06_Pitch2.54mm
P6: CONN_01X09; Pin_Header_Straight_1x09_Pitch2.54mm
P8: CONN_01X10; Pin_Header_Straight_2x05_Pitch2.54mm
R1: 20K; R_1206
U1, U2, U3, U4: CON_5V_3-3V; Level_Convertissor_W10.16mm

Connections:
+3.3V: C4.1, P3.1, U2.3 (LV)
+3.3VADC: C2.1, P1.1, P2.2, R1.2, U1.3 (LV)
+3.3VDAC: C8.1, P7.1, U4.3 (LV)
+3.3VP: C6.1, P5.1, P6.1, U3.3 (LV)
+5C: C7.1, P7.4, P8.1, U4.10 (HV)
+5V: C3.1, P3.4, U2.10 (HV)
+5VD: C5.1, P5.4, U3.10 (HV)
+5VP: C1.1, P1.4, U1.10 (HV)
AGND: C7.2, C8.2, P7.5, P8.6, U4.4 (GND1), U4.9 (GND2)
DGND: C5.2, C6.2, P5.5, P6.3, U3.4 (GND1), U3.9 (GND2)
GND: C3.2, C4.2, P3.5, P4.11, P4.12, U2.4 (GND1), U2.9 (GND2)
GNDA: C1.2, C2.2, P1.5, P2.1, U1.4 (GND1), U1.9 (GND2)
unnamed: P1.2, U1.12 (HV1)
unnamed: P1.3, U1.11 (HV2)
unnamed: P1.6, U1.8 (HV3)
unnamed: P1.7, U1.7 (HV4)
unnamed: P2.3, R1.1
unnamed: P2.4, U1.2 (LV2)
unnamed: P2.5, U1.1 (LV1)
unnamed: P2.6, U1.5 (LV3)
unnamed: P2.7, U1.6 (LV4)
unnamed: P3.2, U2.12 (HV1)
unnamed: P3.3, U2.11 (HV2)
unnamed: P3.6, U2.8 (HV3)
unnamed: P3.7, U2.7 (HV4)
unnamed: P4.1, P4.2
unnamed: P4.3, U2.1 (LV1)
unnamed: P4.4, U2.5 (LV3)
unnamed: P4.5, U2.2 (LV2)
unnamed: P4.6, U2.6 (LV4)
unnamed: P4.8, P4.9
unnamed: P4.7, P4.10
unnamed: P5.2, U3.12 (HV1)
unnamed: P5.3, U3.11 (HV2)
unnamed: P5.6, U3.8 (HV3)
unnamed: P5.7, U3.7 (HV4)
unnamed: P6.2, U3.1 (LV1)
unnamed: P6.4, U3.5 (LV3)
unnamed: P6.5, U3.6 (LV4)
unnamed: P6.6, P6.9
unnamed: P6.7, P6.8
unnamed: P7.2, U4.12 (HV1)
unnamed: P7.3, U4.11 (HV2)
unnamed: P7.6, U4.8 (HV3)
unnamed: P7.7, U4.7 (HV4)
unnamed: P8.2, U4.1 (LV1)
unnamed: P8.4, U4.2 (LV2)
unnamed: P8.8, U4.5 (LV3)
unnamed: P8.10, U4.6 (LV4)

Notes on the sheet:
Adaptateur 5v/3,3v SPI pour le NRF24L01
Adaptateur 5v/3,3v SPI pour le CC2500
Adaptateur 5v/3,3v SPI pour le A7105
Adaptateur 5v/3,3v SPI pour le CYRF6936 (WK-DEVO-S-MOD)

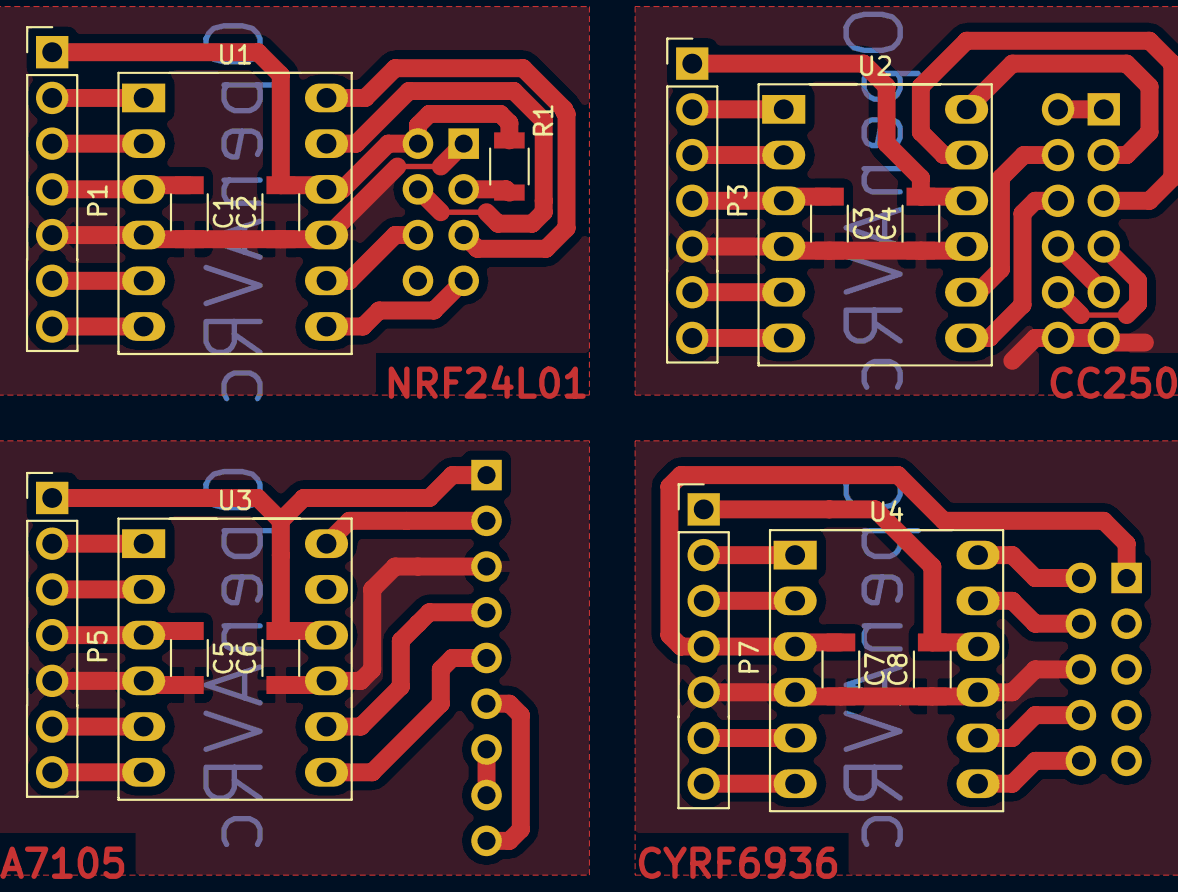
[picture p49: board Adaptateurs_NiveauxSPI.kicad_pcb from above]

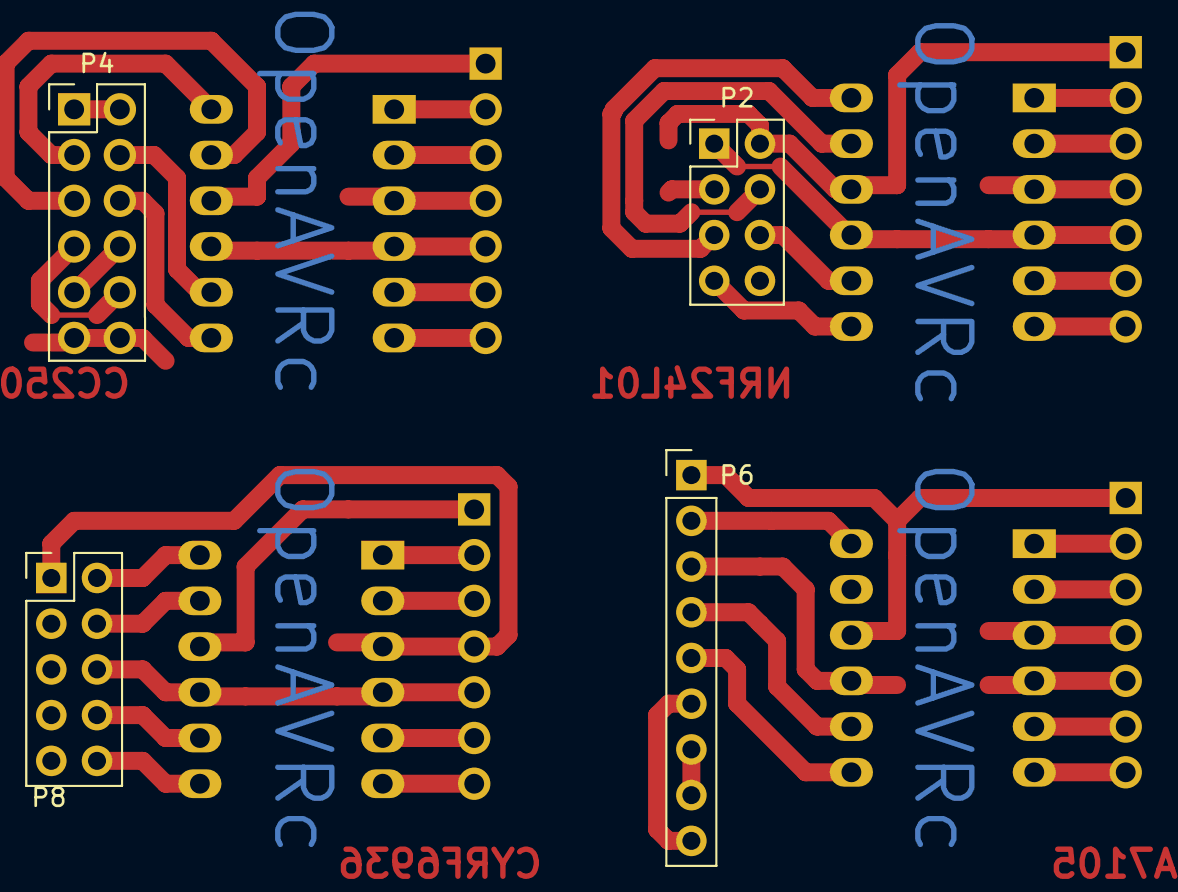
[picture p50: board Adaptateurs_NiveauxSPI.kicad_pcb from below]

Board: 2 copper layers, 21 parts (4 on the bottom side), 49 nets.

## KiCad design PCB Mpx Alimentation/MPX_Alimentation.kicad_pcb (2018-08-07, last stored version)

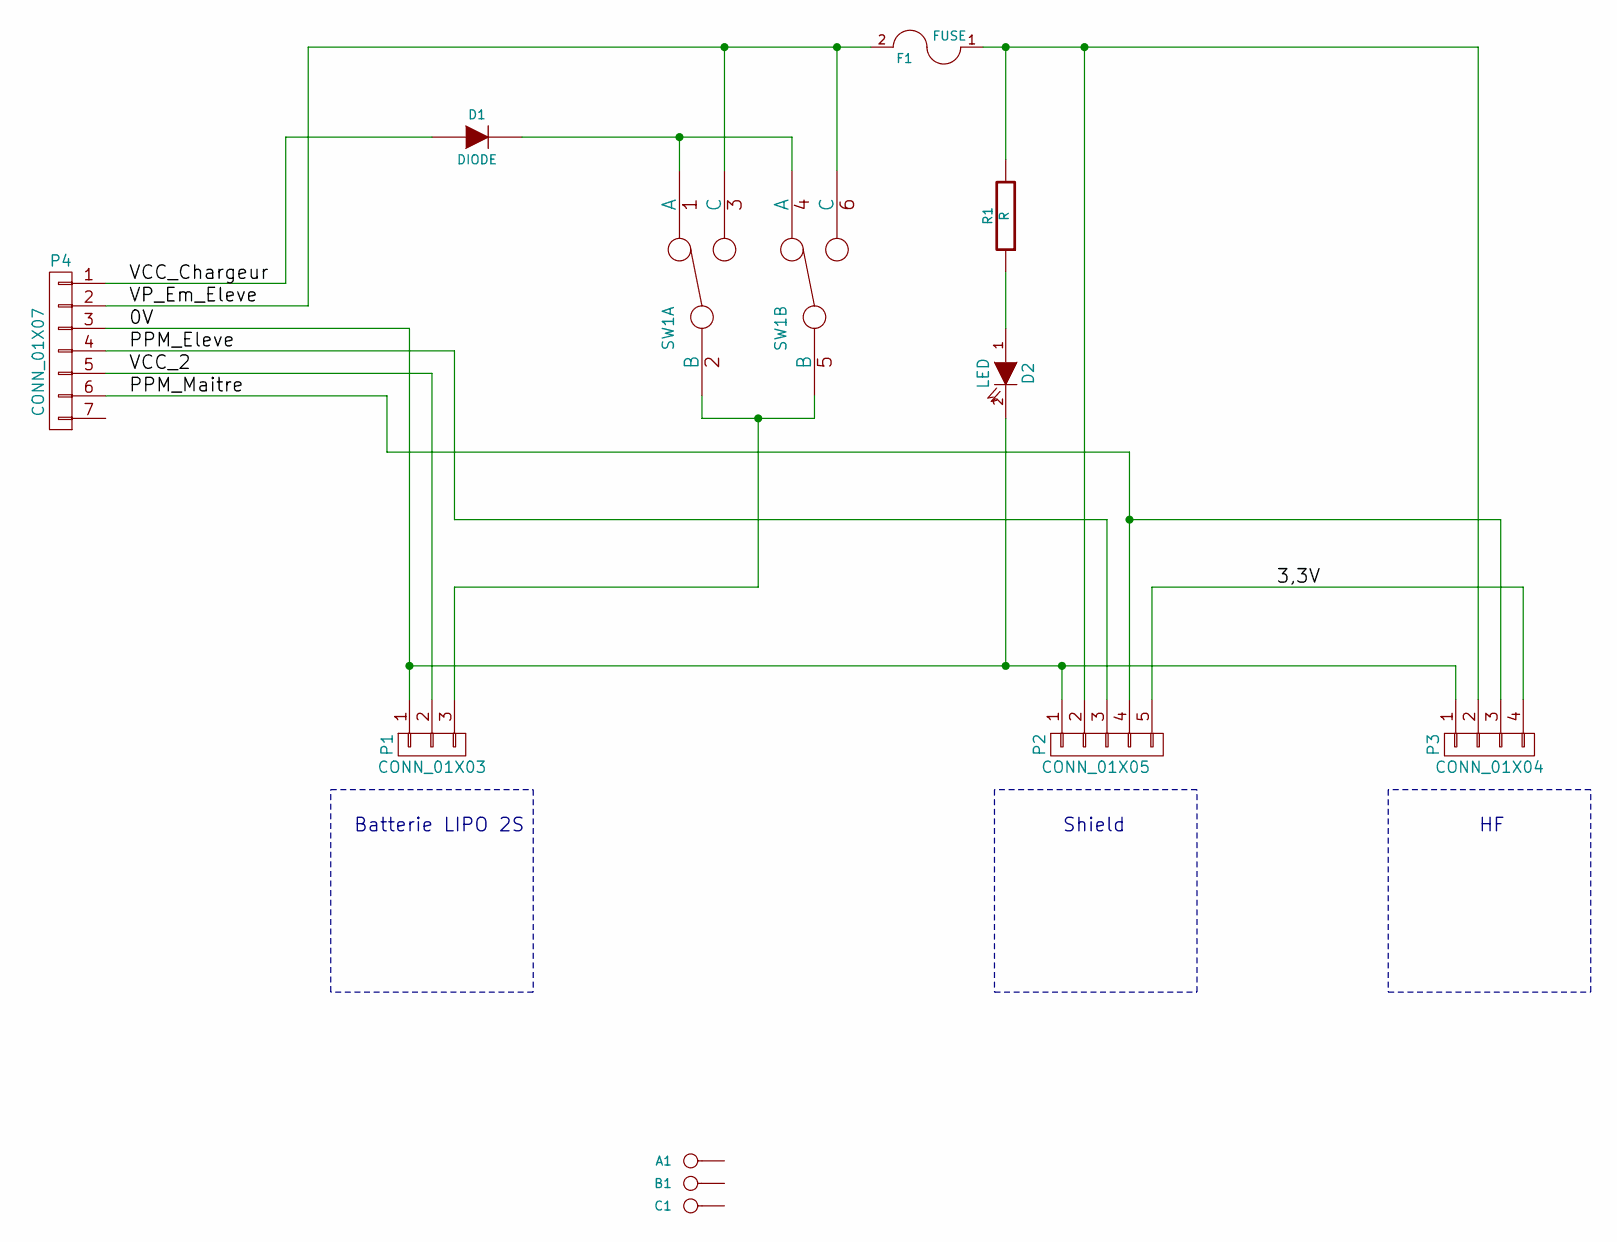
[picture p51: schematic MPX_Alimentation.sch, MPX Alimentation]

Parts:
A1: CONN_1; MountingHole_2.2mm_M2
B1: CONN_1; MountingHole_2.2mm_M2
C1: CONN_1; MountingHole_2.2mm_M2
D1: DIODE; D_DO-201_P15.24mm_Horizontal
D2: LED; LED_D3.0mm
F1: FUSE; Fuseholder5x20_horiz_open_universal_Type-III
P1: CONN_01X03; Pin_Header_Angled_1x03_Pitch2.54mm
P2: CONN_01X05; Pin_Header_Angled_1x05_Pitch2.54mm
P3: CONN_01X04; Pin_Header_Angled_1x04_Pitch2.54mm
P4: CONN_01X07; Embase_Din8_Mpx
R1: R; R_Axial_DIN0207_L6.3mm_D2.5mm_P10.16mm_Horizontal
SW1: DUAL_SWITCH_INV; SW_CuK_JS202011CQN_DPDT_Straight

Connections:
/0V: D2.2 (K), P1.1, P2.1, P3.1, P4.3
/3,3V: P2.5, P3.4
/PPM_Eleve: P2.3, P4.4
/PPM_Maitre: P2.4, P3.3, P4.6
/VCC_2: P1.2, P4.5
/VCC_Chargeur: D1.1 (A), P4.1
/VP_Em_Eleve: F1.2, P4.2, SW1.3 (C), SW1.6 (C)
unnamed: D1.2 (K), SW1.1 (A), SW1.4 (A)
unnamed: D2.1 (A), R1.1
unnamed: F1.1, P2.2, P3.2, R1.2
unnamed: P1.3, SW1.2 (B), SW1.5 (B)

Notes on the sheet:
Batterie LIPO 2S
Shield



Board: 2 copper layers, 90.0 x 45.0 mm, 12 parts (2 on the bottom side), 11 nets.

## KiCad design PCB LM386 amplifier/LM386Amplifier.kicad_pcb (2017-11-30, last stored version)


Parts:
C1, C2, C3: 10µF; CP_Radial_D6.3mm_P2.50mm
C4, C6: 100nF; C_Rect_L7.0mm_W2.0mm_P5.00mm
C5, C7: 10µF; CP_Radial_Tantal_D6.0mm_P2.50mm
J1: JACK_2P; Pin_Header_Straight_1x03_Pitch2.54mm
P1, P2: CONN_01X02; Pin_Header_Straight_1x02_Pitch2.54mm
R1, R2: 1,5K; R_Axial_DIN0204_L3.6mm_D1.6mm_P2.54mm_Vertical
R3, R5: 1,2K; R_Axial_DIN0204_L3.6mm_D1.6mm_P2.54mm_Vertical
R4: 10; R_Axial_DIN0204_L3.6mm_D1.6mm_P2.54mm_Vertical
R6, R7: 22K; R_Axial_DIN0204_L3.6mm_D1.6mm_P2.54mm_Vertical
RV1, RV2: 10K; Potentiometer_Trimmer_Bourns_3296W.kicad_mod
SP1: SPEAKER; Pin_Header_Straight_1x02_Pitch2.54mm
U1: LM386; DIP-8_W7.62mm_LongPads

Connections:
+5V: C3.1, C4.1, P1.2, U1.6 (Pwr)
GND: C3.2, C4.2, P1.1, R4.1, R5.1, RV1.3, RV2.3, SP1.2, U1.2 (-), U1.4 (Gnd)
unnamed: C1.1, RV1.2
unnamed: C1.2, R1.1
unnamed: C2.1, RV2.2
unnamed: C2.2, R2.1
unnamed: C5.1, U1.1 (Gain)
unnamed: C5.2, R3.1
unnamed: C6.1, C7.1, U1.5
unnamed: C6.2, R4.2
unnamed: C7.2, J1.1
unnamed: J1.2, SP1.1
unnamed: J1.3, R5.2
unnamed: P2.1, R7.2
unnamed: P2.2, R6.2
unnamed: R1.2, R2.2, U1.3 (+)
unnamed: R3.2, U1.8 (Gain)
unnamed: R6.1, RV1.1
unnamed: R7.1, RV2.1

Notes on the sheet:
Out Buzzer
Out JQ6500


Board: 2 copper layers, 37.5 x 25.4 mm, 21 parts (0 on the bottom side), 19 nets.

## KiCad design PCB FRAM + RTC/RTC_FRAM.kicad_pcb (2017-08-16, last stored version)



Board: 2 copper layers, 28.0 x 19.0 mm, 7 parts (5 on the bottom side), 6 nets.

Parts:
BT1: CR1225; Renata_SMTU1225-LF
C1: 100n; SM0805
J1: CONN_01X05; pin_strip_5
R1, R2: 4K7; SM0805
U2: FM24W256G; SO-8
U3: DS3231; SO-16-W

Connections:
+3V3: C1.1, J1.3, R1.1, R2.1, U2.8, U3.2
GND: BT1.2, C1.2, J1.1, U2.1, U2.2, U2.3, U2.4, U2.7, U3.5, U3.6, U3.7, U3.8, U3.9, U3.10, U3.11, U3.12, U3.13
unnamed: BT1.1, U3.14
RESET_N: J1.2, U3.4
SCL-FRAM-RTC: J1.5, R1.2, U2.6, U3.16
SDA-FRAM-RTC: J1.4, R2.2, U2.5, U3.15

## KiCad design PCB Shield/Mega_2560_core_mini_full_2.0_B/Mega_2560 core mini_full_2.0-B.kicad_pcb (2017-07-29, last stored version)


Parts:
C1, C2, C3, C5: 47nF; C_1206
C4, C6, C7, C9, C11, C16, C17, C26, C27, C29, C31, C32, C33, C34, C38: 100nF; C_1206
C8, C10, C28: 47µF; CP_Elec_6.3x5.3
C42: 6.8nF; C_1206
C43, C44, C45, C46: 4.7nF; C_1206
D1, D2, D6: MBR0520; D_SOD-123
P1: 2560-core; Connectors-2560-core
P2: Clock; Pin_Header_Straight_1x04_Pitch2.54mm
P3: Option; Pin_Header_Straight_1x04_Pitch2.54mm
P4: Potentiometre; Pin_Header_Straight_2x05_Pitch2.54mm
P5: Vibreur; Pin_Header_Straight_1x02_Pitch2.54mm
P6: Micro_sd; Pin_Header_Straight_1x06_Pitch2.54mm
P7: Option; Pin_Header_Straight_1x06_Pitch2.54mm
P8: Audio; Pin_Header_Straight_1x05_Pitch2.54mm
P9: SPI; Pin_Header_Straight_2x03_Pitch2.54mm
P10: SPI_libre; Pin_Header_Straight_1x03_Pitch2.54mm
P11: Trim; Pin_Header_Straight_2x05_Pitch2.54mm
P12: Stick_left; Pin_Header_Straight_1x04_Pitch2.54mm
P13: Stick_right; Pin_Header_Straight_1x04_Pitch2.54mm
P14: Switch; Pin_Header_Straight_2x05_Pitch2.54mm
P15: LCD_I2C; Pin_Header_Straight_1x04_Pitch2.54mm
P16: LCD; Pin_Header_Straight_2x10_Pitch2.54mm
P17: Battery LIPO; Pin_Header_Straight_1x02_Pitch2.54mm
P18: Ecolage; Pin_Header_Straight_1x02_Pitch2.54mm
P19: Module_TX; Pin_Header_Straight_2x04_Pitch2.54mm
P20: Module_RS232/TTL; Con_RS232_TTL
P21: Sw_power; Pin_Header_Straight_1x02_Pitch2.54mm
P22: CONN_JQ6500_28P_mini; connector_mini-JQ6500-28P
P23: Rot_1; Pin_Header_Straight_1x04_Pitch2.54mm
P24: Rot_2; Pin_Header_Straight_1x04_Pitch2.54mm
P25: Key_select_menu_ESC; Pin_Header_Straight_2x04_Pitch2.54mm
P26: LCD_Vcc_select; Pin_Header_Straight_1x03_Pitch2.54mm
R1, R2: 22K; R_1206
R3: 18K; R_1206
R4: 1K; R_1206
R5, R6: 10K; R_1206
R7: 470; R_1206
R8: 200; R_1206
R9: 220; R_1206
R11, R12, R13, R14: 100K; R_1206
R16: 2.7K; R_1206
R17: 5.1K; R_1206
R18, R19, R22, R23: 5.1k; R_1206
R24, R25: 33K; R_1206
R26, R29, R32, R35: 47K; R_1206
R27, R30, R33, R36: POT_100k; Potentiometer_Trimmer_Bourns_3296W
R28, R31, R34, R37: 270K; R_1206
RV1: 200K; Potentiometer_Trimmer_Bourns_3214W
RV2, RV3, RV4, RV5: POT_100k; Potentiometer_Trimmer_Bourns_3296W
RV6: 120; Potentiometer_Trimmer_Bourns_3214W
U1: 4066; SOP14
U2, U3: TLP290; SOP4
U4: L4941; TO-220
U5: LD1117S33TR; SOT-223
U6: MCP604-I/SL; SOP14
W1, W2, W3, W4: TEST_2P; TESTPT

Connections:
+BATT: D6.2 (A), P19.1, P21.1, R7.1, R17.2
/Isp_rst: P1.RESE (P75), P9.5
/Key_DOWN: P1.49 (P29), P25.4
/Key_ESC: P1.44 (P34), P25.7
/Key_LEFT: P1.46 (P32), P25.5
/Key_MENU: P1.45 (P33), P25.8
/Key_RIGHT: P1.47 (P31), P25.6
/Key_UP: P1.48 (P30), P25.3
/LCD_VCC: P15.2, P16.3, P26.2
/Lcd_A0: P1.D32 (P85), P16.16
/Lcd_bla: P1.D35 (P88), RV6.1
/Lcd_cs: P1.D34 (P87), P16.20
/Lcd_db0: P1.D22 (P74), P16.6
/Lcd_db1: P1.D23 (P71), P16.7
/Lcd_db2: P1.D24 (P72), P16.8
/Lcd_db3: P1.D25 (P69), P16.9
/Lcd_db4: P1.D26 (P70), P16.10
/Lcd_db5: P1.D27 (P67), P16.11
/Lcd_db6: P1.D28 (P68), P16.12
/Lcd_db7: P1.D29 (P65), P16.13
/Lcd_e: P1.D30 (P83), P16.14
/Lcd_r/w: P1.D31 (P84), P16.15
/Lcd_rst: P1.D33 (P86), P16.17
/Lcd_vo: P16.4, RV1.2
/Microsd_CS: P1.53 (P24), P6.1, P7.1
/Miso: P1.MISO (P79), P6.4, P7.4, P9.1
/Mosi: P1.MOSI (P78), P6.3, P7.3, P9.4
/PH2: P1.PH2 (P19), P10.1
/PPM_TX_OUT: D2.1 (K), P19.4
/PPM_in: P1.PE7 (P10), U1.11 (I/O)
/PPM_out: D2.2 (A), P1.PW12 (P27), U1.8 (I/O)
/Pot_1: P1.A12 (P55), P4.6
/Pot_2: P1.A13 (P58), P4.2
/Pot_3: P1.A14 (P57), P4.4
/RXD2: P1.D17 (P14), P10.3
/RX_module: P19.6, P20.8
/Rot_1A: C29.1, P1.PWD2 (P7), P23.3
/Rot_1B: C27.1, P1.PWD3 (P8), P23.2, R18.2
/Rot_1push: C26.1, P1.D15 (P12), P23.1, R19.2
/Rot_2A: C34.1, P1.D19 (P16), P24.3
/Rot_2B: C33.1, P1.D18 (P15), P24.2, R22.2
/Rot_2push: C32.1, P1.D14 (P11), P24.1, R23.2
/Sck: P1.SCK (P77), P6.2, P7.2, P9.3
/Scl: P1.D21 (P18), P2.1, P3.1, P15.4
/Sda: P1.D20 (P17), P2.2, P3.2, P15.3
/Sim_control: P1.PW11 (P26), U1.5 (ON), U1.13 (ON)
/Stick_LH: C45.1, P1.A11 (P56), R33.2, R33.3, U6.8, W3.1
/Stick_LHcon: C9.2, P12.2, R32.2, W3.2
/Stick_LV: C46.1, P1.A9 (P54), R36.2, R36.3, U6.14, W4.1
/Stick_LVcon: C11.2, P12.3, R35.2, W4.2
/Stick_RH: C43.1, P1.A8 (P51), R27.2, R27.3, U6.1, W1.1
/Stick_RHcon: C16.2, P13.2, R26.2, W1.2
/Stick_RV: C44.1, P1.A10 (P53), R30.2, R30.3, U6.7, W2.1
/Stick_RVcon: C17.2, P13.3, R29.2, W2.2
/Sw_ailDR: P1.D38 (P93), P14.5
/Sw_eleDR: P1.43 (P35), P14.7
/Sw_gear: P1.D40 (P91), P14.4
/Sw_id1: P1.D37 (P90), P14.1
/Sw_id2: P1.D36 (P89), P14.2
/Sw_rudDR: P1.D41 (P92), P14.3
/Sw_thcut: P1.D39 (P66), P14.6
/Sw_turn: P1.42 (P36), P14.8
/TXD2: P1.D16 (P13), P10.2
/TX_module: P19.5, P20.7
/Tele_RX: P1.RXD (P4), U3.3
/Tele_TX: P1.TXD (P5), U2.4
/Trim_LH->: P1.A6 (P49), P11.1
/Trim_LH<-: P1.A7 (P52), P11.2
/Trim_LV->: P1.A4 (P47), P11.7
/Trim_LV<-: P1.A5 (P50), P11.4
/Trim_RH->: P1.A0 (P43), P11.5
/Trim_RH<-: P1.A1 (P46), P11.6
/Trim_RV->: P1.A2 (P45), P11.8
/Trim_RV<-: P1.A3 (P48), P11.3
/U_batt: P1.A15 (P60), R16.2, R17.1
/Vibreur: P1.PJ7 (P73), R9.2
/audio_left_in: P1.PWD6 (P20), R1.2
/audio_right_in: P22.DACL (P16), R2.2
/core_pw10: P1.PW10 (P25), R3.1
/core_pw13: P1.PW13 (P28), R4.1
GND: C1.1, C2.1, C3.1, C4.2, C5.1, C6.1, C8.2, C10.2, C26.2, C27.2, C28.2, C29.2, C31.2, C32.2, C33.2, C34.2, C38.2, C42.2, D1.2 (A), P1.GND (P100), P2.4, P3.4, P4.7, P4.8, P4.9, P5.2, P6.6, P7.6, P8.5, P9.6, P11.9, P11.10, P12.4, P13.4, P14.9, P14.10, P15.1, P16.1, P16.2, P16.19, P17.1, P18.2, P19.8, P20.1, P20.5, P22.GND (P12), P23.4, P24.4, P25.1, P25.2, R6.1, R16.1, R25.2, RV1.1, RV2.1, RV3.1, RV4.1, RV5.1, U1.1 (I/O), U1.7 (V-), U2.2, U3.2, U4.2 (GND), U5.1 (GND), U6.11 (V-)
unnamed: C28.1, D6.1 (K), U4.1 (IN)
unnamed: C8.1, C38.1, P26.1, U5.2 (VO)
unnamed: C42.1, R24.2, R25.1, U6.3 (+), U6.5 (+), U6.10 (+), U6.12 (+)
unnamed: C43.2, R11.2, R26.1, R28.1, U6.2 (-)
unnamed: C44.2, R12.2, R29.1, R31.1, U6.6 (-)
unnamed: C45.2, R13.2, R32.1, R34.1, U6.9 (-)
unnamed: C46.2, R14.2, R35.1, R37.1, U6.13 (-)
unnamed: D1.1 (K), P5.1, R9.1
unnamed: P8.1, R1.1
unnamed: P8.2, R2.1
unnamed: P16.5, RV1.3
unnamed: P16.18, RV6.2
unnamed: P17.2, P21.2
unnamed: P18.1, R8.1
unnamed: P19.2, P19.3
unnamed: P20.3, U2.3
unnamed: P20.4, U3.4
unnamed: P22.BUSY (P20), R3.2
unnamed: P22.RX (P18), R4.2
unnamed: R5.2, U1.2 (O/I), U1.6 (ON)
unnamed: R6.2, U1.3 (O/I), U1.12 (ON)
unnamed: R7.2, U2.1, U3.1
unnamed: R8.2, U1.9 (O/I), U1.10 (O/I)
unnamed: R11.1, R27.1
unnamed: R12.1, R30.1
unnamed: R13.1, R33.1
unnamed: R14.1, R36.1
unnamed: R28.2, RV2.2
unnamed: R31.2, RV3.2
unnamed: R34.2, RV4.2
unnamed: R37.2, RV5.2
VCC: C1.2, C2.2, C3.2, C4.1, C5.2, C6.2, C9.1, C10.1, C11.1, C16.1, C17.1, C31.1, P1.VCC (P1), P2.3, P3.3, P4.1, P4.3, P4.5, P6.5, P7.5, P8.4, P9.2, P12.1, P13.1, P19.7, P20.2, P20.6, P22.VCC (P14), P26.3, R5.1, R18.1, R19.1, R22.1, R23.1, R24.1, RV2.3, RV3.3, RV4.3, RV5.3, U1.4 (I/O), U1.14 (V+), U4.3 (OUT), U5.3 (VI), U6.4 (V+)

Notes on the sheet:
+3.3V
+5V
Isolation Module TTL
Power Management
PPM Management
Stick control
Option si utilisation du 3.3V dans le montage
Option Amplification des sticks (Fonctionne sans)
Option si utilisation de la télémètrie
Alim module
Switch

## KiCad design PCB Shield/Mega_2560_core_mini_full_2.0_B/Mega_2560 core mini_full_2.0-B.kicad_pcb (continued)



Board: 2 copper layers, 105 parts (31 on the bottom side), 113 nets.

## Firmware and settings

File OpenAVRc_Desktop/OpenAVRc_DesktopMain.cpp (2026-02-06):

/*
**************************************************************************
*                                                                        *
*                 ____                ___ _   _____                      *
*                / __ \___  ___ ___  / _ | | / / _ \____                 *
*               / /_/ / _ \/ -_) _ \/ __ | |/ / , _/ __/                 *
*               \____/ .__/\__/_//_/_/ |_|___/_/|_|\__/                  *
*                   /_/                                                  *
*                                                                        *
*              This file is part of the OpenAVRc project.                *
*                                                                        *
*                         Based on code(s) named :                       *
*             OpenTx - https://github.com/opentx/opentx                  *
*             Deviation - https://www.deviationtx.com/                   *
*                                                                        *
*                Only AVR code here for visibility ;-)                   *
*                                                                        *
*   OpenAVRc is free software: you can redistribute it and/or modify     *
*   it under the terms of the GNU General Public License as published by *
*   the Free Software Foundation, either version 2 of the License, or    *
*   (at your option) any later version.                                  *
*                                                                        *
*   OpenAVRc is distributed in the hope that it will be useful,          *
*   but WITHOUT ANY WARRANTY; without even the implied warranty of       *
*   MERCHANTABILITY or FITNESS FOR A PARTICULAR PURPOSE.  See the        *
*   GNU General Public License for more details.                         *
*                                                                        *
*       License GPLv2: http://www.gnu.org/licenses/gpl-2.0.html          *
*                                                                        *
**************************************************************************
*/


#include "OpenAVRc_DesktopMain.h"
#include "CommunicationsFrame.h"
#include "CompilerOptionsFrame.h"
#include "Voice_choice.h"
#include "VoiceEditFrame.h"
#include "BluetoothFrame.h"
#include <wx/msgdlg.h>
#include <wx/filedlg.h>
#include <wx/textdlg.h>
#include <wx/aboutdlg.h>
#include <wx/volume.h>
#include <wx/choicdlg.h>
#include <wx/busyinfo.h>

#include "Bluetooth.xpm"

//(*InternalHeaders(OpenAVRc_DesktopFrame)
#include <wx/artprov.h>
#include <wx/bitmap.h>
#include <wx/image.h>
#include <wx/intl.h>
#include <wx/string.h>
//*)


//helper functions
enum wxbuildinfoformat {
  short_f, long_f
};

wxString wxbuildinfo(wxbuildinfoformat format)
{
  wxString wxbuild(wxVERSION_STRING);

  if (format == long_f ) {
#if defined(__WXMSW__)
    wxbuild << _T("-Windows");
#elif defined(__UNIX__)
    wxbuild << _T("-Linux");
#endif

#if wxUSE_UNICODE
    wxbuild << _T("-Unicode build");
#else
    wxbuild << _T("-ANSI build");
#endif // wxUSE_UNICODE
  }

  return wxbuild;
}

//Splash
uint8_t LbmSplashOriginal[] = {
#include "../OpenAVRc/bitmaps/splash.lbm"
};
bool personalSplash = false;
uint8_t LbmSplash[SPLASHLENGHT] = {0};
#define LcdScale 2

//Global Var
bool Ini_Changed = false;
wxString AppPath;
//Voice
long Numvoice = 0;
wxString avrdudepath = _("non défini");
wxString dude_programmer = _("non défini");
wxString dude_type = _("non défini");
wxString dude_port = _("non défini");
//wxString COMM = _("non défini");
wxString voice_Langue = "ES"; //TTS langue
//Const
wxString dude_c = (" -c ");
wxString dude_p = (" -p ");
wxString dude_D = (" -D ");
wxString dude_P = (" -P ");
wxString dude_space = (" ");
wxString dude_U = (" -U ");
wxString dude_ComPrefix = ("\\\\.\\");
wxString dude_eeprom = ("eeprom:");
wxString dude_flash = ("flash:");
wxString dude_raw = (":r");
wxString dude_write = ("w:");
wxString dude_read = ("r:");
wxString dude_intel = (":i");
wxString keepopen = ("cmd /k ");


//Define defaults
wxString PCB = _("non défini");
wxString LCD = _("non défini");
bool LCDROT180 = 0;
wxString VOICE = ("NO");
wxString EXT = ("STD");
bool AUDIO = 0;
bool HELI = 0;
wxString TTS = _("non défini");
wxString TRANSLATIONS = _("non défini");
wxString NAVIGATION = ("NO");
bool HAPTIC = 0;
wxString PPM_UNIT = ("PERCENT_PREC1");
bool GPS = 0;
bool VARIO = 0;
bool PPM = 1;
wxString SERIAL_PROTOCOL = ("NO");
wxString PCM_PROTOCOL = ("NO");
bool CC2500 = 0;
bool CYRF6936 = 0;
bool NRF24l01 = 0;
bool A7105 = 0;
wxString CC2500PAG = ("0");
wxString CYRF6936PAG = ("0");
wxString NRF24l01PAG = ("0");
wxString A7105PAG = ("0");
bool SD_CARD = 0;
bool TEMPLATES = 0;
wxString THREE_POS = ("NO");
bool SPLASH =0;
wxString UNITS =("METRIC");
wxString DEFAULT_MODE =("NO");
wxString FONT = ("STD");
bool BOLD = 0;
bool BATTGRAPH = 0;
bool EEPROM_PROGRESS_BAR = 0;
wxString FAI = ("NO");
bool AUTOSWITCH = 0;
bool AUTOSOURCE = 0;
bool DBLKEYS = 0;
bool PPM_CENTER_ADJUSTABLE = 0;
bool PPM_LIMITS_SYMETRICAL = 0;
bool FLIGHT_MODES = 0;
bool CURVES = 0;
bool GVARS = 0;
bool CORRECT_NEGATIVE_VALUES = 0;
bool ARITHMETIC_OVERFLOW_CHECK = 0;
bool ACCURAT_THROTTLE_STATS = 0;
bool PWM_BACKLIGHT = 0;
bool OVERRIDE_CHANNEL_FUNCTION = 0;
bool WS_HOW_HIGH = 0;
bool TOGGLETRIM = 0;
bool NOANDSECONDE = 1;
bool SHUTDOWN_CONFIRMATION = 0;
bool FRAM = 0;
bool PERSONAMES = 0;
bool DBLGAZSTICK = 0;
wxString OTHERCOMPOPTIONS = "";
bool INV_STICK_RH = 0;
bool INV_STICK_LV = 0;
bool INV_STICK_RV = 0;
bool INV_STICK_LH = 0;
wxString BLUETOOTH = ("NO");
bool XMODEM = 0;
bool SCC = 0;

wxString switch1 = ("THR");
wxString switch2 = ("RUD");
wxString switch3 = ("ELE");
wxString switch4 = ("AIL");
wxString switch5 = ("GEA");
wxString switch6 = ("TRN");
wxString switchID0 = ("ID0");
wxString switchID1 = ("ID1");
wxString switchID2 = ("ID2");
wxString encoderA  = ("ENA");
wxString encoderB  = ("ENB");
wxString encoderNo = ("EN0");
wxString switchXD0 = ("XD0");
wxString switchXD1 = ("XD1");
wxString switchXD2 = ("XD2");
wxString stickRud = ("Rud");
wxString stickEle = ("Ele");
wxString stickThr = ("Thr");
wxString stickAil = ("Ail");

wxString NUMXANY = ("NO");

//(*IdInit(OpenAVRc_DesktopFrame)
const long OpenAVRc_DesktopFrame::ID_STATICBOXSPLASH = wxNewId();
const long OpenAVRc_DesktopFrame::ID_STATICBOXCONFIG = wxNewId();
const long OpenAVRc_DesktopFrame::ID_BUTTONSIMUSTD = wxNewId();
const long OpenAVRc_DesktopFrame::ID_BUTTONSIMUFRAM = wxNewId();
const long OpenAVRc_DesktopFrame::ID_LISTBOXCONFIG = wxNewId();
const long OpenAVRc_DesktopFrame::ID_SPLASH = wxNewId();
const long OpenAVRc_DesktopFrame::ID_BUTTONPERSO = wxNewId();
const long OpenAVRc_DesktopFrame::ID_BUTTONSPLASHDEFAULT = wxNewId();
const long OpenAVRc_DesktopFrame::ID_STATICBOX1 = wxNewId();
const long OpenAVRc_DesktopFrame::ID_CHOICE1 = wxNewId();
const long OpenAVRc_DesktopFrame::ID_STATICTEXT1 = wxNewId();
const long OpenAVRc_DesktopFrame::ID_BUTTON2 = wxNewId();
const long OpenAVRc_DesktopFrame::ID_BUTTON4 = wxNewId();
const long OpenAVRc_DesktopFrame::ID_PANEL1 = wxNewId();
const long OpenAVRc_DesktopFrame::ID_MENUITEMNEWCONFIG = wxNewId();
const long OpenAVRc_DesktopFrame::ID_MENUDELETEACTIVECONFIG = wxNewId();
const long OpenAVRc_DesktopFrame::idMenuQuit = wxNewId();
const long OpenAVRc_DesktopFrame::ID_MENUITEMCOMMUNICATION = wxNewId();
const long OpenAVRc_DesktopFrame::ID_MENUVOICECHOICE = wxNewId();
const long OpenAVRc_DesktopFrame::ID_MENUITEM3 = wxNewId();
const long OpenAVRc_DesktopFrame::ID_MENUITEM5 = wxNewId();
const long OpenAVRc_DesktopFrame::ID_MENUITEM4 = wxNewId();
const long OpenAVRc_DesktopFrame::ID_MENUITEM6 = wxNewId();
const long OpenAVRc_DesktopFrame::ID_MENUITEM9 = wxNewId();
const long OpenAVRc_DesktopFrame::ID_MENUITEM10 = wxNewId();
const long OpenAVRc_DesktopFrame::ID_MENUITEM13 = wxNewId();
const long OpenAVRc_DesktopFrame::ID_MENUITEM7 = wxNewId();
const long OpenAVRc_DesktopFrame::ID_MENUBLUETOOTH = wxNewId();
const long OpenAVRc_DesktopFrame::ID_MENUCOMPILOMATIC = wxNewId();
const long OpenAVRc_DesktopFrame::ID_MENUITEM11 = wxNewId();
const long OpenAVRc_DesktopFrame::ID_MENUITEM14 = wxNewId();
const long OpenAVRc_DesktopFrame::ID_MENUITEM16 = wxNewId();
const long OpenAVRc_DesktopFrame::ID_MENUITEM8 = wxNewId();
const long OpenAVRc_DesktopFrame::ID_MENUITEM12 = wxNewId();
const long OpenAVRc_DesktopFrame::ID_MENUITEM15 = wxNewId();
const long OpenAVRc_DesktopFrame::ID_MENUITEM2 = wxNewId();
const long OpenAVRc_DesktopFrame::idMenuAbout = wxNewId();
const long OpenAVRc_DesktopFrame::ID_STATUSBAR1 = wxNewId();
//*)

BEGIN_EVENT_TABLE(OpenAVRc_DesktopFrame,wxFrame)
  //(*EventTable(OpenAVRc_DesktopFrame)
  //*)
END_EVENT_TABLE()


OpenAVRc_DesktopFrame::OpenAVRc_DesktopFrame(wxWindow* parent,wxWindowID id)
{
  //(*Initialize(OpenAVRc_DesktopFrame)
  wxMenu* Menu1;
  wxMenu* Menu2;
  wxMenuItem* MenuItem1;
  wxMenuItem* MenuItem2;

  Create(parent, wxID_ANY, _("OpenAVRc Desktop V3"), wxDefaultPosition, wxDefaultSize, wxDEFAULT_DIALOG_STYLE, _T("wxID_ANY"));
  SetClientSize(wxSize(592,282));
  Panel1 = new wxPanel(this, ID_PANEL1, wxDefaultPosition, wxSize(848,280), 0, _T("ID_PANEL1"));
  Panel1->SetFocus();
  StaticBoxSplash = new wxStaticBox(Panel1, ID_STATICBOXSPLASH, _("Ecran d\'accueil"), wxPoint(160,8), wxSize(272,192), 0, _T("ID_STATICBOXSPLASH"));
  StaticBoxConfig = new wxStaticBox(Panel1, ID_STATICBOXCONFIG, _("Configuration"), wxPoint(16,8), wxSize(136,192), 0, _T("ID_STATICBOXCONFIG"));
  ButtonSimuSTD = new wxButton(Panel1, ID_BUTTONSIMUSTD, _("SIMULATEUR STANDARD"), wxPoint(24,204), wxSize(248,31), 0, wxDefaultValidator, _T("ID_BUTTONSIMUSTD"));
  ButtonSimuFram = new wxButton(Panel1, ID_BUTTONSIMUFRAM, _("SIMULATEUR F-RAM"), wxPoint(320,204), wxSize(248,31), 0, wxDefaultValidator, _T("ID_BUTTONSIMUFRAM"));
  ListBoxConfig = new wxListBox(Panel1, ID_LISTBOXCONFIG, wxPoint(24,32), wxSize(120,160), 0, 0, wxLB_SINGLE|wxVSCROLL, wxDefaultValidator, _T("ID_LISTBOXCONFIG"));
  PanelSplash = new wxPanel(Panel1, ID_SPLASH, wxPoint(169,64), wxSize(256,128), 0, _T("ID_SPLASH"));
  PanelSplash->SetBackgroundColour(wxColour(255,255,255));
  ButtonPerso = new wxButton(Panel1, ID_BUTTONPERSO, _("Personnaliser"), wxPoint(192,32), wxSize(80,24), 0, wxDefaultValidator, _T("ID_BUTTONPERSO"));
  ButtonPerso->SetToolTip(_("Attention : Tous ce qui n\'est pas blanc sera converti en noir"));
  ButtonSplashDefault = new wxButton(Panel1, ID_BUTTONSPLASHDEFAULT, _("Par défaut"), wxPoint(320,32), wxSize(80,24), 0, wxDefaultValidator, _T("ID_BUTTONSPLASHDEFAULT"));
  ButtonSplashDefault->SetToolTip(_("Restaurer l\'écran par défaut"));
  StaticBox1 = new wxStaticBox(Panel1, ID_STATICBOX1, _("Fichiers Voix"), wxPoint(440,8), wxSize(136,144), 0, _T("ID_STATICBOX1"));
  ChoiceLangue = new wxChoice(Panel1, ID_CHOICE1, wxPoint(520,32), wxSize(40,24), 0, 0, 0, wxDefaultValidator, _T("ID_CHOICE1"));
  ChoiceLangue->SetSelection( ChoiceLangue->Append(_("CZ")) );
  ChoiceLangue->Append(_("EN"));
  ChoiceLangue->Append(_("ES"));
  ChoiceLangue->Append(_("FR"));
  ChoiceLangue->SetToolTip(_("Choisissez la langue des mensages vocales"));
  StaticText1 = new wxStaticText(Panel1, ID_STATICTEXT1, _("Langue"), wxPoint(448,40), wxSize(64,16), wxALIGN_RIGHT, _T("ID_STATICTEXT1"));
  StaticText1->SetToolTip(_("Choisissez la langue des mensages vocales"));
  ButtonEditeur = new wxButton(Panel1, ID_BUTTON2, _("Éditeur"), wxPoint(480,72), wxSize(80,24), 0, wxDefaultValidator, _T("ID_BUTTON2"));
  ButtonEditeur->SetToolTip(_("Pour changer les messages"));
  ButtonCarteSD = new wxButton(Panel1, ID_BUTTON4, _("Carte SD"), wxPoint(480,112), wxSize(80,24), 0, wxDefaultValidator, _T("ID_BUTTON4"));
  ButtonCarteSD->SetHelpText(_("Écriture dans la carte SD"));
  MenuBar_main = new wxMenuBar();
  Menu1 = new wxMenu();
  MenuNewconfig = new wxMenuItem(Menu1, ID_MENUITEMNEWCONFIG, _("Nouvelle configuration"), wxEmptyString, wxITEM_NORMAL);
  MenuNewconfig->SetBitmap(wxArtProvider::GetBitmap(wxART_MAKE_ART_ID_FROM_STR(_T("wxART_NEW")),wxART_MENU));
  Menu1->Append(MenuNewconfig);
  MenuDeleteActiveConfig = new wxMenuItem(Menu1, ID_MENUDELETEACTIVECONFIG, _("Supprimer la configuration active"), wxEmptyString, wxITEM_NORMAL);
  MenuDeleteActiveConfig->SetBitmap(wxArtProvider::GetBitmap(wxART_MAKE_ART_ID_FROM_STR(_T("wxART_CROSS_MARK")),wxART_MENU));
  Menu1->Append(MenuDeleteActiveConfig);
  MenuItem1 = new wxMenuItem(Menu1, idMenuQuit, _("Quitter\tAlt-F4"), _("Quitter l\'application"), wxITEM_NORMAL);
  MenuItem1->SetBitmap(wxArtProvider::GetBitmap(wxART_MAKE_ART_ID_FROM_STR(_T("wxART_QUIT")),wxART_MENU));
  Menu1->Append(MenuItem1);
  MenuBar_main->Append(Menu1, _("Fichier"));
  Menu3 = new wxMenu();
  MenuItem3 = new wxMenuItem(Menu3, ID_MENUITEMCOMMUNICATION, _("Programmateur"), wxEmptyString, wxITEM_NORMAL);
  MenuItem3->SetBitmap(wxArtProvider::GetBitmap(wxART_MAKE_ART_ID_FROM_STR(_T("wxART_EXECUTABLE_FILE")),wxART_OTHER));
  Menu3->Append(MenuItem3);
  MenuChoiceVoice = new wxMenuItem(Menu3, ID_MENUVOICECHOICE, _("Synthèse vocale"), wxEmptyString, wxITEM_NORMAL);
  MenuChoiceVoice->SetBitmap(wxArtProvider::GetBitmap(wxART_MAKE_ART_ID_FROM_STR(_T("wxART_HELP")),wxART_OTHER));
  Menu3->Append(MenuChoiceVoice);
  MenuBar_main->Append(Menu3, _("Paramètres"));
  Menu4 = new wxMenu();
  Menu4->AppendSeparator();
  Menu5 = new wxMenuItem(Menu4, ID_MENUITEM3, _("Lire les réglages et les modèles de la radio (eeprom)"), wxEmptyString, wxITEM_NORMAL);
  Menu5->SetBitmap(wxArtProvider::GetBitmap(wxART_MAKE_ART_ID_FROM_STR(_T("wxART_GO_FORWARD")),wxART_MENU));
  Menu4->Append(Menu5);
  MenuItem6 = new wxMenuItem(Menu4, ID_MENUITEM5, _("Lire le firmware de la radio"), wxEmptyString, wxITEM_NORMAL);
  MenuItem6->SetBitmap(wxArtProvider::GetBitmap(wxART_MAKE_ART_ID_FROM_STR(_T("wxART_GO_FORWARD")),wxART_MENU));
  Menu4->Append(MenuItem6);
  Menu4->AppendSeparator();
  MenuItem5 = new wxMenuItem(Menu4, ID_MENUITEM4, _("Écrire les réglages et les modèles dans la radio (eeprom)"), wxEmptyString, wxITEM_NORMAL);
  MenuItem5->SetBitmap(wxArtProvider::GetBitmap(wxART_MAKE_ART_ID_FROM_STR(_T("wxART_GO_BACK")),wxART_MENU));
  Menu4->Append(MenuItem5);
  MenuItem7 = new wxMenuItem(Menu4, ID_MENUITEM6, _("Écrire le firmware dans la radio"), wxEmptyString, wxITEM_NORMAL);
  MenuItem7->SetBitmap(wxArtProvider::GetBitmap(wxART_MAKE_ART_ID_FROM_STR(_T("wxART_GO_BACK")),wxART_MENU));
  Menu4->Append(MenuItem7);
  Menu4->AppendSeparator();
  MenuItem8 = new wxMenu();
  MenuItem10 = new wxMenuItem(MenuItem8, ID_MENUITEM9, _("Écrire les fusibles"), wxEmptyString, wxITEM_NORMAL);
  MenuItem10->SetBitmap(wxArtProvider::GetBitmap(wxART_MAKE_ART_ID_FROM_STR(_T("wxART_GO_BACK")),wxART_OTHER));
  MenuItem8->Append(MenuItem10);
  MenuItem11 = new wxMenuItem(MenuItem8, ID_MENUITEM10, _("Écrire le bootloader"), wxEmptyString, wxITEM_NORMAL);
  MenuItem11->SetBitmap(wxArtProvider::GetBitmap(wxART_MAKE_ART_ID_FROM_STR(_T("wxART_GO_BACK")),wxART_OTHER));
  MenuItem8->Append(MenuItem11);
  MenuItem13 = new wxMenuItem(MenuItem8, ID_MENUITEM13, _("Écrire le bootloader F-RAM"), wxEmptyString, wxITEM_NORMAL);
  MenuItem13->SetBitmap(wxArtProvider::GetBitmap(wxART_MAKE_ART_ID_FROM_STR(_T("wxART_GO_BACK")),wxART_MENU));
  MenuItem8->Append(MenuItem13);
  Menu4->Append(ID_MENUITEM7, _("Fusibles et Bootloader"), MenuItem8, wxEmptyString);
  Menu4->AppendSeparator();
  MenuBluetooth = new wxMenuItem(Menu4, ID_MENUBLUETOOTH, _("Bluetooth"), wxEmptyString, wxITEM_NORMAL);
  Menu4->Append(MenuBluetooth);
  MenuBar_main->Append(Menu4, _("Lire/Écrire"));
  Menu7 = new wxMenu();
  CompilOMatic = new wxMenuItem(Menu7, ID_MENUCOMPILOMATIC, _("Compil-O-matic"), wxEmptyString, wxITEM_NORMAL);
  CompilOMatic->SetBitmap(wxArtProvider::GetBitmap(wxART_MAKE_ART_ID_FROM_STR(_T("wxART_EXECUTABLE_FILE")),wxART_MENU));
  Menu7->Append(CompilOMatic);
  MenuBar_main->Append(Menu7, _("Compilateur"));
  Menu2 = new wxMenu();
  MenuHtmlDoc = new wxMenu();
  MenuItem9 = new wxMenuItem(MenuHtmlDoc, ID_MENUITEM11, _("OpenAVRc Manual (JPZ)"), wxEmptyString, wxITEM_NORMAL);
  MenuHtmlDoc->Append(MenuItem9);
  MenuItem14 = new wxMenuItem(MenuHtmlDoc, ID_MENUITEM14, _("Mégamini shield"), wxEmptyString, wxITEM_NORMAL);
  MenuHtmlDoc->Append(MenuItem14);
  MenuItem16 = new wxMenuItem(MenuHtmlDoc, ID_MENUITEM16, _("Mégamini schema"), wxEmptyString, wxITEM_NORMAL);
  MenuHtmlDoc->Append(MenuItem16);
  MenuItem4 = new wxMenuItem(MenuHtmlDoc, ID_MENUITEM8, _("JQ6500 PCB (by Pyrall)"), wxEmptyString, wxITEM_NORMAL);
  MenuItem4->SetBitmap(wxArtProvider::GetBitmap(wxART_MAKE_ART_ID_FROM_STR(_T("wxART_FILE_OPEN")),wxART_MENU));
  MenuHtmlDoc->Append(MenuItem4);
  MenuItem12 = new wxMenuItem(MenuHtmlDoc, ID_MENUITEM12, _("VOICE/AUDIO PCB et RTC (by Pyrall)"), wxEmptyString, wxITEM_NORMAL);
  MenuItem12->SetBitmap(wxArtProvider::GetBitmap(wxART_MAKE_ART_ID_FROM_STR(_T("wxART_FILE_OPEN")),wxART_MENU));
  MenuHtmlDoc->Append(MenuItem12);
  MenuItem15 = new wxMenuItem(MenuHtmlDoc, ID_MENUITEM15, _("Autres links"), wxEmptyString, wxITEM_NORMAL);
  MenuHtmlDoc->Append(MenuItem15);
  Menu2->Append(ID_MENUITEM2, _("Documentation en ligne"), MenuHtmlDoc, wxEmptyString);
  MenuItem2 = new wxMenuItem(Menu2, idMenuAbout, _("A propos\tF1"), wxEmptyString, wxITEM_NORMAL);
  MenuItem2->SetBitmap(wxArtProvider::GetBitmap(wxART_MAKE_ART_ID_FROM_STR(_T("wxART_INFORMATION")),wxART_MENU));
  Menu2->Append(MenuItem2);
  MenuBar_main->Append(Menu2, _("Aide"));
  SetMenuBar(MenuBar_main);
  StatusBar_main = new wxStatusBar(this, ID_STATUSBAR1, 0, _T("ID_STATUSBAR1"));
  int __wxStatusBarWidths_1[1] = { -1 };
  int __wxStatusBarStyles_1[1] = { wxSB_NORMAL };
  StatusBar_main->SetFieldsCount(1,__wxStatusBarWidths_1);
  StatusBar_main->SetStatusStyles(1,__wxStatusBarStyles_1);
  SetStatusBar(StatusBar_main);
  Center();

  Connect(ID_BUTTONSIMUSTD,wxEVT_COMMAND_BUTTON_CLICKED,(wxObjectEventFunction)&OpenAVRc_DesktopFrame::OnButtonSimuSTDClick);
  Connect(ID_BUTTONSIMUFRAM,wxEVT_COMMAND_BUTTON_CLICKED,(wxObjectEventFunction)&OpenAVRc_DesktopFrame::OnButtonSimuFramClick);
  Connect(ID_LISTBOXCONFIG,wxEVT_COMMAND_LISTBOX_SELECTED,(wxObjectEventFunction)&OpenAVRc_DesktopFrame::OnListBoxConfigDClick);
  Connect(ID_LISTBOXCONFIG,wxEVT_COMMAND_LISTBOX_DOUBLECLICKED,(wxObjectEventFunction)&OpenAVRc_DesktopFrame::OnListBoxConfigDClick);
  PanelSplash->Connect(wxEVT_PAINT,(wxObjectEventFunction)&OpenAVRc_DesktopFrame::OnPanelSplashPaint,0,this);
  Connect(ID_BUTTONPERSO,wxEVT_COMMAND_BUTTON_CLICKED,(wxObjectEventFunction)&OpenAVRc_DesktopFrame::OnButtonPersoClick);
  Connect(ID_BUTTONSPLASHDEFAULT,wxEVT_COMMAND_BUTTON_CLICKED,(wxObjectEventFunction)&OpenAVRc_DesktopFrame::OnButtonSplashDefaultClick);
  Connect(ID_CHOICE1,wxEVT_COMMAND_CHOICE_SELECTED,(wxObjectEventFunction)&OpenAVRc_DesktopFrame::OnChoiceLangueSelect);
  Connect(ID_BUTTON2,wxEVT_COMMAND_BUTTON_CLICKED,(wxObjectEventFunction)&OpenAVRc_DesktopFrame::OnEDITEURClick);
  Connect(ID_BUTTON4,wxEVT_COMMAND_BUTTON_CLICKED,(wxObjectEventFunction)&OpenAVRc_DesktopFrame::OnButtonCarteSDClick);
  Connect(ID_MENUITEMNEWCONFIG,wxEVT_COMMAND_MENU_SELECTED,(wxObjectEventFunction)&OpenAVRc_DesktopFrame::OnMenuNewconfigSelected);
  Connect(ID_MENUDELETEACTIVECONFIG,wxEVT_COMMAND_MENU_SELECTED,(wxObjectEventFunction)&OpenAVRc_DesktopFrame::OnMenuDeleteActiveConfigSelected);
  Connect(idMenuQuit,wxEVT_COMMAND_MENU_SELECTED,(wxObjectEventFunction)&OpenAVRc_DesktopFrame::OnQuit);
  Connect(ID_MENUITEMCOMMUNICATION,wxEVT_COMMAND_MENU_SELECTED,(wxObjectEventFunction)&OpenAVRc_DesktopFrame::OnProgrammerSelected);
  Connect(ID_MENUVOICECHOICE,wxEVT_COMMAND_MENU_SELECTED,(wxObjectEventFunction)&OpenAVRc_DesktopFrame::OnMenuChoiceVoiceSelected);
  Connect(ID_MENUITEM3,wxEVT_COMMAND_MENU_SELECTED,(wxObjectEventFunction)&OpenAVRc_DesktopFrame::OnreadmodelsSelected);
  Connect(ID_MENUITEM5,wxEVT_COMMAND_MENU_SELECTED,(wxObjectEventFunction)&OpenAVRc_DesktopFrame::OnreadfirmwareSelected);
  Connect(ID_MENUITEM4,wxEVT_COMMAND_MENU_SELECTED,(wxObjectEventFunction)&OpenAVRc_DesktopFrame::OnWriteModelToRadioSelected);
  Connect(ID_MENUITEM6,wxEVT_COMMAND_MENU_SELECTED,(wxObjectEventFunction)&OpenAVRc_DesktopFrame::OnWriteFirmwareToRadioSelected);
  Connect(ID_MENUITEM9,wxEVT_COMMAND_MENU_SELECTED,(wxObjectEventFunction)&OpenAVRc_DesktopFrame::OnEcrirelesFuseesSelected);
  Connect(ID_MENUITEM10,wxEVT_COMMAND_MENU_SELECTED,(wxObjectEventFunction)&OpenAVRc_DesktopFrame::OnEcrirelebootloaderSelected);
  Connect(ID_MENUITEM13,wxEVT_COMMAND_MENU_SELECTED,(wxObjectEventFunction)&OpenAVRc_DesktopFrame::OnEcrirelebootloaderF_RAMSelected);
  Connect(ID_MENUBLUETOOTH,wxEVT_COMMAND_MENU_SELECTED,(wxObjectEventFunction)&OpenAVRc_DesktopFrame::OnMenuBluetoothSelected);
  Connect(ID_MENUCOMPILOMATIC,wxEVT_COMMAND_MENU_SELECTED,(wxObjectEventFunction)&OpenAVRc_DesktopFrame::OnCompilOMaticSelected);
  Connect(ID_MENUITEM11,wxEVT_COMMAND_MENU_SELECTED,(wxObjectEventFunction)&OpenAVRc_DesktopFrame::OnMenuItem9Selected);
  Connect(ID_MENUITEM14,wxEVT_COMMAND_MENU_SELECTED,(wxObjectEventFunction)&OpenAVRc_DesktopFrame::OnMenuItem14Selected);
  Connect(ID_MENUITEM16,wxEVT_COMMAND_MENU_SELECTED,(wxObjectEventFunction)&OpenAVRc_DesktopFrame::OnMenuItem16Selected);
  Connect(ID_MENUITEM8,wxEVT_COMMAND_MENU_SELECTED,(wxObjectEventFunction)&OpenAVRc_DesktopFrame::OnMenuJQ6500_PCBSelected);
  Connect(ID_MENUITEM12,wxEVT_COMMAND_MENU_SELECTED,(wxObjectEventFunction)&OpenAVRc_DesktopFrame::OnMenuVOICE_AUDIO_PCBSelected);
  Connect(idMenuAbout,wxEVT_COMMAND_MENU_SELECTED,(wxObjectEventFunction)&OpenAVRc_DesktopFrame::OnAbout);
  Connect(wxID_ANY,wxEVT_CLOSE_WINDOW,(wxObjectEventFunction)&OpenAVRc_DesktopFrame::OnClose);
  //*)

  {
    SetIcon(wxICON(oavrc_icon));
  }
  MenuBluetooth->SetBitmap(wxBitmap(wxImage(Bluetooth_icon)));
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

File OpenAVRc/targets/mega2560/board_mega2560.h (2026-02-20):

/*
**************************************************************************
*                                                                        *
*                 ____                ___ _   _____                      *
*                / __ \___  ___ ___  / _ | | / / _ \____                 *
*               / /_/ / _ \/ -_) _ \/ __ | |/ / , _/ __/                 *
*               \____/ .__/\__/_//_/_/ |_|___/_/|_|\__/                  *
*                   /_/                                                  *
*                                                                        *
*              This file is part of the OpenAVRc project.                *
*                                                                        *
*                         Based on code(s) named :                       *
*             OpenTx - https://github.com/opentx/opentx                  *
*             Deviation - https://www.deviationtx.com/                   *
*                                                                        *
*                Only AVR code here for visibility ;-)                   *
*                                                                        *
*   OpenAVRc is free software: you can redistribute it and/or modify     *
*   it under the terms of the GNU General Public License as published by *
*   the Free Software Foundation, either version 2 of the License, or    *
*   (at your option) any later version.                                  *
*                                                                        *
*   OpenAVRc is distributed in the hope that it will be useful,          *
*   but WITHOUT ANY WARRANTY; without even the implied warranty of       *
*   MERCHANTABILITY or FITNESS FOR A PARTICULAR PURPOSE.  See the        *
*   GNU General Public License for more details.                         *
*                                                                        *
*       License GPLv2: http://www.gnu.org/licenses/gpl-2.0.html          *
*                                                                        *
**************************************************************************
*/


#ifndef _BOARD_MEGA2560_H_
#define _BOARD_MEGA2560_H_

#include "../../board_avr.h"

#define CALCULATE_LAT_JIT()  dt = TCNT1 - OCR1A // Calculate latency and jitter.
#define RF_TIMER             TCNT1
#define RF_TIMER_COMPA_REG   OCR1A
#define RF_TIMER_COMPA_VECT  TIMER1_COMPA_vect

//Mods
#define MEGACORELEDPIN            PIN7_bm

// Keys
void readKeysAndTrims();
#define GPIO_KEYS                 PINL
#define KEYS_GPIO_PIN_MENU        PIN4_bm
#define KEYS_GPIO_PIN_EXIT        PIN5_bm
#define KEYS_GPIO_PIN_RIGHT       PIN2_bm
#define KEYS_GPIO_PIN_LEFT        PIN3_bm
#define KEYS_GPIO_PIN_UP          PIN1_bm
#define KEYS_GPIO_PIN_DOWN        PIN0_bm
// DBLKeys driver
#define KEYS_PRESSED()            (~GPIO_KEYS)


// Trims
#define GPIO_TRIMS                PINF
#define TRIMS_GPIO_PIN_LHL        PIN7_bm
#define TRIMS_GPIO_PIN_LVD        PIN5_bm
#define TRIMS_GPIO_PIN_RVU        PIN2_bm
#define TRIMS_GPIO_PIN_RHL        PIN1_bm
#define TRIMS_GPIO_PIN_LHR        PIN6_bm
#define TRIMS_GPIO_PIN_LVU        PIN4_bm
#define TRIMS_GPIO_PIN_RVD        PIN3_bm
#define TRIMS_GPIO_PIN_RHR        PIN0_bm
#define TRIMS_PRESSED()           (~GPIO_TRIMS)

#define COUNTER_64uSH             TCNT3H
#define COUNTER_64uSL             TCNT3L
#define TIMER_10MS_VECT           TIMER3_COMPA_vect
#define TIMER_10MS_COMPVAL        OCR3A

// Backlight driver
#if !defined(PWM_BACKLIGHT)
#define backlightEnable()         PORTC |= _BV(OUT_C_LIGHT)
#define backlightDisable()        PORTC &= ~_BV(OUT_C_LIGHT)
#define isBacklightEnable()       (PINC & _BV(OUT_C_LIGHT))
#define BACKLIGHT_ON()            PORTC |= _BV(OUT_C_LIGHT)
#define BACKLIGHT_OFF()           PORTC &= ~_BV(OUT_C_LIGHT)
#define EnableCoreLed()           PORTB |= (MEGACORELEDPIN) // Blink on function
#define DisableCoreLed()          PORTB &= ~(MEGACORELEDPIN) // Blink off function
#define LEDON()                   EnableCoreLed()
#define LEDOFF()                  DisableCoreLed()
#else
// OC0A on pin PB7 (pin26) aka MEGACORELEDPIN
#define BACKLIGHT_ON()            (OCR0A = ( (uint8_t) g_eeGeneral.blOnBright)  <<4)
#define BACKLIGHT_OFF()           (OCR0A = ( (uint8_t) g_eeGeneral.blOffBright) <<4)
#define LEDON()
#define LEDOFF()
#endif

// SD driver
#define SDCARD_CS_N_ACTIVE()        PORTB &= ~PIN0_bm // MMC CS = L
#define select_card()               SDCARD_CS_N_ACTIVE()
#define SDCARD_CS_N_INACTIVE()      PORTB |= PIN0_bm // MMC CS = H
#define unselect_card()             SDCARD_CS_N_INACTIVE()
#define SDCARD_CS_N_IS_INACTIVE()   (PINB & PIN0_bm)
#define SPI_250K()                  { SPSR = _BV(SPI2X); SPCR = _BV(SPE) | _BV(MSTR) | _BV(SPR1) | _BV(SPR0); }
#define SPI_4M()                    { SPCR = _BV(SPE) | _BV(MSTR); }
#define SPI_8M()                    { SPSR = _BV(SPI2X); SPCR = _BV(SPE) | _BV(MSTR); }
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

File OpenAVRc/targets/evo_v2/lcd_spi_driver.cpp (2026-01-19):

/*
 * Authors (alphabetical order)
 *
 * - Rick Kilvington (2020).
 *
 */

/*
 *****************************************************************
 * LCD driver for a 132 * 64 LCD as fitted in the EVO transmitter.
 * All information was derived by tracing the SPI messages.
 * LCD looks to be ST7565R compatible with a CS+ chip select.
 * Written for Xmega SPI and Bit-Bang.
 * Adapted from USART MSPI code.
 * As this is a uni-directional driver, choose Bit-Bang to reclaim
 * the unused MISO pin.
 * USART MSPI would be better and can do DMA
 * too unlike the SPI port.
 * No Reset signal as that is derived from RTC chip.
 *****************************************************************
*/


void lcdClearRAM(void);


//#define LCD_SSD1309
//#define LCD_EVO
#define LCD_ST7567
#define BITBANGSPI
//#define SPI9BIT // Bitbang only !

#if defined(LCD_EVO)
// #define CONTRAST_MIN 10
 #define LCD_SIZE_132X64
 #define POSITIVE_CHIP_SELECT
#endif
#if defined(LCD_ST7567)
// #define CONTRAST_MIN 35
#define LCD_SIZE_132X64
#define POSITIVE_CHIP_SELECT
#endif
#if defined(LCD_SSD1309)
// #define CONTRAST_MIN 30
#endif

#if !defined (BITBANGSPI)
#include "spi.h"
#endif

#define SSD1309_CMD_SETCMDLOCK            0xFD
#define SSD1309_CMD_DISPLAYSLEEP          0xAE
#define SSD1309_CMD_DISPLAYWAKEUP         0xAF
#define SSD1309_CMD_SETDISPLAYCLOCKDIV    0xD5 // ?
#define SSD1309_CMD_SETMULTIPLEX          0xA8
#define SSD1309_CMD_SETDISPLAYOFFSET      0xD3
#define SSD1309_CMD_SETMEMORYADDRESSMODE  0x20
#define SSD1309_CMD_SET_COLUMN_START_AND_END_ADDRESS  0x21
#define SSD1309_CMD_SETSEGMENTREMAPNORM   0xA0
#define SSD1309_CMD_SETSEGMENTREMAPREV    0xA1
#define SSD1309_CMD_SETCOMOUTPUTDIRNORM   0xC0
#define SSD1309_CMD_SETCOMOUTPUTDIRREV    0xC8
#define SSD1309_CMD_SETCOMPINSHARDCONF    0xDA
#define SSD1309_CMD_DISPLAYALLON          0xA5 // All dots on.
#define SSD1309_CMD_DISPLAYALLON_RESUME   0xA4 // Display RAM contents.
#define SSD1309_CMD_SETCONTRAST           0x81
#define SSD1309_CMD_NORMALDISPLAY         0xA6
#define SSD1309_CMD_INVERTDISPLAY         0xA7
#define SSD1309_CMD_SETVCOMDETECT         0xDB
#define SSD1309_CMD_SETPRECHARGE          0xD9
#define SSD1309_CMD_SETSTARTLINE( line )               (0x40 | (line))
#define SSD1309_CMD_PAGE_ADDRESS_SET( page )           (0xB0 | (page))
#define SSD1309_CMD_COLUMN_ADDRESS_SET_LSB( column )   (0x00 | (column))
#define SSD1309_CMD_COLUMN_ADDRESS_SET_MSB( column )   (0x10 | (column))


#define ST756n_CONTRAST_MAX 63
#define ST756n_CMD_VOLTAGE_RESISTOR_RATIO_3dec0    0x20
#define ST756n_CMD_VOLTAGE_RESISTOR_RATIO_3dec5    0x21
#define ST756n_CMD_VOLTAGE_RESISTOR_RATIO_4dec0    0x22
#define ST756n_CMD_VOLTAGE_RESISTOR_RATIO_4dec5    0x23
#define ST756n_CMD_VOLTAGE_RESISTOR_RATIO_5dec0    0x24
#define ST756n_CMD_VOLTAGE_RESISTOR_RATIO_5dec5    0x25
#define ST756n_CMD_VOLTAGE_RESISTOR_RATIO_6dec0    0x26
#define ST756n_CMD_VOLTAGE_RESISTOR_RATIO_6dec5    0x27

#define ST756n_CMD_RESET                       0xE2
#define ST756n_CMD_DISPLAY_ALL_POINTS_OFF      0xA4
#define ST756n_CMD_DISPLAY_ALL_POINTS_ON       0xA5
#define ST756n_CMD_DISPLAY_NORMAL              0xA6
#define ST756n_CMD_DISPLAY_INVERSE             0xA7
#define ST756n_CMD_NORMAL_COM_DIRECTION        0xC0
#define ST756n_CMD_REVERSE_COM_DIRECTION       0xC8
#define ST756n_CMD_NORMAL_SEG_DIRECTION        0xA0
#define ST756n_CMD_REVERSE_SEG_DIRECTION       0xA1
#define ST756n_CMD_BIAS_SELECT_7TH             0xA3
#define ST756n_CMD_BIAS_SELECT_9TH             0xA2
#define ST756n_CMD_CONTRAST_SET                0x81 // 2 Byte command
#define ST756n_CMD_SET_BOOSTER_LEVEL           0xF8 // 2 byte command

#define ST756n_CMD_POWER_CTRL                  0x28
#define ST756n_CMD_DISPLAY_OFF                 0xAE
#define ST756n_CMD_DISPLAY_ON                  0xAF
#define ST756n_CMD_START_LINE_SET( line )             (0x40 | (line))
#define ST756n_CMD_PAGE_ADDRESS_SET( page )           (0xB0 | (page))
#define ST756n_CMD_COLUMN_ADDRESS_SET_MSB( column )   (0x10 | (column))
#define ST756n_CMD_COLUMN_ADDRESS_SET_LSB( column )   (0x00 | (column))


#define LCD_PORT       PORTD
#define O_LCD_MOSI     PIN7_bm
#define O_LCD_SCK_P    PIN5_bm

#define LCD_CLK_HI     LCD_PORT.OUTSET = O_LCD_SCK_P
#define LCD_CLK_LO     LCD_PORT.OUTCLR = O_LCD_SCK_P

#if defined (BITBANGSPI)
#define LCD_MOSI_HI    LCD_PORT.OUTSET = O_LCD_MOSI
#define LCD_MOSI_LO    LCD_PORT.OUTCLR = O_LCD_MOSI
#define WAIT_LCD_TX_FIN
#else
#define LCD_SPI    SPID
#define WAIT_LCD_BUFFER_EMPTY  while (! (LCD_SPI.STATUS & SPI_IF_bm)) // Same as below due to reused USART MPSPI code.
#define WAIT_LCD_TX_FIN        while (! (LCD_SPI.STATUS & SPI_IF_bm)) // Wait for USART transmit shift register to empty.
#endif

#define O_LCD_CS           PIN4_bm

#if defined (POSITIVE_CHIP_SELECT)
#define LCD_CS_ACTIVE      LCD_PORT.OUTSET = O_LCD_CS
#define LCD_CS_INACTIVE    LCD_PORT.OUTCLR = O_LCD_CS
#else
// Negative Chip select.
#define LCD_CS_INACTIVE    LCD_PORT.OUTSET = O_LCD_CS
#define LCD_CS_ACTIVE      LCD_PORT.OUTCLR = O_LCD_CS
#endif
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

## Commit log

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2018-07-07 Update gerber
    changes 5v wire width on I2C connector.
    [Mega_2560 core mini_full_2.1-B.Cu.gbr, Mega_2560 core mini_full_2.1-B.Fab.gbr, Mega_2560 core mini_full_2.1-F.Cu.gbr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]
2018-07-18 Simu bug resolved : Edit model name dialog move to main thread
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2018-07-31 Update documentation v2.0 file
    - replace texte for P27 connector (batt -> hp)
    - littles cosmetic changes
2018-07-31 Add Solder mask gerber
    Add solder mask gerber file for LM386 board
    [LM386Amplifier-F.Mask.gbr]
2018-08-06 PCB MPX alim clean gerber file
    [MPX_Alimentation-B.Cu.gbr, MPX_Alimentation-B.Fab.gbr, MPX_Alimentation-B.Paste.gbr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]
2018-08-07 Update drill switch
    change drill switch (0.9 to 1.1)
    change pad size switch (1.4 to 1.6)
    [MPX_Alimentation.kicad_pcb]
2018-08-07 Update pcb shield
    Change date only
    Update bom (bile of materials)
    [Mega_2560 core mini_full_2.1.csv, Mega_2560 core mini_full_2.1.kicad_pcb, Mega_2560 core mini_full_2.1.sch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]
2018-08-07 Update gerber and pdf for v2.1
    [Mega_2560 core mini_full_2.1-B.Cu.gbr, Mega_2560 core mini_full_2.1-B.Fab.gbr, Mega_2560 core mini_full_2.1-B.Mask.gbr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]
2018-08-07 Update doc file v2.0
    Update cc2500 pictures .
    Update schematic sticks picture
    Thanks to Christian for theses changes
2018-08-07 Add new gerber end pdf files
    [MPX_Alimentation-B.Cu.gbr, MPX_Alimentation-B.Fab.gbr, MPX_Alimentation-B.Mask.gbr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]
2018-08-08 I2C driver : Set Stop() condition on error.
    [i2c_master.cpp]
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2018-08-17 Menu general show transmitter temperature if RTC is connected
    Resolution : 0.25°C
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2018-08-25 Add SPI level convertors files
    Add new schematic and pcb files
    [Adaptateurs_NiveauxSPI.kicad_pcb, Adaptateurs_NiveauxSPI.sch]
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2018-08-25 Add gerber and pdf files
    [Adaptateurs_NiveauxSPI-B.Cu.gbr, Adaptateurs_NiveauxSPI-B.Fab.gbr, Adaptateurs_NiveauxSPI-B.Mask.gbr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]
2018-08-25 Update silkscreen and fab files
    [Adaptateurs_NiveauxSPI-B.Fab.gbr, Adaptateurs_NiveauxSPI-B.SilkS.gbr, Adaptateurs_NiveauxSPI-F.Fab.gbr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]
2018-08-28 test upload
    [Adaptateurs_NiveauxSPI-F.Mask.gbr]
2018-08-28 remove file
    remove test file
    [Adaptateurs_NiveauxSPI-F.Mask.gbr]
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2018-08-30 Update doc v2.1
    -replace first 3d picture.
    -add 3,3v/5v haptic infos.
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2018-09-07 Update SPI boards
    - Add CYRF9636 board
    - Update CC2500 board
    [Adaptateurs_NiveauxSPI.kicad_pcb, Adaptateurs_NiveauxSPI.sch]
2018-09-07 Update gerber SPI boards
    [Adaptateurs_NiveauxSPI-B.Adhes.gbr, Adaptateurs_NiveauxSPI-B.Cu.gbr, Adaptateurs_NiveauxSPI-B.Fab.gbr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]
2018-09-08 Update pcb shield v2.1 files
    Replace R1 to R14 values from 120K to 68K
    [Mega_2560 core mini_full_2.1.kicad_pcb, Mega_2560 core mini_full_2.1.sch, OpenAVRc_Audio_Haptic.sch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]
2018-09-08 Update gerber and pdf v2.1 files
    [Mega_2560 core mini_full_2.1-B.Fab.gbr, Mega_2560 core mini_full_2.1-Edge.Cuts.gbr, Mega_2560 core mini_full_2.1-F.Fab.gbr]
2018-09-08 Update documentation v2.1 file
    -Remove mp1584en with enable feature (3b).
    -Update 'Alimentation (LIPO)'.
    -Change RV1 position (180°).
    -Add LCD parallel P16 reverse info.
2018-09-09 Update silk screen top v2.1 shield
    [Mega_2560 core mini_full_2.1-F.SilkS.gbr]
2018-09-09 Update pcb for silk screen RV1 only on top
    [Mega_2560 core mini_full_2.1.kicad_pcb]
2018-09-09 Update gerber & pdf v2.1
    Update gnd copper plan (on bottom)
    [Mega_2560 core mini_full_2.1-B.Adhes.gbr, Mega_2560 core mini_full_2.1-B.CrtYd.gbr, Mega_2560 core mini_full_2.1-B.Cu.gbr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]
2018-09-09 Update pcb v2.1 files
    -update gnd copper plan on bottom
    [Mega_2560 core mini_full_2.1.kicad_pcb]
2018-09-13 Update v2.1 gerber and pdf
    - Replace B7 by B4 (future Bluetooth command)
    [Mega_2560 core mini_full_2.1-B.Adhes.gbr, Mega_2560 core mini_full_2.1-B.CrtYd.gbr, Mega_2560 core mini_full_2.1-B.Cu.gbr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]
2018-09-13 Update pcb files
    - Replace B7 pin by B4 pin (future Bluetooth).
    [Mega_2560 core mini_full_2.1.csv, Mega_2560 core mini_full_2.1.kicad_pcb, Mega_2560 core mini_full_2.1.sch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]
2018-09-13 Major change : Full SD code rewrited + new driver :heart_eyes:
    Use Roland Riegel SD driver : http://www.roland-riegel.de/
    Thanks
2018-09-14 Re organise files + remove .bak files
    [Adaptateurs_NiveauxSPI-B.Adhes.gbr, Adaptateurs_NiveauxSPI-B.Cu.gbr, Adaptateurs_NiveauxSPI-B.Fab.gbr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]
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2018-09-15 Check Vbat in splash to load initial value
    + Change the low filter value
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2018-09-23 Telemetry ALT bug solved
    [OpenAVRc.cpp]
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2018-10-19 SD driver mods (create system repertory at start if needed)
    Will add a spalsh ...
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2018-10-25 Remove EVO_V1 PCB. Fix avr-size.
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2018-11-06 Add / update xmega files. ToDo ... Watchdog. Rotary Encoders. Keyboard (When PCB arrives). Write PPM Pulses. Test SPI pulses (CC2500 & CYRF).
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2018-11-09 Megamini : backlightFade() was missing :-(
    [board_megamini.cpp]
2018-11-10 I2C address of expenders fixed in X-Any chapter
2018-11-10 I2C 7 bits addresses fixed for extenders
2018-11-11 Desktop : EncNo switch name was not saved in Personame option.
    Tanks JPZ.
2018-11-13 First element of array should be 0 to cause generation of new PPM frame.
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2018-11-17 8 x contacts wiring fixed for PCF8574 I/O Expanders
2018-11-19 All Protocols and pulses start in 16 milli-seconds. Added xmega support and split some functions / ISR. Maybe some #defines would merge both xmega and m2560 hardware platforms.
2018-11-24 Change ambiguous Timer16Khz code : Talk about 64uS now
    Thanks Sloped Soarer
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2018-11-25 Probe for subsequent I2C angle sensors fixed
2018-11-25 Break up switches code. Add Event System Prescalar to get 2MHz counter clock. Pulse / Protocol Timers now compatible with Mega2560.
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2018-11-25 Use timer3 (real 16 bits) to remplace timer 2
    Used to produce 64uS counter & ISR10mS
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2018-11-28 Timer3 bug removed ? + Cosmetic (getTmr10ms)
    To test Thanks Slopded Soarer :+1:
    [OpenAVRc.cpp]
2018-11-29 A Frsky telemetry option to evo_v2 build and reference to missing file printf.
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2018-11-30 Switch (warning and logical) bugfix
2018-12-01 A file to record the X-Any test status for the diffrent protocols
    [XanyProtoTestCoverage.ods]
2018-12-01 X-Any test status update
    [XanyProtoTestCoverage.ods]
2018-12-01 Update XanyProtoTestCoverage.ods
    RX name precision
    [XanyProtoTestCoverage.ods]
2018-12-01 Simu : Fix compilation
    Create global Xany_scheduleTx_AllInstance() function
    [OpenAVRc.cpp, simu_interface.h]
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2018-12-03 Add files via upload
    Nouvelle version avec variables de télémesure et modifs écrans
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2018-12-11 Add files via upload
    Mise à jour 0.4 des documents: Position diodes vibreur, écrans + corrections mineures
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2018-12-18 SDcard driver : use LCD buffer.. Save 512 bytes of Sram :+1:
    Some function need now a "lcdclear()" to avoid screen artefact
    Sram saved will be used soon ...........
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2019-01-06 Reset RF power at (re) start
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2019-01-11 Add files via upload
    Mise à jour des documents:
    - Ajout infos sur télémesure (correction erreur CI), Adaptation Manches Hall, Correction erreurs de valeurs, Nettoyage.
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2019-01-25 M/P bug resolved + Add Sblacksono M2560 driver
    [board_mega2560.cpp, board_mega2560.h]
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2019-02-26 Megamini driver : Reset CS pin first
    [board_megamini.cpp]
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2019-03-25 Solve compilation error without SPIMODULE option
    [board_megamini.cpp]
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2019-04-04 Init LCD and clear it at soon as possible
    Add a "start message" -> usefull with a new SDcard inserted.
    Resolve the error : refresh LCD before init. Oups !
    [OpenAVRc.cpp, board_mega2560.cpp, board_megamini.cpp]
2019-04-07 JQ (Voice) driver update
    No missing prompts (I hope)
    Buffer size is 32 prompts now
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2019-04-14 Xany fully reworked, now, Prop can be chosen among any Ana Pots from the X-Any menu, more combinations supported (20 bit payload max) -> Desktop to be simplified (Pot choice)
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2019-04-28 Xany menu : Prop value shorter
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2019-05-13 GPS : Wait the second frame to valid fix
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2019-05-27 Bug resolved : Negative speed value past 120 Km/h
    [OpenAVRc.cpp]
2019-06-03 Reduce GPS fix time for people ho live near the Greenwich Meridian
    In this case, the GPS take a long time to send E/W data.
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2019-08-13 Some fixes to allow compilation
    [bluetooth.cpp]
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2019-08-19 FW and Bootloader : Reboot with flag function (save code)
    [BootFramM2560.c, OpenAVRc.cpp]
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2019-08-29 Mixer optimise + debug
    Create MixVal struct
    Optimise mixer
    (re)move s_mixer_first_run_done to the correct place
    Remove unusefull code
    -> Same computing time, 100 bytes of S-RAM saved
    [OpenAVRc.cpp]
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2019-09-04 BT on-off ... oups ! (Fet need inverted signal)
    [board_mega2560.h, board_megamini.h]
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2019-09-25 BT : waitForResp(...) bug killed
    [bluetooth.cpp]
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2019-10-13 Crappy and unconsistent Password/Pin commands fixed (not tested)
    [bluetooth.cpp]
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2019-11-24 Simplification and bug fixes, to be continued...
    [bluetooth.cpp]
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2019-11-30 As BT PIN code doesn't need to be stored, size of Remote name increased from 8 to 10 characters (global structure size kept)
2019-12-30 Fix SIMU linker error with release build
    [board_megamini.h]
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2019-12-31 BT : CMODE=0 missed to connect
    [bluetooth.cpp]
2020-01-03 - Compatible I2C AD1335 absolute angular sensor support fixed (endian issue) - Angle is transported in X-Any message with 12 bit resolution (rather than 11)
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2020-01-20 BT : Better dialog with HC (MEnu reset the HC now -> Loose connection)
    [bluetooth.cpp]
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2020-02-26 Fix puppy first prompt
    [OpenAVRc.cpp]
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2020-03-02 Simply Hwserial (run faster : X2.. But uart number is fixed now)
    [OpenAVRc.cpp]
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2020-03-24 BT driver : Restore key command after reset in speed detection function
    [bluetooth.cpp]
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2020-03-29 BT driver send channels (missed file update)
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2020-04-10 FW : Update BT driver (re) add INIT + RESET
    + uncomment needed bluetooth_AtCmdMode(OFF);
    [bluetooth.cpp]
2020-04-11 Add Voice Files in Desktop directory
    CZ will come in soon ;-)
    [Voice_EN.csv, Voice_ES.csv, Voice_FR.csv]
2020-04-11 Added voice files "CZ" (#21)
    Thank you :+1:
    [Voice_CZ.csv]
2020-04-12 Adding buzzs "Voice_CZ.csv" (#22)
    :beers:
    [Voice_CZ.csv]
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2020-04-18 Insert space ... typo :)
    [Voice_EN.csv]
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2020-04-30 Xmodem bug found : getDirAndBaseName alter Fullpath
    Workaround .. TODO find better solution and place in SD driver.
    Model file PC->TX take 0.5 Second in xmodem checsum mode ;-)
    TX->PC : bug :(
2020-05-01 put getDirAndBaseName in SD driver file
    +Debug xmodem_cfg function (correct path if is ROOT)
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2020-06-13 Revert "First working version of JQ8400-TF Voice driver."
    This reverts commit 925a2c68c2053827fbeabcbbf9b6c696b6978774.
2020-07-18 Delete xmega_lcd_driver.cpp
    Original Evo LCD (132 Columns) not tested or used for some time, so code is out of date. File to be deleted and replaced with updated driver with new file name.
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2020-07-18 Fix compilation for build without SPIMODULES.
    [board_mega2560.cpp]
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2020-07-23 Correct misplaced endif for EVO_V2 board.
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2020-07-26 Xmega ADC. Internal Bandgap is no longer used for TX_VOLTAGE measurement. Bandgap was on limit of 1%.
    [OpenAVRc.cpp, xmega_adc_driver.cpp]
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2020-08-13 FW : Resolve hight logical switches (>9) reentrance bug
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2020-09-18 Fixed interrupts init procedure for arduino mega2560 board. (#38)
    [board_mega2560.cpp]
2020-09-25 NFR driver : Bad define correction (Thanks Payalneg)
    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
2021-01-14 Revert "Merge branch 'V3' of https://github.com/Ingwie/OpenAVRc_Dev into V3"
    This reverts commit 5e848f0609ff2ab4661a85d3079bb781c852e6f3, reversing
    changes made to 1e4d498fc2716fea2e8d819e3af8627f84e075e1.
    [OpenAVRc_DesktopMain.cpp]
2021-01-17 Revert "Revert "Merge branch 'V3' of https://github.com/Ingwie/OpenAVRc_Dev into V3""
    This reverts commit 82c2f8f3d9a5a1cfb5a8ef327b9c0e77636f5f64.
    [OpenAVRc_DesktopMain.cpp]
2021-01-17 Included communication nRF24L01P "Stanek". Fixed RF channel, fixed address. (#45)
    * Add communication nRF24L01P "Stanek"
    Fixed RF channel, fixed address. Channel reduction 2 -> 12ch. This is the maximum of the Arduino RX receiver of the "Servo" library on the Atmega328P processor. Support for Arduino-based receivers and RF24 libraries from this repository https://github.com/stanekTM/RC_RX_nRF24L01_Telemetry_Motor_Driver_Servo
    Thanks to "Bracame Ingwie" from the "OpenAVRc" https://github.com/Ingwie/OpenAVRc_Dev team for the code base.
    * Update README.md
    * Update STANEK_nrf24l01.c
    * Update README.md
    * Update STANEK_nrf24l01.c
    * Update STANEK_nrf24l01.c
    * Update README.md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
2021-02-10 FW : unplug digital port K from used analog pin
    Less disturbances :) (impedance and noise)
    [adc_driver.cpp]
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2021-04-07 Add missing define (There is always one !).
    [board_avr.h]
2021-04-08 FW : Fix some EVO_V2 compilation issues
    [board_avr.h]
2021-04-09 Fix some more EVO_V2 compilation issues.
    [xmega_board.h]
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2021-07-27 Bug fix. RF Power value being overwritten.
2021-07-29 Prevent >1 SPI protocol reset causing WDT reset.
2021-07-30 Add two new baud rates and fix missing terminators ";".
    [xmega_board.h]
2021-09-13 1. TX_RX_OFF moved after successful reset. 2. Xmega does not use 3 wire SPI Bit Bang Functions.
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2021-10-18 FW : Avoid calling twice startPulses(PROTOCMD_INIT) at boot
    Thanks Rich :+1:
    [OpenAVRc.cpp]
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2022-03-05 Better A7105 reset and calibration. Should prevent WDT resets or protocols not working due to ~ 4ms IF Filter Bank calibration for Flysky.
2022-06-01 Fix. Xmega stuck in loop as keyboard is read by ADC.
    [OpenAVRc.cpp]
2022-06-05 Fw : Reset encoder value in flight reset
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2023-03-20 Bug fix. Missing Timer vector.
    [xmega_board.h]
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2023-07-15 PCM integrration update
    Change line ending
    Simu compilation rework
    [OpenAVRc.cpp, bluetooth.cpp]
2023-09-10 Correct typo and bootloader.
    Correct typo and bootloader register checks ... xmega only.
    [xboot.c]
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2023-10-01 Remove typo which was hiding a bug !
    [xmega_board.h]
2023-10-03 Fix xmega PWM backlight.
2024-06-11 Correct Serial port pin.
    Safer to have serial RXD pin with pullup active. Correct port in confusion.
    [board_megamini.cpp, board_megamini.h]
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2025-03-28 Tidy switches code.
    Tidy switches code whilst hunting down an xmega (EVO_V2) related bug.
    [xmega_board.h]
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2025-04-19 Fix Simu compilation + Updates
    Use Linux port branch code.
    [OpenAVRc_DesktopMain.cpp, uart.c]
2025-04-25 Update AFHDS2A_a7105.c
    Fix TGY-i4X receiver, servo moves to max.
    14 channels maximum at the moment.
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2025-11-30 Restore lost commits after a bugged reset (#69)
    * Cosmetic/clean code (serial definition)
    * Remove broken code (Tiny Debuger)
    * Chek pulses2MHz buffer size (152 bytes with PCM)
    * Undefine PWMANAGE on Megamini and M2560 board
    Asked by users
    * Makefile : compiler correction
    * Cosmetic
    * Update OpenAVRc.cbp
    * Save SRAM (multi shw version)
    * Save SRAM (Multiprotocole drive : change static uint to p2m)
    * check crsf p2m size
    * Cosmetic
    * Remove duplicated functions
    * Debug Show multi version with harware !!
    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
    [OpenAVRc.cpp, board_avr.h, board_mega2560.h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]
2025-12-07 Fw : Optimise Frsky telemetry parser
    Ignore uart error detection (was optimised only for S.port)
    Set all parseTelemFunction const
    Rename LoadTelemBuffer LoadFrskyTelemBuffer
    [OpenAVRc.cpp]
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2025-12-10 Add debug pin (xmega) and Missing Sensor ID for SPORT Telemetry. (#73)
    * Add Xmega debug pin states.
    * Add Valid Frame Rate Sensor ID.
    [xmega_board.h]
2025-12-19 FW : Check serial error on telemetry parset
    Separate SPI - serial parser.
    Whith this check, Multi work perfectly on M2560
    [OpenAVRc.cpp]
2025-12-19 Update Voice_EN.csv
    Prefer plural units ... they are correct most of the time.
    Prefer "decimal" to "point". ICAO standard phraseology.
    [Voice_EN.csv]
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2025-12-24 Repair corrupted voice files
    [Voice_ES.csv, Voice_FR.csv]
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2026-01-28 Updates to tidy code, fix pgm_read_byte_far() for xmega.
    Tidy code.
    Fix pgm_read_byte_far() not working for xmega LCD initialisation array.
    Stay in Bootloader if no application vector found.
    Use Elevator Dual Rate switch for bootloader entry. for The Ingwies testing board.
    [lcd_default_driver.c, lcd_driver.c, lcd_spi_driver.c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]
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2026-02-11 Correct BT_IS_CONNECTED
    Was output register, now input.
    [board_megamini.h]
2026-02-13 Revert "Correct BT_IS_CONNECTED"
    This reverts commit 6b14ed12ec69ebf531dc298091defaeeeb85b6dd.
    [board_megamini.h]
2026-02-13 Correct BT_IS_CONNECTED
    Got it right this time 8-)
    [board_megamini.h]
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2026-08-24 Refactor STANEK nRF24L01 protocol (#88)
    Large refactor of STANEK_nrf24l01.c: hardware Auto-ACK disabled (time management is taken over by software); reorganized initialization, registers and FIFO handling; added named P2M fields and RF constants; revamped telemetry handling (TSSI calculation, telemetry parsing, timeouts); reworked packet build/send logic and packet size calculation; redesigned timing management and RX/TX toggle to reduce jitter; added mixer and fail-safe counters with auto-clear behavior; updated PROTO command handlers (INIT, RESET, BIND, GETOPTIONS) and RF menu settings. Code comments clarified and Czech annotations (if you don't mind) added for maintainability.
2026-09-06 Removed Schottky Diode Voltage drop.
    Schottky Diode for reverse polarity protection was replaced by MOSFET. Body diode prevents reverse voltage and turns on MOSFET.
    [OpenAVRc.cpp]
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2026-11-02 Simple FHSS RF Protocol (#99)
    Simple RF protocol with frequency hopping (FHSS) and two-way telemetry (Auto-ACK Payload).
    Rapid hopping between 4 strong RF channels (12, 40, 76, 88) outside the main WiFi frequencies.
    Transmission rate of 1 Mbps (increased for full support of the newer nRF52 generation).
    Constant latency / period of 4.5 ms (222 Hz).
    The received telemetry displays the A1(A2) voltage and RSSI.
    RC channel settings from 2 to 14.
    By selecting the "bnd" bind option in the model settings menu, we save the failsafe servo
    positions into the receiver.
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2026-11-06 Simu compilation issue
    switch PROTO_Change_Callback() NO inline
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2026-11-07 New QR code add (#108)
    - QR code build with last GPS position (push QR button)
    - If no GPS found a popup with NO GPS FIX appear
    - add multi language
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2026-11-08 CRSF TXC use (#111)
    The CRSF half-duplex turnaround was changed to use the USART TX Complete (TXC) event.
    Previously, the code could release the UART as soon as the transmit buffer was empty, while the final byte was still being shifted out on the wire.
    Now, CRSF keeps the UART in transmit mode until TXC confirms that the last stop bit has actually been sent. Only then is the line released and the receiver re-enabled.
    This gives a cleaner half-duplex turnaround and reduces the risk of missing or corrupting the first bytes of the telemetry response.
2026-11-09 Update pulses_avr.cpp
    Changed to use Pullup resistors because we use non-inverted serial for half-duplex CRSF.
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

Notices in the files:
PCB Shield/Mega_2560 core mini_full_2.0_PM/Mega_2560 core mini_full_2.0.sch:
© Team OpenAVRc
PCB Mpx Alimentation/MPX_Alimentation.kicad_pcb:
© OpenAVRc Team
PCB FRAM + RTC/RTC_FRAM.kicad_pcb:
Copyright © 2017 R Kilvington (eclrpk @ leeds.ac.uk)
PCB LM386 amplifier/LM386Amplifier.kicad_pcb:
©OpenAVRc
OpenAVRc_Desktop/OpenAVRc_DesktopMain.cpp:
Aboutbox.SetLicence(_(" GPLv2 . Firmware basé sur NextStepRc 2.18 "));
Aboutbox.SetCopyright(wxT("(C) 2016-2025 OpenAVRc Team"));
